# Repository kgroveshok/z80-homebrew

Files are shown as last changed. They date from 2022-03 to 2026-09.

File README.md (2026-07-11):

# z80-homebrew
Z80 Home Brew Micro-computer Project
------------------------------------

Having watched so many retro computing videos on YouTube I thought I would relive some of my youth
by building something simple. I remember the old electronic magazines of the 1980's which 
had plenty of simple programmable computing devices to make at home.  Always wanted one. Now I
will do it - only a few decades behind :-)

6502 vs Z80
-----------

My first home computer was a Vic20. Not long after having that in my grubby mitts I was writing
6502 machine code, hand assembling as we all did back then. Later I moved onto an Amstrad CPC464
and dived into Z80 which I then took to the Amstrad PCW 512.

Looking around at parts I found it hard to locate any good 6502 parts and with the vast
Z80 community and lots of great material to dust off my rusty electronics skills I chose that.

Therefore this project, is Z80 based. Turns out that is a good choice as the arch is very simple
with a load of great chips that tie closely together. Makes for an easier life.

Update: That said, with the PDIP Z80 now out of production so so great... But not completely lost :-)

Design Brief
------------

I thought I would add where I feel the design ideas have come from. First I love the Forth language
therefore as I say above taking the idea of the language driving the OS like in the Jupiter Ace, also
I love that case design, low profile, Sinclair like. Back in the day I had a ZX81 (which I still have)
but I also always wanted a Sharp handheld, saw one at school and thought such a cool thing, hence the 
completely self contained LCD display choice I went with. 

And working in a computer shop around 1987/88 I got to see a lot of different home micros and loved the
design of the Oric and MSX. I think my next 3D case I will print black and do orange/red keys.

Of course with the new 4.5 design I'm adding some features to make things easier such as Wifi. Hopefully
the tape interface will work though I've still got to finish writing the loading decoder. Saving was
working in the prototype.

Current Specification/Feature Set
---------------------------------

* Z80 4/8/10MHz
* 32K ROM
* 32K RAM
* PIO 1: Port A & B - Controlling LCD and keyboard:
   - Mini: 20x4 LCD and 4x4 matrix keypad 
   - Mega: 20x4 or 40x4 LCD and 50 key matrix keyboard
* PIO 2: Port A - Persistent storage via Microchip serial EEPROMs. 
   - Max 320K on board (5 x 64k). Currently set for 32k x 5. 
   - Uses own file system with max file size of 16k 
   - 5 banks of independant storage each with own bank label
* PIO 2: Port B - Exposed 8 bit bus and SPI bus. Used for more storage (512k/1024k), SPI devices or digital I/o
   - SPI0 - RJ45 socket configured for use with SPINet Add-on
   - SPI1 - ESP32 S3 for use as Wifi/extra storage/external comms, etc
* A 595 shift register bus array for any random junk you want to push such as a load of LED's or digital output on device G.
* Auto startup scripts/demos built into ROM and/or created on storage.
* Exposed RC2014 connector
* Built-in address decoder for four devices (2 used above)
* Tape support in progress on Device F.
* On board sound support on device B.
* Feature to load a user dictionary from file storage at boot time
* Highlevel and low level storage words
* Hardware abstraction layers to allow for common entry points and drivers for different keyboards, screens, etc
* Multiple selectable frame buffer support (currently three)
* Built-in Forth OS (inspired by Jupiter Ace). Language defintion and progress etc in FORTH.md
* Built-in full monitor for break points at all key points.
* Using my own very simple malloc/free routinues or can switch to DK88 project version with defines
* 3d printed case designs in 'case' directory.
* To aid in board development and speed up the change and test cycle I've now added support for running on the wonderful Steven Cousin's SC114 board. This is quicker than having to remove the EEPROM (even in a zif socket), burn it and put it back.
* Added CP/M support for even quicker test cyles via RunCPM!

Expansions/Addons
-----------------

* Not something I made, but an Adafruit Boost for on the go computing. Fits the case design on the right hand side. Should document that at some point.
* PicoSPINet - A Pico device which provides 5/6 SPI network ports allowing intercoms between nodes and act as an internet gateway.
   - Provides NTP services
   - Internode communications
   - Internet communications
   - Storage services
   - Powered nodes
   - Emulates the EEPROM used for onboard storage with node specific and common storage banks

   For more details look at the Addons README



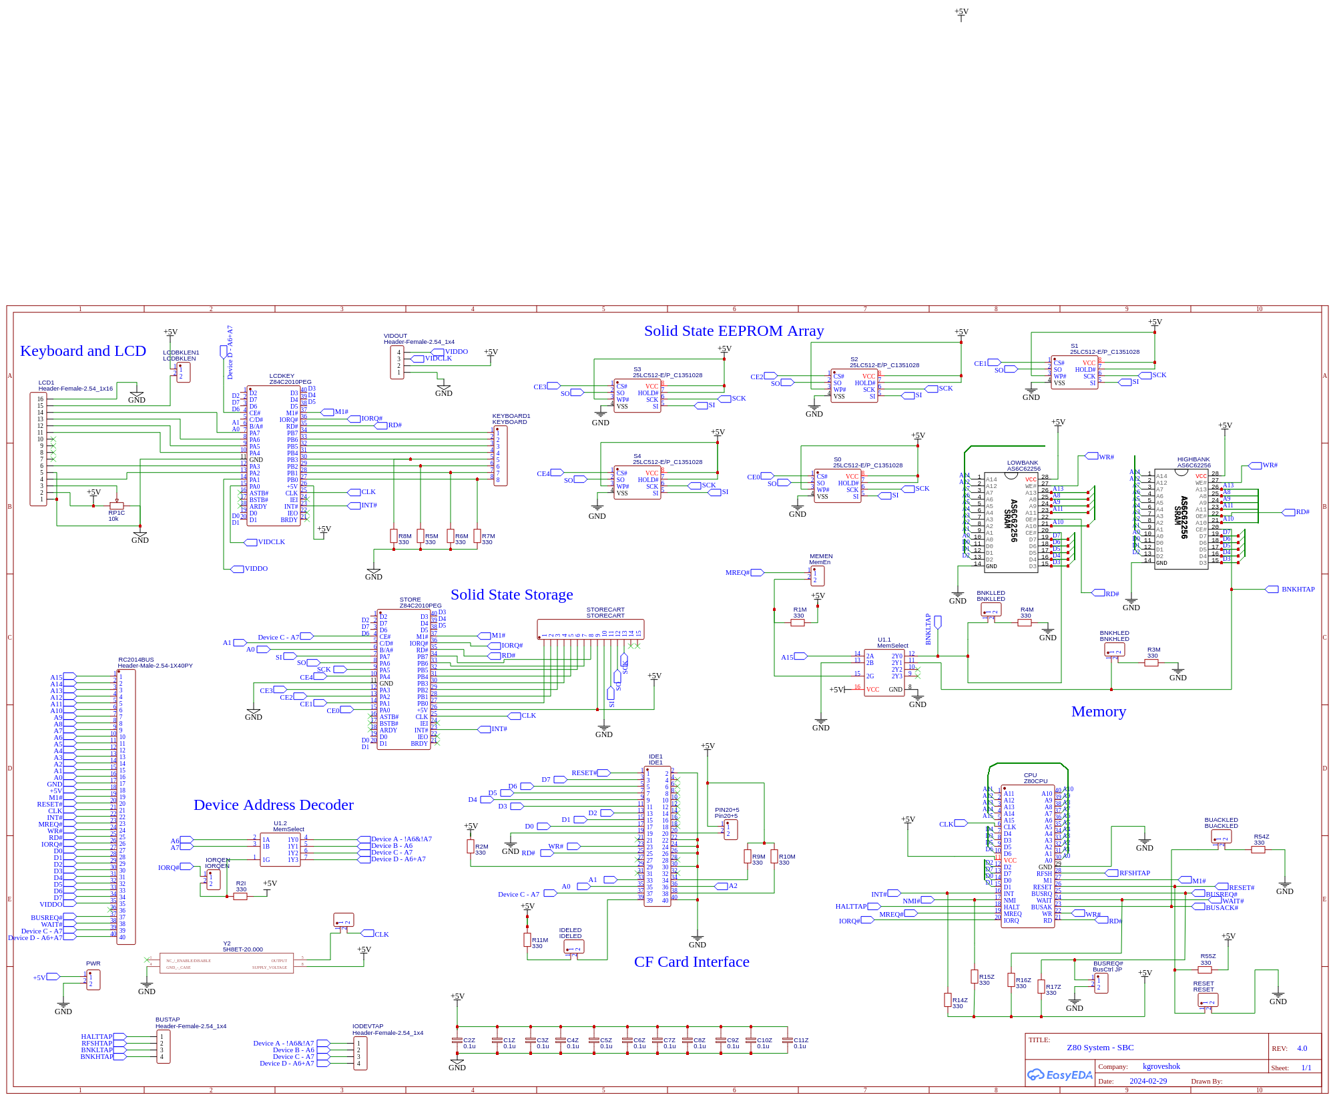
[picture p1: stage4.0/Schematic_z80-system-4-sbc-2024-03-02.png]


* SPISound - Using a shift reg and the classic SN76489 sound chip we have four channel sound via SPI.

   For more details look at the Addons README

Progress
--------

Check the DEV-DIARY.md for progress and what I learnt - spoiler, it is a lot!

Stage 1.x was very very basic using a Microchip PIC to bitbash code into RAM or manually as I didn't have an EEPROM programmer.

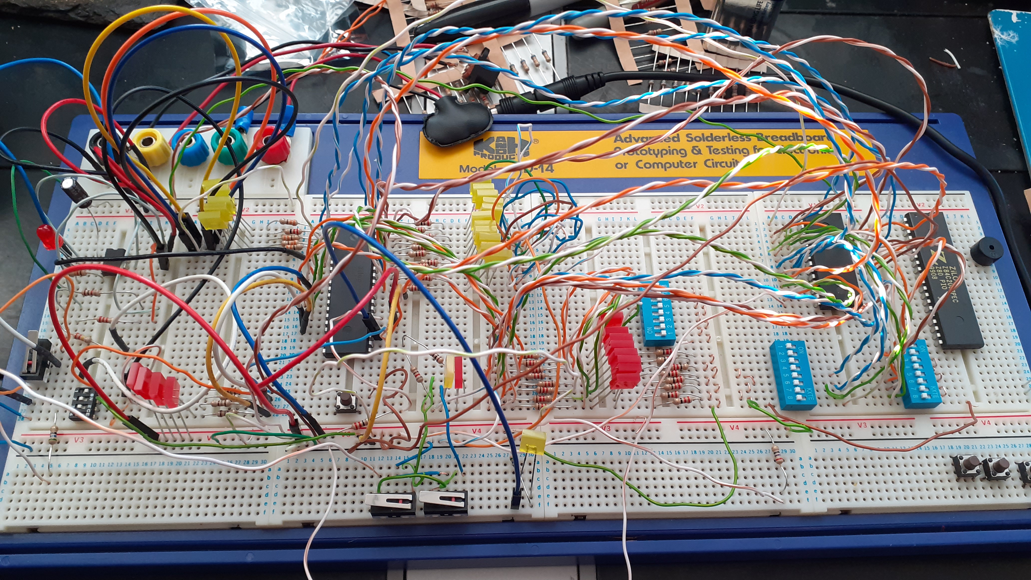
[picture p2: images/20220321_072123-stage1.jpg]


Stage 2.x got us to strip board in varying degrees of success

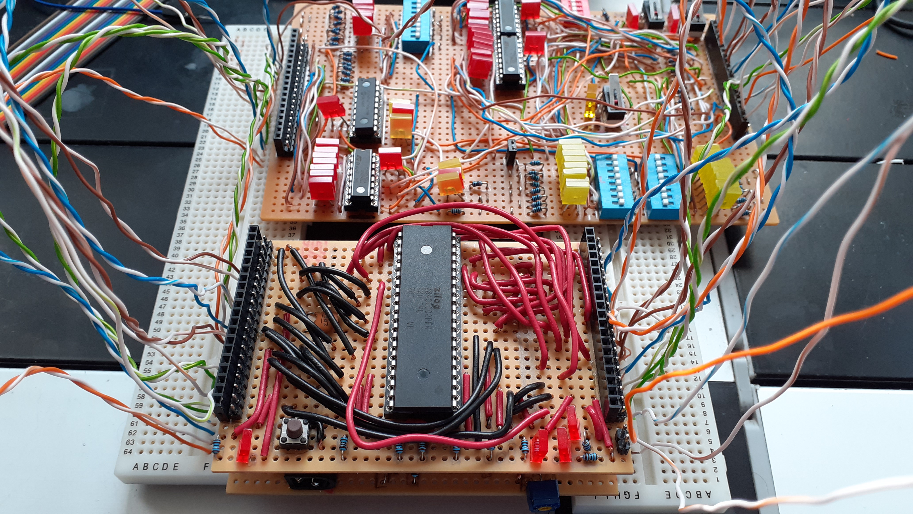
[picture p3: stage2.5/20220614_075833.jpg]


Stage 3.x with a propper PCB things are much more stable (and faster clock freq)...

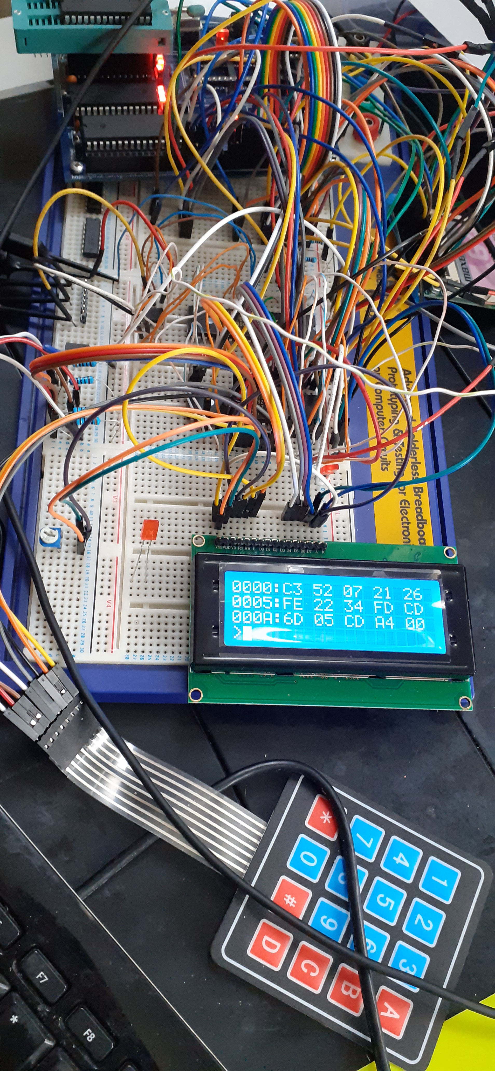
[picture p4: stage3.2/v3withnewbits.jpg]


Stage 4.x a useable machine now with many expandable features.

Current Forth word list in WORD-LIST.md along with how I have put together my version of FORTH in FORTH.md.

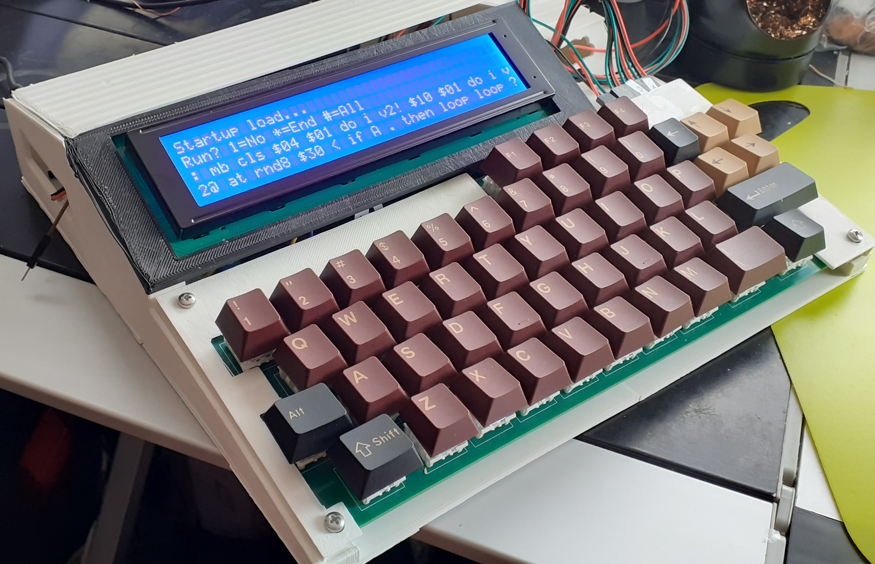
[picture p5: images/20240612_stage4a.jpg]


Stress testing FORTH OS

[https://youtu.be/hWfx7d5nqZw]

Stage 4.5 in June 2026 now has tape, sound, shift reg bus, and an ESP 32 on board!

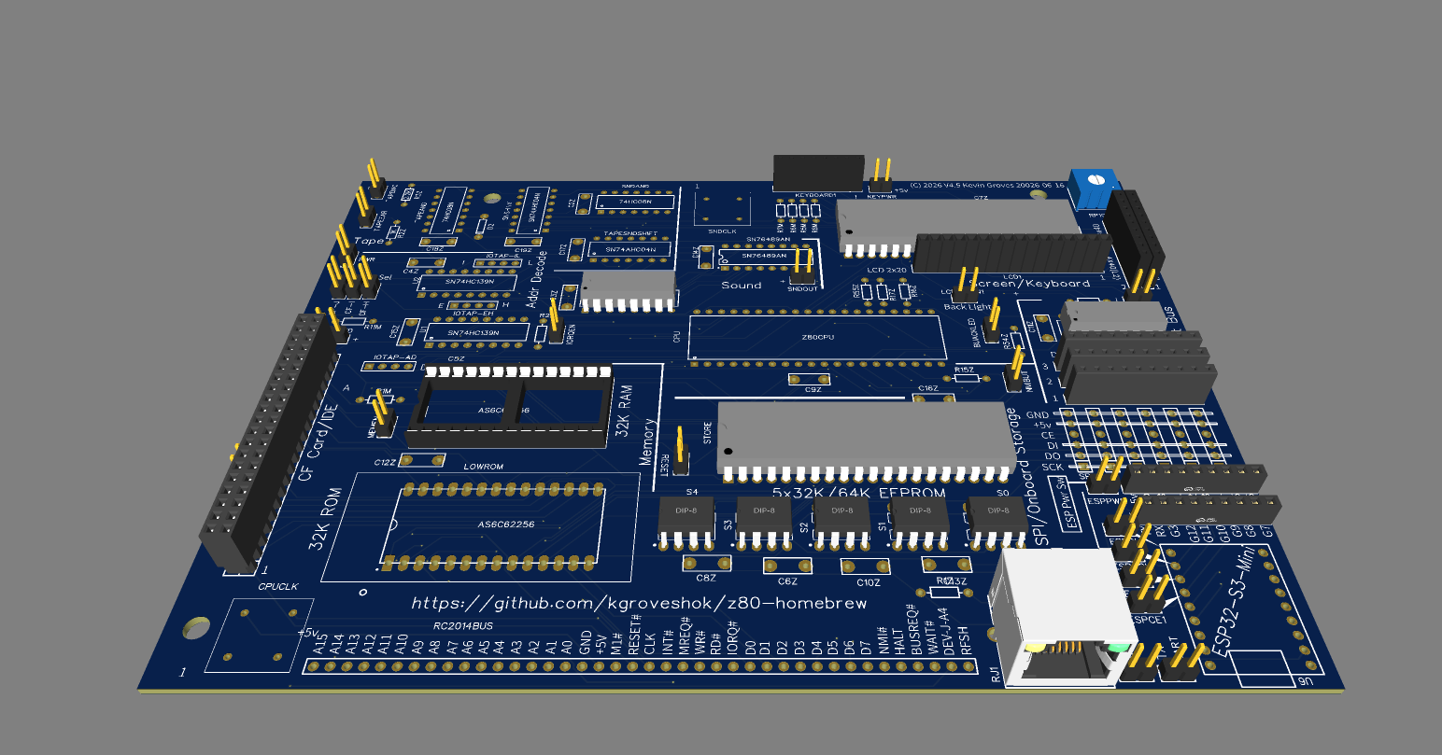
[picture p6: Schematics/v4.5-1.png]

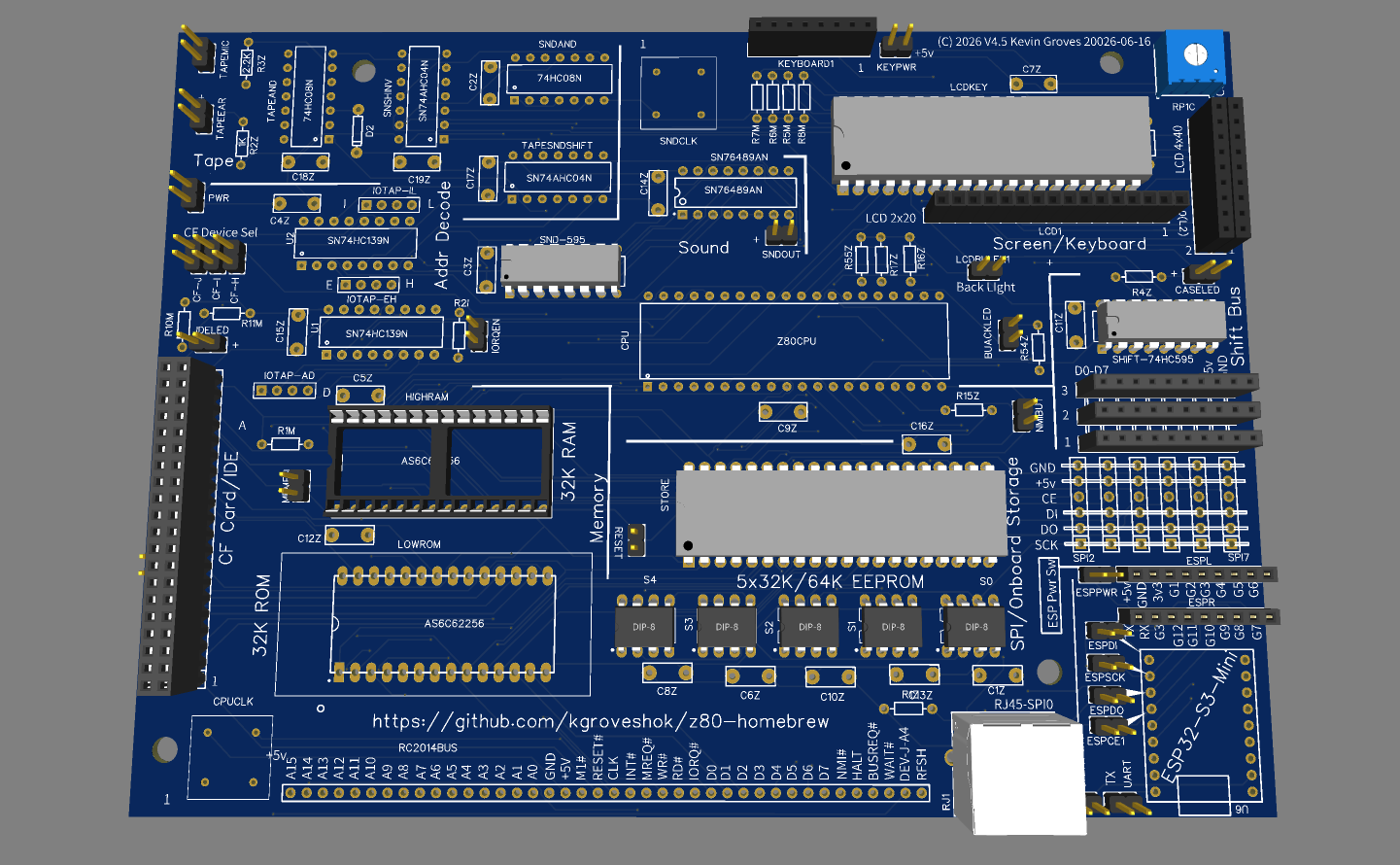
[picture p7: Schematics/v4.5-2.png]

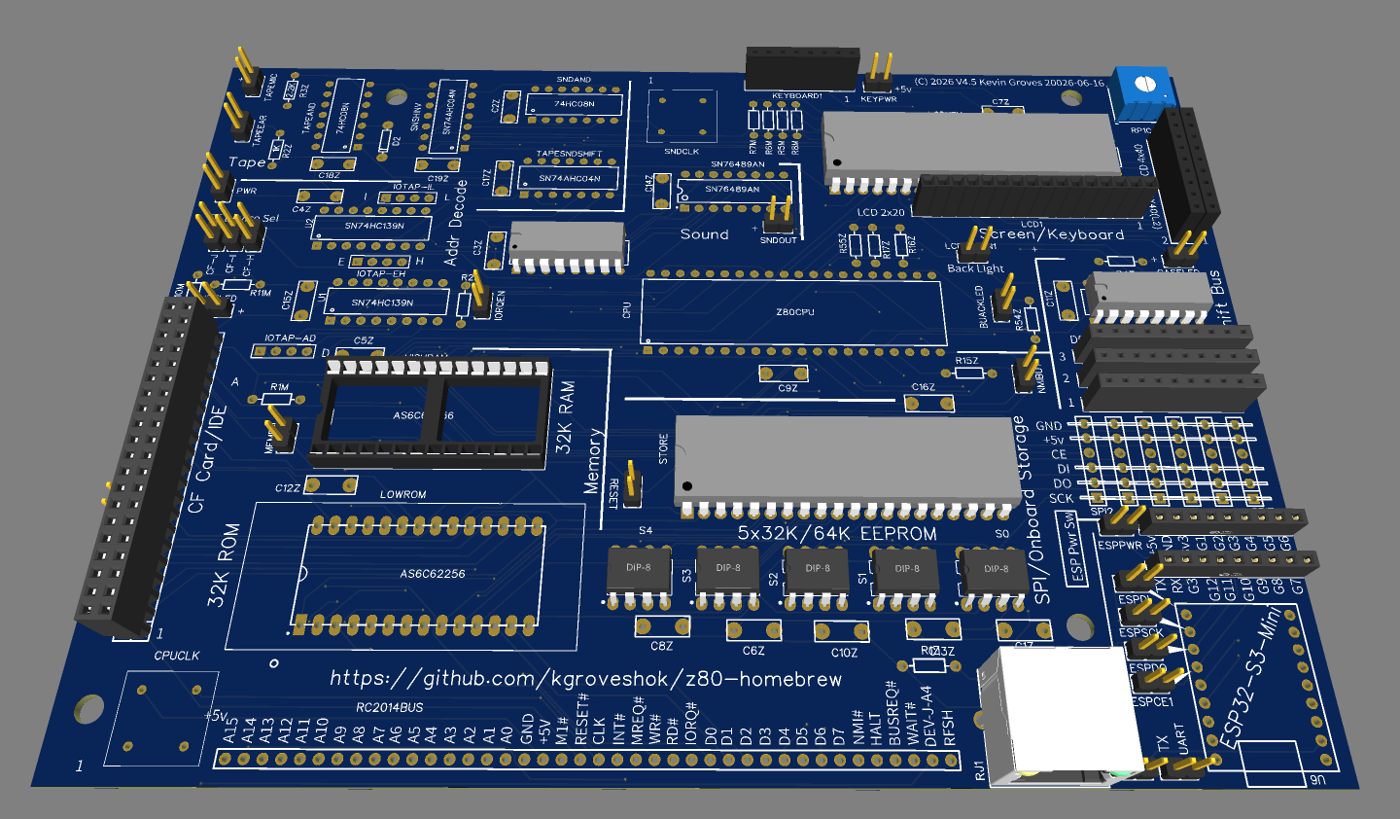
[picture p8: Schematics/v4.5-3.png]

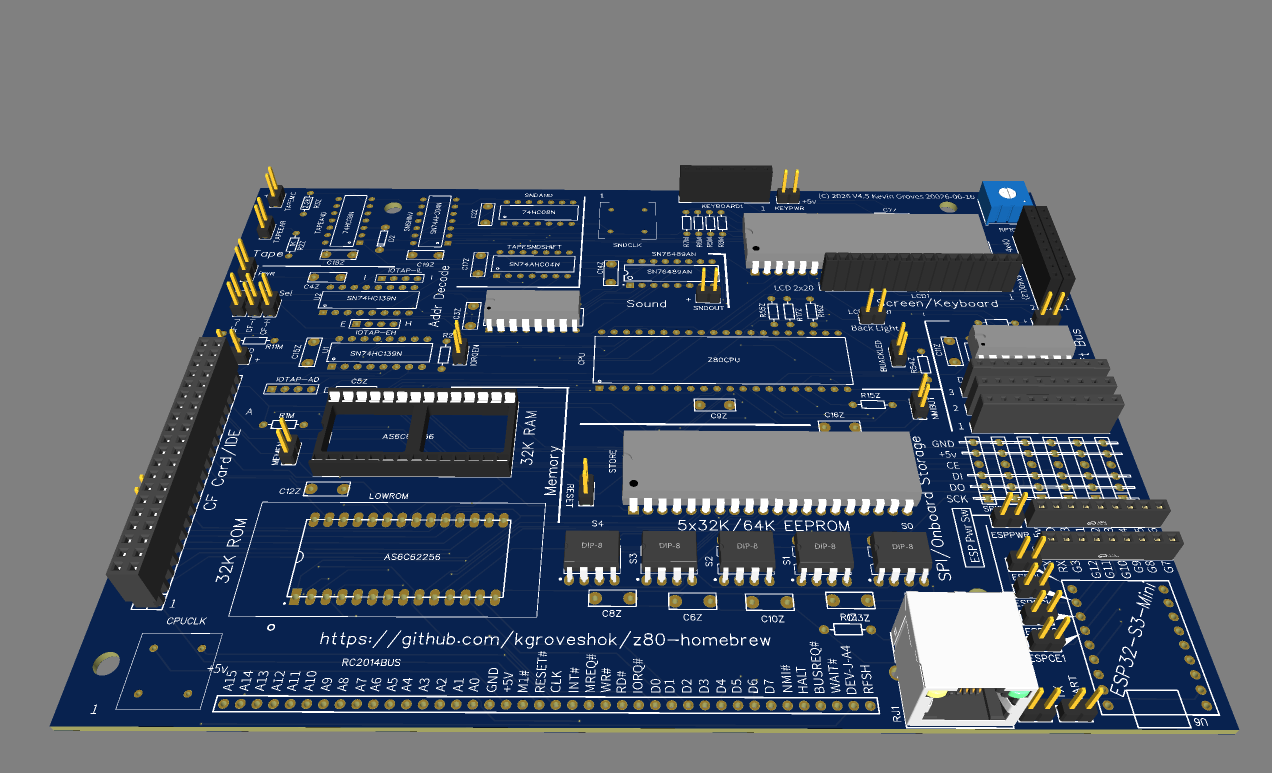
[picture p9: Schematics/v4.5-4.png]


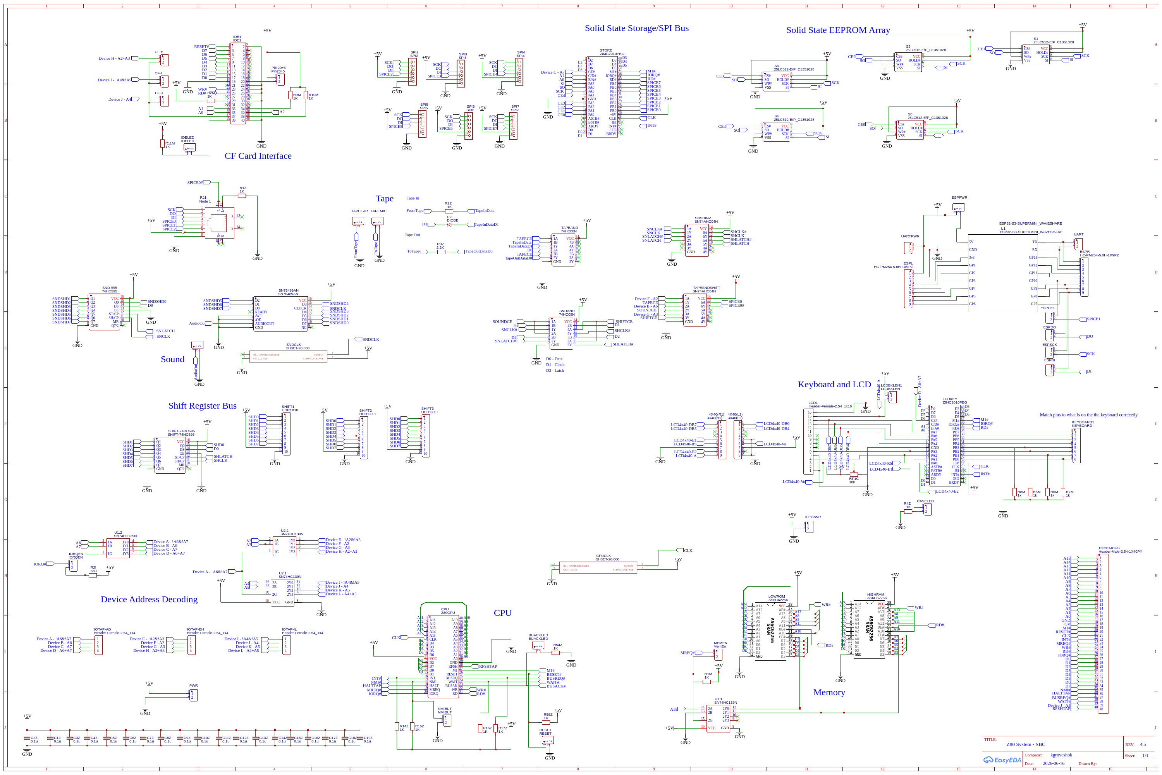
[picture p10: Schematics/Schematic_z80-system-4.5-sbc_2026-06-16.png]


Should fit in the existing case, but will redesign for a sleaker look like this...

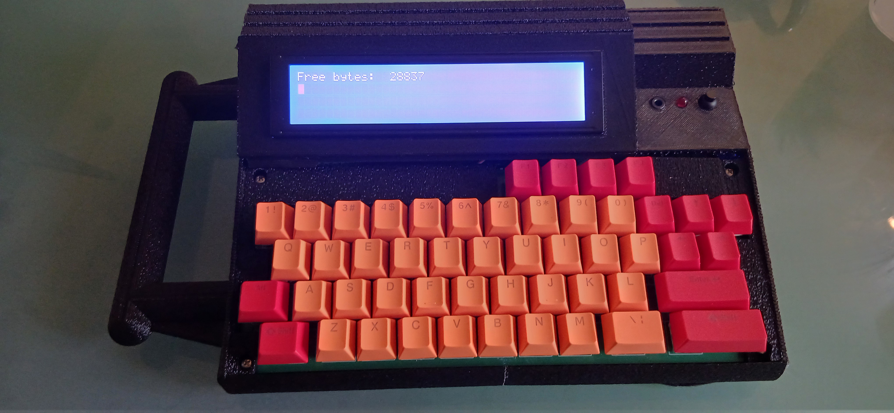
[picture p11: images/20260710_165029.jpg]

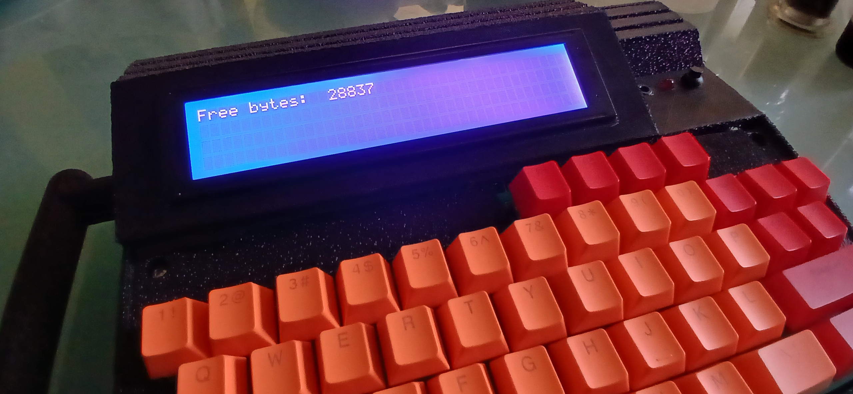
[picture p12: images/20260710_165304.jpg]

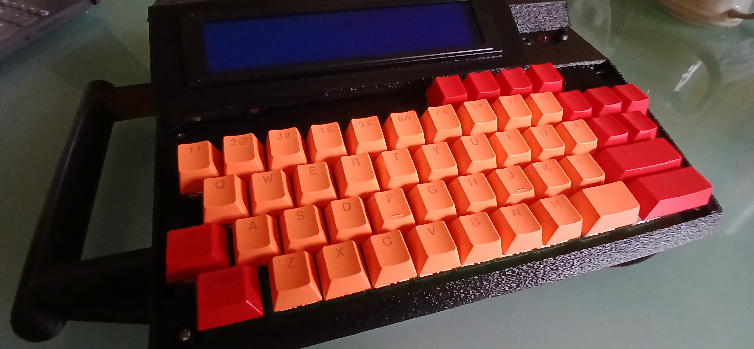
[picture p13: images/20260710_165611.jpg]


I was aiming for an Oric/MSX like colour scheme. Always wanted one of those back in the day.

A simple game of 'Simon Says'
-----------------------------

```
: sgen #1 do #1 #5 rnd dup #48 + i scratch ! .> bl .> loop ;
: isay #1 #0 scratch ! ; 
: nsay #0 scratch dup 1+! @ ;
: tsay #4 pause cls Your-go .- #10 #1 at accept ;
: schk #1 scratch #0 #0 scratch @ substr swap drop compare ;
: bsay "Your best was" #0 scratch @ #1 - num2str info ;
: ssay isay repeat cls nsay sgen tsay schk #1 = until bsay ;
```

[https://www.youtube.com/watch?v=0pCNQlxzYs0]

Parts
-----

At each stage I will document and attach the schematics for mostly for my own reference should things go wrong.

References
----------

I found so much great advice and inspiration around the net here are some of those that made the most
impact (in no particular order):

* [https://maker.pro/pic/projects/z80-computer-project-part-1-the-cpu]
* [https://www.electromaker.io/blog/article/z80-computer-memory]
* [https://www.youtube.com/watch?v=yR566HNj0ao]
* [https://bread80.com/category/couch-to-64k/]
* [https://maggi9295.github.io/projects/z80computer/z80computer.html]
* [http://www.breakintoprogram.co.uk/projects/homebrew-z80/homebrew-z80-computer-part-1]
* [https://incoherency.co.uk/blog/stories/rc2014-frontpanel.html]
* [https://www.instructables.com/An-Easy-to-Build-Real-Homemade-Computer-Z80-MBC2/]
* [https://sites.google.com/view/erics-projects/z-80-projects-page/z-80-pio-ps2-keyboard-interface]
* [http://www.cpuville.com/Projects/Standalone-Z80-computer/Standalone-Z80-home.html]
* [http://www.blunk-electronic.de/train-z/]
* [http://www.friendlywire.com/tutorials/pic-flash/]
* [http://www.waveguide.se/?article=programming-pics-using-the-pickit2-and-pk2cmd]
* [https://microcontrollerslab.com/74hc595-shift-register-interfacing-pic-microcontroller/]
* [https://www.electroschematics.com/multiple-shift-registers-arduino-part-1/]
* [https://z80project.wordpress.com/2015/07/06/z80-8-bit-compact-flash-card-interface-part-1/]
* [https://ciernioo.wordpress.com/2015/02/10/compact-flash-8255-interface-card/]
* [http://www.luke.maurits.id.au/projects/computers/lm512/]
* [https://github.com/monsonite/MINT]
* [https://github.com/antbern/z80-monitor]
* [https://github.com/fiskabollen/z80Monitor]
* [https://github.com/chapmajs/glitchworks_monitor]
* [http://ve7it.cowlug.org/cpm-monitor.html]
* [https://www.instructables.com/Z80-Monitor-Type-Operating-System-and-SBC/]
* [http://www.vaxman.de/projects/tiny_z80/]
* [https://smallcomputercentral.com/]
* [https://rc2014.co.uk/]

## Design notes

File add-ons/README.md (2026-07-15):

Add-ons/Expansion For Mega 
--------------------------

PicoNET - Wifi adaptor and/or networking hub
SPISound - A SPI controled sound card using a SN76389AN chip
ESP32Wifie - For the 4.5 version of the PCB we now have an onboard ESP handling extra storage and external comms

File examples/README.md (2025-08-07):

Examples
--------

There is a backup.txt file here which is a recent dump over PicoSPINet of my current development of words for use with the addons.

Of point is at the bottom with the various UBI... words which is incremental changes I made to dump the user dict over PicoSPINet to my laptop.

Each change I made I appended to a file and made it auto load so I can test it and not have to write it down. Now I have reached the working
version of UBIALL which works to connect to my laptop and dump the source of all current user words. Each word is displayed and then sent:

 ```
 piconet           <- Switches on the SPI device
 "192.168.9.110:8000" soccon       <- Tell PicoSPINet to make a socket connection to my laptop
 uwords ubiall                <- Push al user words to stack and then iterate over the list sending them via the socket connection via SPI
 ```

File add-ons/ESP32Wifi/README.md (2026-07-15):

ESP32Wifi
---------

With the 4.5 board revision I've added an ESP32 Zero device to provide a number of features. It is communicated via the SPI device 1. Device 0 
continues support for SPINet in case that is useful for wired networking once the code base has been resolved.

As this device is a one to one connection for an IP network, that simplifies the range of features it needs to have.

Programming can be one of three options on the ESP.
1. Using C via the main SDK
2. Arduino code
3. ESPForth

I will give ESPForth a go first. A bit of a learning curve but considering the OS is in Forth then why not have all of it in the same
language? We will see. :-) 

As it happens, had issues with ESPForth and the ESP S3 Zero I'm using. Wouldn't conenct to Wifi with: wifi z" <ssid>" z" <pass>" login

Would just hang. The Arduino IDE wifi SDK is working so will be using that instead as the code is easy to port between that and Forth. May revisit as some time.

* TODO Could add mailbox on web server
* TODO Can I get esp to send email
* TODO Set output pin to input to force high imped and to not corrupt the SPI bus once done.
* TODO setup inter-esp comms for a mesh network to share files
* TODO Put a scope on the SPI lines and decode what is going wrong with EEPROM support

SPI Command Protocol
--------------------

The revised protocol functions at two levels. There is a main class of command byte e.g. wifi services, and then a sub command byte which gives the function.

Please look at the esp-spi-op.h file for the function list. Once it has become stable then a more detailed version will be included here.

ESP Command Operators
----------------------

To aid in removing duplicate code I have implemented an "interpreter" that has a number of simple op codes (see esp-z80-op.h) that form simple features common to all commands e.g. get a byte, put a byte, store something, etc

Likewise from above, once the OP code list has become stable then there will be more detail here. But the naming should be fairly easy to understand.

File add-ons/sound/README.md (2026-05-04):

On Board Sound
--------------

The SPI sound add-on is OK. But would be better if on the main board. With tape support in progress there is only one 
device remaining free without any additional address decoding logic.

Will attempt another go at hooking up the sound chip to device B and including on the main board.

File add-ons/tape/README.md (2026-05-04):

Tape Format
-----------

Trying a combination of pulse counts vs pulse lengths.

As this platform is inspired by the Jupiter Ace then would seem natural to use the ZX-81 tape approach, though it is the most 
unreliable one being just an RC circuit rather than making use of something like KCS or other reliable frequency detection
circuits.

It is a very easy circuit to put together but requires a tight firmware loop for decoding. I had hoped to provide a
Forth implentation but due to interp and guard rails in the OS it isn't fast enough. But there is a TAPESET word that
will allow tweaking for the params.

Objective is to have some words that can save random strings (which could be uwords) as well as a whole user 
dicitionary dump to tape.

Prototype
---------

The add-on for the moment will remain as a strip/bread board solution and once reliable enough (within reason) 
I will include on the main board as the board needs reworking from previous changes.

Development/Testing
-------------------

When time allows samples and screen shots of development will be included.

For source see firmware_tape.asm

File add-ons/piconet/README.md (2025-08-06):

PicoSPINet
----------

* PicoSPINet - A Pico device which provides 5/6 SPI network ports allowing intercoms between nodes and act as an internet gateway.
   - Provides NTP services
   - Internode communications
   - Internet communications
   - Storage services
   - Powered nodes
   - Emulates the EEPROM used for onboard storage with node specific and common storage banks

More to come with PCB design etc

Demo of the prototype:

[https://youtu.be/h5VUJ3j9RmY]

Example comms
-------------

* Connecting to a remote server

 On remote machine:    nc -klv 192.168.9.101 8000

 On Mega:

    * Create socket connection

    $22 spio "192.168.9.101:8000" spistrz 

    * Send ASCII char $65

    $20 spio $65 spio

    * Get back a character from the remote machine

    $21 spio $01 pause spii emit

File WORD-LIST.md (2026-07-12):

# Forth Language Reference

Also refer to the auto start list examples as these contain extra words created at runtime as needed
## Constants (i.e. Useful memory addresses that can set or get features)
### SPITIME ( -- u1 )   Pushes address of the SPI pulse counter/delay to stack | DONE
 If using BANK devices then leave as is.
 Only really useful for the CARTDEV where other devices may be far too slow. In particular
 the multiplexing of the PicoSPINet addon which might not be running fast enough for all of the nodes
### VA ( -- u1 )   Pushes address of block of memory used for v1..5 | DONE
### SYMBOL ( u1 -- )  Get the address of a system symbol from a look up table to TOS  | DONE

 The value is the number reference and the final address is pushed to stack
 ```
 dw sym_table
 dw nmi_vector
 dw cli_autodisplay
 dw cli_data_sp
 dw cli_data_stack
 dw cli_loop_sp
 dw cli_loop_stack
 dw cli_var_array
 dw cursor_col
 dw cursor_ptr
 ; 10
 dw cursor_row
 dw debug_mark
 dw display_fb0
 dw display_fb1
 dw display_fb2
 dw display_fb3
 dw display_fb_active
 dw execscratch
 dw f_cursor_ptr
 dw hardware_word
 ;20
 dw input_at_cursor
 dw input_at_pos
 dw input_cur_flash
 dw input_cur_onoff
 dw input_cursor
 dw input_display_size
 dw input_len
 dw input_ptr
 dw input_size
 dw input_start
 ; 30
 dw input_str
 dw input_under_cursor
 dw os_cli_cmd
 dw os_cur_ptr
 dw os_current_i
 dw os_input
 dw os_last_cmd
 dw os_last_new_uword
 dw debug_vector
 dw os_view_hl
 ;40
 dw os_word_scratch
 dw portbctl
 dw portbdata
 dw spi_cartdev
 dw spi_cartdev2
 dw spi_clktime
 dw spi_device
 dw spi_device_id
 dw spi_portbyte
 dw stackstore
 ; 50
 if STORAGE_SE
 dw storage_actl
 dw storage_adata
 else
 dw 0
 dw 0
 endif
 dw storage_append
 if STORAGE_SE
 dw storage_bctl
 else
 dw 0
 endif
 dw store_bank_active
 dw store_filecache
 dw store_longread
 dw store_openaddr
 dw store_openext
 dw store_openmaxext
 ; 60
 dw store_page
 dw store_readbuf
 dw store_readcont
 dw store_readptr
 dw store_tmpext
 dw store_tmpid
 dw store_tmppageid
 dw malloc
 dw free
 dw cin
 ; 70
 dw cin_wait
 dw forth_push_numhl
 dw forth_push_str
 dw parse_vector
 dw tape_port
 ```
## Core Words
### NMICLR ( -- ) Clears the use of the NMI switch | DONE
### NEW ( -- ) Clears all user words and stack | DONE
### HEAP ( -- u1 u2 )   Pushes u1 the current number of bytes in the heap and u2 the remaining bytes - Only present if using my MALLOC | DONE
 u1 - Current number of bytes in the heap
 u2 - Remaining bytes left on the heap
 
 The heap is used for storing user defined words as well as any values pushed to stack.
### DUP ( u -- u u )     Duplicate whatever item is on TOS | DONE
 >[!NOTE]
 > If the duplicated item is a string it is safely duplicated
### ?DUP ( u -- u u )     Duplicate item on TOS if the item is non-zero (Only works for numerics) | DONE
 >[!NOTE]
 > If the duplicated item is a string it is not safely duplicated and remain as pointer to the origin
### DMARK ( s --  )  Set the debug marker id to first three chars of s | DONE
 Most useful for tracing your code for errors as you can set various markers to display when MONITOR is called
### LSHIFT ( w -- w )    16 bit left shift | DONE
### RSHIFT ( w -- w )    16 bit right shift | DONE
### SWAP ( w1 w2 -- w2 w1 )    Swap top two items on TOS | DONE
### : ( -- )         Create new word | DONE
### ; ( -- )     Terminate new word and return exec to previous exec level | DONE
### DROP ( w -- )   drop the TOS item   | DONE
### 2DUP ( w1 w2 -- w1 w2 w1 w2 ) Duplicate the top two items on TOS  (Only works for numerics) | DONE
 >[!NOTE]
 > If the duplicated items are string pointers, string are not safely duplicated and remain as pointers to the origin
### 2DROP ( w w -- )    Double drop | DONE
### PICK ( ux ... u x -- ux ... u n )    Replace x on stack with the item from position x on stack  | DONE
 >[!NOTE]
 > If the chosen item is a string the pointer is pushed to TOS. The string is not safely duplicated.
### 2SWAP ( w1 w2 w3 w4 -- w3 w4 w1 w2 ) Swap top pair of items | DONE
### @ ( w -- ) Push onto TOS byte stored at address   | DONE
### C@  ( w -- ) Push onto TOS byte stored at address   | DONE
### ! ( x w -- ) Store x at address w      | DONE
### C!  ( x w -- ) Store x at address w  | DONE
### CALL ( w -- w  ) machine code call to address w  push the result of hl to stack | DONE
### DEPTH ( -- u ) Push count of stack | DONE
### OVER ( n1 n2 -- n1 n2 n1 )  Copy one below TOS onto TOS | DONE
 >[!NOTE]
 > If the copied item is a string it is properly duplicated allowing for a safe release after use. 
### PAUSEMS ( n -- )  Pause for n millisconds | DONE
### PAUSE ( n -- )  Pause for n seconds | DONE
### ROT ( u1 u2 u3 -- u2 u3 u1 ) Rotate top three items on stack | DONE
### UWORDS (  -- s1 ... sn u )   List user word dict | DONE
 After use the TOS will have a count of the number of user words that have been pushed to stack.
 Following the count are the individual words.

 e.g. UWORDS
 BOX DIRLIST 2
 
 Can be used to save the words to storage via:
 UWORDS $01 DO $01 APPEND LOOP
### BP ( u1 -- ) Enable or disable break point monitoring | DONE
 $00 Will enable the break points within specific code paths
 $01 Will disable break points
 
 By default break points are off. Either the above can be used to enable them
 or if a key is held down during start up the spashscreen will appear to freeze
 and on release of the pressed key the CONFIG menu will be displayed where you
 can disable break points. Exiting will then continue boot process.
### MONITOR ( -- ) Display system breakpoint/monitor | DONE
 At start the current various registers will be displayed with contents.
 Top right corner will show the most recent debug marker seen.
 The bottom of the screen will also show the values of the data stack pointer (DSP)
 and the return stack pointer (RSP).
 Pressing:
 
    1 - Initial screen
 
    2 - Display a data dump of HL
 
    3 - Display a data dump of DE
 
    4 - Display a data dump of BC
 
    5 - Display a data dump of HL
 
    6 - Display a data dump of DSP
 
    7 - Display a data dump of RSP
 
    8 - Display a data dump of what is at DSP
 
    9 - Display a data dump of what is at RSP
 
    0 - Exit monitor and continue running. This will also enable break points
 
    * - Disable break points
 
    # - Enter traditional monitor mode

 Monitor Mode
 ------------
 A prompt of '>' will be shown for various commands:
 
    D xxxx - Display a data dump starting from hex address xxxx
 
    C - Continue display a data dump from the last set address
 
    M xxxx - Set start of memory edit at address xx
 
    U xx - Poke the hex byte xx into the address set by M and increment the address to the next location
 
    G xxxx - Exec code at specific address
 
    Q - Return to previous
### ALLOT ( u -- u ) Allocate u bytes of memory space and push the pointer TOS  | DONE
### MALLOC ( u -- u ) Allocate u bytes of memory space and push the pointer TOS  | DONE
### FREE ( u --  ) Free memory block from malloc given u address  | DONE
### UPTR ( s -- u ) Push the address of the exec code for the quoted used word s  | DONE
### LIST ( uword -- u )    List the code to the word that is quoted (so as not to exec) on TOS | DONE
 The quoted word must be in upper case.
### FORGET ( uword -- )    Forget the uword on TOS | DONE
 Will flag the word's op code to be deleted as well as replace the first char of the word with '_'. Quoted uword name must be in caps.
 
 e.g. "MORE" forget
### NOP (  --  ) Do nothing | DONE
### ( ( -- )  Start of comment | DONE
### ) ( -- )  End of comment |  DONE 
### SCRATCH ( u -- addr ) Pushes address of offset u to stack | DONE
 The scratch area provides 32 word array. Can be used as single byte or as a word by passing the offset on stack. Pushes the resulting address to stack. 
 When used with the direct storage writing/malloc and the !@ or word versions it is possible to construct an expanded and flexible variable system
 
 e.g.    : score $00 scratch ;
 
 $00 score !
 $01 score +!
 
 e.g.   : varword $0a scratch ; 

 $8000 varword !
### +! ( u a -- )  Increment byte at address a by the value u | DONE
### -! ( u a -- )  Decrement byte at address a by the value u | DONE
### +2! ( u a -- )  Increment word at address a by the value u | DONE
### -2! ( u a -- )  Decrement word at address a by the value u | DONE
### 2@ ( a -- u )  Push word at address a onto stack | DONE
### 2! ( u a -- )  Store value u as a word at address a | DONE
### CONFIG ( -- )  Access the system configuration menu. Set boot from file, hardware diags, and more! | DONE
### 1+ ( u -- u )  Increment value on TOS | DONE
### 1- ( u -- u )  Decrement value on TOS | DONE
### 1+! ( addr -- )  Increment byte at address addr | DONE
### 1+2! ( addr -- )  Increment word at address addr | DONE
### 1-! ( addr -- )  Decrement byte at address addr | DONE
### 1-2! ( addr -- )  Decrement word at address addr | DONE
## Device Words
### DEVSAV ( --  )  Saves the current BANK/CARTDEV settings in case you want to switch device suddenly. i.e. use ESP | DONE
### DEVREST ( --  )  Restores the last saved BANK/CARTDEV settings in case you want to switch device suddenly. i.e. use ESP | DONE
### SR ( u p --  )  Send byte u to shift reg on port p | DONE
### LED ( u --  )  Set case LED on or off | DONE
### NB ( u --  )  Sends a note byte to sound card  TODO
### SETTAPE ( port gap samples hpulse lpulse high low -- )   Set parameters for tape support | DONE
 port - Device address port; default is Device A on 00h
 samples - How many sample cycles to count pulses
 gap - Gap period counter; default is 250
 hpulse - Count of pulses for 1; default is 6
 lpulse - Count of pulses for 0; default is 2
 high - High bit period counter; default is 150
 low - Low bit period counter; default is 50
### SAVES ( s1 ... sn c n -- )    Save a count of c strings using file name of n to tape | DONE
### SAVE ( n -- )    Save all uuser words to tape with given name n | TO DO
### LOAD ( n -- )    Load file n from tape and exec | TO DO
### TAPECAL (  -- )    Listen to a tape header and report on bit detection pulses | TO DO
### TAPETEST (  -- )    Record a repeating stripe pattern of 0 and 1 for testing record and playback via TAPECAL | TO DO
### IN ( u1 -- u )    Perform Z80 IN with u1 being the port number. Push result to TOS | DONE
### OUT ( u1 u2 -- ) Perform Z80 OUT to port u2 sending byte u1 | DONE
### SPICEL ( -- ) Set SPI CE low for the currently selected device |  DONE
### SPICEH ( -- ) Set SPI CE high for the currently selected device |  DONE
### SPIO ( u1 -- ) Send byte u1 to SPI  |  DONE
### SPII ( -- u1 ) Get a byte from SPI  | DONE
### BANK? ( -- u ) Reports on the serial EEPROM Bank Device at bank address u1 1-5.  | DONE
 Zero is disabled storage.
### BANK ( u1 -- ) Select Serial EEPROM Bank Device at bank address u1 1-5 (disables CARTDEV).  | DONE
 Set to zero to disable storage.
### CARTDEV ( u1 -- ) Select cart device 1-8 (Disables BANK). | DONE
 Set to zero to disable devices.
## Display Words
### ACTIVE ( -- s ) Push the next char for an activity indicator to TOS | DONE
 To display a pulsing activity indicator in a processing loop do this...
 e.g. $ff $00 do active . ..... Your code ..... loop
### INFO ( u1 u2 -- )  Use the top two strings on stack to fill in an info window over two lines. Causes a wait for key press to continue. | DONE
### AT? ( -- c r )  Push to stack the current position of the next print | TO TEST
### FB ( u -- ) Select frame buffer ID u (1-3)  |  DONE
 Default frame buffer is 1. System uses 0 which can't be selected for system messages etc.
 Selecting the frame buffer wont display unless automatic display is setup (default).
 If automatic display is off then updates will not be shown until DRAW is used.
###  EMIT ( u -- ) Display ascii character  TOS   | DONE
### .- ( u -- ) Display TOS replacing any dashes with spaces. Means you dont need to wrap strings in double quotes!   | DONE
### .> ( u -- ) Display TOS and move the next display point with display  | DONE
### . ( u -- ) Display TOS. Does not move next print position. Use .> if you want that. | DONE
### CLS ( -- ) Clear current frame buffer and set next print position to top left corner  | DONE
### DRAW ( -- ) Draw contents of current frame buffer  | DONE
### DUMP ( x -- ) With address x display dump   | DONE
### CDUMP ( -- ) Continue dump of memory from DUMP | DONE
### AT ( u1 u2 -- ) Set next output via . or emit at row u2 col u1 | DONE
### HOME ( -- ) Reset the current cursor for output to home | DONE
### CR (  -- s ) Push CR/LF pair onto the stack as a string  | DONE
### BL (  -- c ) Push the value of space onto the stack as a string  | DONE
### SPACES ( u -- str ) A string of u spaces is pushed onto the stack | DONE
### SCROLL ( -- ) Scroll up one line - next write will update if required | DONE
### SCROLLD ( -- ) Scroll down one line - next write will update if required | TO DO
### AT@ ( u1 u2 -- n ) Push to stack ASCII value at row u2 col u1 | DONE
### ADSP ( u1 --  ) Enable/Disable Auto screen updates (SLOW). | DONE
 If off, use DRAW to refresh. Default is on. $0003 will enable direct screen writes (TODO) 
### MENU ( u1....ux n -- n ) Create a menu. n is the number of menu items on stack. Push number selection to TOS | DONE
## Program Flow Words
### IF ( w -- f ) If TOS is true exec code following up to THEN  | DONE
 Note: currently not supporting ELSE or nested IF
### THEN ( -- ) Does nothing. It is a marker for the end of an IF block | DONE
### ELSE ( -- ) Not supported - does nothing | TODO
### DO ( u1 u2 -- ) Loop starting at u2 with a limit of u1 | DONE
### LOOP ( -- ) Increment and test loop counter  | DONE
### I ( -- ) Current loop counter | DONE
### -LOOP ( -- ) Decrement and test loop counter  | DONE
### REPEAT ( --  ) Start REPEAT...UNTIL loop  | DONE
### UNTIL ( u -- ) Exit REPEAT...UNTIL loop if TOS is false  | DONE
## Keyboard Words
### MACRO ( s u -- ) Maps a string s against a key code u for use in the editor functions (CLI/EDIT/ACCEPT)  | TODO
### KEY ( -- u ) A non-blocking read of keypress | DONE
 The ASCII key (or key code) is pushed to stack. If no key is currently held down then push a 0
 Can use something like this to process:
 > repeat active . key ?dup if emit then #1 until 
### KEYDB ( -- u ) A non-blocking read of keypress with key release debounce | DONE
 The ASCII key (or key code) is pushed to stack. If no key is currently held down then push a 0
 Can use something like this to process:
 > repeat active . key ?dup if emit then #1 until 
### WAITK ( -- w ) Wait for keypress TOS is key press | DONE
### ACCEPT ( -- w ) Prompt for text input and push pointer to string | DONE
### EDIT ( u -- u ) Takes string on TOS and allows editing of it. Pushes it back once done. | DONE
### DEDIT ( ptr --  ) Takes an address for direct editing in memory. | DONE
## Logic Words
### AND ( u1 u2  -- u3 ) u3 is logical AND of u1 with u2 | DONE
### OR ( u1 u2  -- u3 ) u3 is logical OR of u1 with u2 | DONE
### NOT ( u  -- u ) Inverse true/false on stack | DONE
### COMPARE ( s1 s2  -- f ) Push true if string s1 is the same as s2 | DONE
### 0< ( u -- f ) Push true if u is less than o | CANT DO UNTIL FLOAT
### 0= ( u -- f ) Push true if u equals 0 | DONE
### < ( u1 u2 -- f ) True if u1 is less than u2 | DONE
### > ( u1 u2 -- f ) True if u1 is greater than u2 | DONE
### = ( u1 u2 -- f ) True if u1 equals u2 | DONE
## Maths Words
### + ( u u -- u )    Add two numbers and push result   | INT DONE
### - ( u1 u2 -- u )    Subtract u2 from u1 and push result  | INT DONE
### / ( u1 u2 -- result remainder )     Divide u1 by u2 and push result | INT DONE
### * ( u1 u2 -- u )     Multiply TOS and push result | INT DONE
### MIN (  u1 u2 -- u3 ) Whichever is the smallest value is pushed back onto the stack | DONE
### MAX (  u1 u2 -- u3 )  Whichever is the largest value is pushed back onto the stack | DONE
### RND16 (  -- n ) Generate a random 16bit number and push to stack | DONE
### RND8 (  -- n ) Generate a random 8bit number and push to stack | DONE
### RND ( u1 u2 -- u ) Generate a random number no lower than u1 and no higher than u2 and push to stack | DONE
## Fixed Storage Words
### RENAME ( s id -- ) With the current bank, rename the file id with the new label s  | DONE
 > [!NOTE]
 > Compatible with PicoSPINet 
### RECORD ( u id -- s ) With the current bank, read record number u from file id and push to stack  | DONE
 > [!NOTE]
 > Compatible with PicoSPINet 
### BREAD ( u -- u ) Lowlevel storage word. With the current bank, read a block from page id u (1-512) and push to stack  | DONE
 > [!NOTE]
 > Compatible with PicoSPINet 
### BWRITE ( s u -- ) Lowlevel storage word. With the current bank, write the string s to page id u | DONE
 > [!NOTE]
 > Compatible with PicoSPINet 
### BUPD ( u -- ) Lowlevel storage word. Write the contents of the current file system storage buffer directly to page id u | DONE
 Coupled with the use of the BREAD, BWRITE and STOREPAGE words it is possible to implement a direct
 or completely different file system structure.
 > [!NOTE]
 > Compatible with PicoSPINet 
### GETID ( s -- u ) Get the file ID in the current BANK of the file named s | DONE
 > [!NOTE]
 > Compatible with PicoSPINet 
### DIR ( u -- lab id ... c t ) Using bank number u push directory entries from persistent storage as w with count u  | DONE
 > [!NOTE]
 > Compatible with PicoSPINet 
### SEO ( u1 u2 -- ) Send byte u1 to Serial EEPROM device at address u2 | DONE
### SEI ( u2 -- u1 ) Get a byte from Serial EEPROM device at address u2 | DONE
### FFREE ( -- n )  Gets number of free file blocks on current storage bank | DONE
 > [!NOTE]
 > Compatible with PicoSPINet 
### SIZE ( u -- n )  Gets number of blocks used by file id u and push to stack | DONE
 > [!NOTE]
 > Compatible with PicoSPINet 
### CREATE ( u -- n )  Creates a file with name u on current storage bank and pushes the file id number to TOS | DONE
 e.g. 
 TestProgram CREATE
 Top of stack will then be the file ID which needs to be used in all file handling words
 
 Max file IDs are 255.
 
 > [!NOTE]
 > Compatible with PicoSPINet 
### APPEND ( u n --  )  Appends data u to file id on current storage bank | DONE
 e.g.
 Test CREATE      -> $01
 "A string to add to file" $01 APPEND
 
 The maximum file size currently using 32k serial EEPROMS using 64 byte blocks is 15k.
 > [!NOTE]
 > Compatible with PicoSPINet 
### ERA ( n --  )  Deletes all data for file id n on current storage bank | DONE
 > [!NOTE]
 > Compatible with PicoSPINet 
### OPEN ( n -- n )  Sets file id to point to first data page for subsequent READs. Pushes the max number of blocks for this file | DONE
 e.g.
 $01 OPEN $01 DO $01 READ . LOOP

 Will return with 255 blocks if the file does not exist
 > [!NOTE]
 > Compatible with PicoSPINet 
### READ ( -- n  )  Reads next page of current file id and push to stack | DONE
 e.g.
 $01 OPEN $01 DO READ . LOOP

 As this word only reads one 64 byte block in at a time, if the APPEND word has created extra blocks for the excess, this READ
 word is unaware so the long string needs to be joined if the string is a full. A single block read might be what you want,
 but if not then writing a word to join blocks will be required. The upshot is a full string will be 62 bytes as the first
 two bytes contain the file id and extent.
 
 Note: There is a flag that enables/disables long block reads called 'store_longread' and a poke of a non-zero value will
 enable the code to automatically read futher blocks if full. It is BUGGY so don't use for now.
 > [!NOTE]
 > Compatible with PicoSPINet 
### EOF ( -- u )  Returns EOF logical state of current open file id | DONE
 e.g.
 $01 OPEN REPEAT READ EOF $00 IF LOOP
 > [!NOTE]
 > Compatible with PicoSPINet 
### FORMAT (  --  )  Formats the current bank selected (NO PROMPT!) | DONE
 > [!NOTE]
 > Compatible with PicoSPINet 
### LABEL ( u --  )  Sets the storage bank label to string on top of stack  | DONE
 > [!NOTE]
 > Compatible with PicoSPINet 
### STOREPAGE ( -- addr )  Pushes the address of the file system record buffer to stack for direct access  | DONE
 > [!NOTE]
 > Compatible with PicoSPINet 
### LABELS (  -- b n .... c  )  Pushes each storage bank labels (n) along with id (b) onto the stack giving count (c) of banks  | DONE
 > [!CAUTION]
 > *NOT* Compatible with PicoSPINet 
### FILEID (  -- u1  )  Pushes currently open file ID to stack | DONE
 > [!NOTE]
 > Compatible with PicoSPINet 
### FILEEXT (  -- u1  )  Pushes the currently read file extent of the file to stack | DONE
 > [!NOTE]
 > Compatible with PicoSPINet 
### FILEMAXEXT (  -- u1  )  Pushes the maximum file extent of the currenlty open file to stack | DONE
 > [!NOTE]
 > Compatible with PicoSPINet 
### FILEADDR (  -- u1  )  Pushes the address of the block accessed for the currently open file to stack | DONE
 > [!NOTE]
 > Compatible with PicoSPINet 
### FILEPAGE (  -- u1  )  Pushes the page id block accessed for the currenlty open file to stack | DONE
 > [!NOTE]
 > Compatible with PicoSPINet 
### READCONT (  -- u1  )  Pushes the READ continuation flag to stack | DONE
 If the most recent READ results in a full buffer load then this flag is set and will indicate that
 a further read should, if applicable, be CONCAT to the previous read.
 > [!NOTE]
 > Compatible with PicoSPINet 
## String Words
### CONST ( u -- u ) Change the type of var on TOS to a constant. i.e. if a string it won't be freed on consuption, | TODO
### MOVE ( a1 a2 c -- ) Copy from address a1 to address a2 for the length of c | DONE
### ZMOVE ( a1 a2 -- ) Copy from address a1 to address a2 until a1 hits zero term string | DONE
 Ensure you have enough space!
### TABLE ( s .. sx c -- a) For the number c of strings s on the stack. Generate a look up table array a | DONE
 Takes a list of strings and creates a block of pointers to each string which can then be used
 in any kind of lookup or iteration. 
 Last item in the array will be a zero pointer for ease of iteration
### SPLIT ( s d -- s s...sn c ) Using delimter d, add strings found in s to stack pushing item count c | DONE
### PTR ( -- addr ) Low level push pointer to the value on TOS | DONE
 If a string will give the address of the string without dropping it. Handy for direct string access
 If a number can then use 2@ and 2! for direct value update without using stack words 
### STYPE ( u -- u type ) Push type of value on TOS  | DONE
 's' string or 'i' integer or 'c' const
### UPPER ( s -- s ) Upper case string s  | DONE
### LOWER ( s -- s ) Lower case string s  | DONE
### TCASE ( s -- s ) Title case string s  | DONE
### SUBSTR ( s u1 u2 -- s sb ) Push to TOS chars starting at position u1 and with length u2 from string s  | DONE
### LEFT ( s u -- s sub ) Push to TOS string u long starting from left of s  | DONE
### RIGHT ( s u -- s sub ) Push to TOS string u long starting from right of s  | DONE
### STR2NUM ( s -- n ) Convert a string on TOS to number | DONE
### NUM2STR ( n -- s ) Convert a number on TOS to zero padded string | DONE
### CONCAT ( s1 s2 -- s3 ) A s1 + s2 is pushed onto the stack | DONE
### FIND ( s c -- s u ) Search the string s for the char c and push the position of the first occurance to TOS | DONE
### COUNT (  str -- str u1 ) Push the length of the string str on TOS as u1 | DONE
### ASC ( u -- n ) Get the ASCII value of the first character of the string on TOS | DONE
### CHR ( u -- n ) The ASCII character value of u is turned into a string n on the stack | DONE

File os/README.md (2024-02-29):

z80-Homebrew OS
---------------

Custom extended monitor which is the OS to my retro machine.

I have a particular love for Forth and the Jupiter Ace has been of interest so I want to make a system that 
runs Forth as the OS, allows access to hardware specifics, file system and as the programming language
instead of the retro BASIC that most use.

This code is what you will find here. 

I have duplicated it out of the stage3.2 dir and will leave what is there there and develop further here.

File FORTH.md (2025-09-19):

FORTH OS
--------

I love Forth. Used it off and on over the years as it is the easiet programming language to design.

I now have one in this bit of kit. I was inspired by the Jupiter Ace and with screen limitiations
a version of BASIC would be too tedious and painful to use. Forth is best option. With it tied to
the hardware I've added built-in keywords to take advantage of the hardware.

At the moment it is interpreted but there is the possiblity I can add compiled words as each 
keyword has a byte OP code. 

Variables/Stack
================

The data stack pointer (DSP) supports string and numbers on the same stack for opperations (just note some words don't check and assume a particular type)

* $xxxx  - 16bit Hex int value
* $xx    -  8bit Hex int value 
* "xxx"  - String (250 char max)
* #99999   - A 16bit decimal int  
* %xxxxx  - 16bit binary value (todo)

Note: If text appears to the parser that isnt above or a valid word in any form it will be pushed to the stack with the assumption that it is a string of some sort.

e.g.

a b c d

If they are not 'words' then you will get four strings on the stack. It is a handy means to push a single text word to the stack without having to worry about quoting it. There is a further feature in that if you push a sentence onto the stack and join each word with the '-' (hyphen) it will be pushed as a whole string and can be displayed with the '-' automatically replaced with a space using the .- word:

e.g.

this-is-a-string .-

Displays as:

this is a string

Again removes the need to double quote strings and possibly miss one. Reduces the space too!

There are also a number of variables which hold 16bit values: V0-V3. They are set using ! and pushed to stack with @, e.g. $03 v0! to set, and v0@ will push $03 onto the stack. While not that flexible nor using standard FORTH methods, there is another way to have an any kind of data structure available.

The PTR, MALLOC and SCRATCH words provide a dynamic (MALLOC) or fixed buffer (SCRATCH) areas for whatever data/variable structure you require:

e.g.

Pushes a pointer to the stack for the offset 0 in the scratch area.

: score $00 scratch ;

This allows for things such as setting and then incrementing at "variable":

$00 score !

$01 score +!

This method supports both single byte and word accesses via !/2! etc. There is no checking so ensure no overlap!

e.g.

: timer $01 scratch ;

Don't use:

$01 score 2!

As that would over write 'timer'.

Another variable method is the use of VAR.

e.g.

"a" VAR @

Storage
=======

Various storage words for both high level file access as well as direct block access. 

Through the use of the CONFIG word it is possible to select a file to be executed at boot time and load word definitions into memory.

There are a few low level words if you want to write your own file system handler. See BREAD, BWRITE and BUPD in the word list.

Alternativly using the high level file system words provide a more conveient means to access data and code (using CONFIG to enable auto run of stored code).

Bank 1 would normally default (unless selected a different startup bank). Using "$02 bank" for example will change to the second bank of storage. Initially each bank will need to be initialised with the 'format' word.

A default label will be assigned and it can be changed with the 'label' word: "MyCode" label

Creating a new file:      "myfile" create

The file ID used for all file words later is pushed to stack. It is possible to obtain the ID when needing such a number later by using the GETID word to look up the file name
and return the ID.

Once the file has been created it is possible to add data to it via the 'APPEND' word: "a line to add" $01 append

There is no need to close files as such. There is a word 'record' which provides a random access to the created files. For a sequential read use the 'OPEN' word to set the
file record number to the first one and then each use of the 'READ' word to retrieve and push each record to stack until the 'EOF' word reports as true or using the counter that 'open' reports.

As such, only one open file for reading is possible, but it is possible to APPEND to multiple output files.

Autostart
=========

If a file begins with an asterisk the file will be auto loaded at start up. Use RENAME to switch files on and off.
Or for blanket enable and disable use CONFIG word to toggle in the UI. CONFIG will also provide a means to select which bank of files 
will be used for startup; useful if a particular application exists in one bank and you don't need it to always load.

> [!NOTE]
> Usually files will contain a list of user word definitions, however it is possible to exec words 
> as they are loaded using already loaded words, in this case be aware that if any code on the single line affects BANK selection
> ensure that the origin BANK occurs (use BANK?) before end so that auto loading can continue as this is not done
> automatically between each line load just in case that effect is needed.

Words
=====

User words are executed before system words so in theory you could replace system words with your own...

While still a lot of dev going on see WORD-LIST.md for watch is working and what is left to do. There is also a shell script that lists the words from the source and shows which ones are working and what are left to do.

Demo Code
=========

The board has an auto start-up process that loads extra words. These include some demo programs such as:

* sw - Hello world
* ga - A simple number guessing game
* ssv - A screen saver

Look in the file forth_autostart.asm source file for the definitions.

Restrictions
============

* So far IF THEN is working but can't do nested IFs on same line (sub-words are fine). 
* DO LOOP is working and can do nested loops.
* 16bit integer maths is working. Would like to add floating point...
* Frame buffer display is slowing things down so now have a word to disable refresh on every update but that doesn't help. Needs a rewrite.
* Keyword lookups while running so can be quite slow to run code. A lot of debug code is included as well as memory corruption sanity guards. Will look at speeding things up by switching on/off debug and guard code as well as working on a compile option.

Bugs
====

Oh boy, possibly a heck of a lot of bugs. Little sanity checking so watch out. 

Look at DEV-DIARY.md for current state of the bugs.

There is a built-in reg state display. It is enabled by default and at various break points (see firmware.asm defines) the current reg 
state can be seen with options (via 1-9) dumps of 16bit reg pointers. Use '0' to step to the next point. All breakpoints can be
disabled by using the asterisk and then using '0' to continue. See BP keyword.

Top right of reg state shows labels which can then be looked up in the source code.

Using '#' will launch a full featured monitor. 
   D xxxxx to start a dump from hex address
   C    Continue from last D
   Q  Return to break point

   M xxxx     Start edit address
   U xx        Load byte into address and increment to next

Holding down a key at boot will halt at the end of the splash screen. Releasing the key will display a hardware/system diags screen. Can also get to that point with the use of the CONFIG word.

The firmware.asm file contains many debug switches. If they are all off the resulting binary file is around half the size and runs at a reasonable rate. Will full debug on there isn't much ROM space left and performance does suffer but the level of debug tracking is really useful especially if new words are being developed or a bug is identified in one.

The make.sh will also generate three debug levels of the ROM. Level DL0 is with no debug or system guards in place. Could be a problem if you mess up code but it will run the fastest. DL1 has some debug code in place to help with tracing programs and has stack corruption guards in place. DL2 has the most debug code in place. Will run pretty slow but should be robust if you are testing lowlevel stuff.

Utils
-----

nip ( w1 w2 - w2 )
tuck ( x1 x2 -- x2 x1 x2 )

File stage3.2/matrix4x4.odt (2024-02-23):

1 | 2 | 3 | A
a b c ” | d e f & | g h I $
4 | 5 | 6 | B
j k l , | m n o . | p q r :
7 | 8 | 9 | C
s t u ; | v w x @ | y z ? !
* | 0 | # | D
shift lock ' tab bs | Space < > | Enter ( )

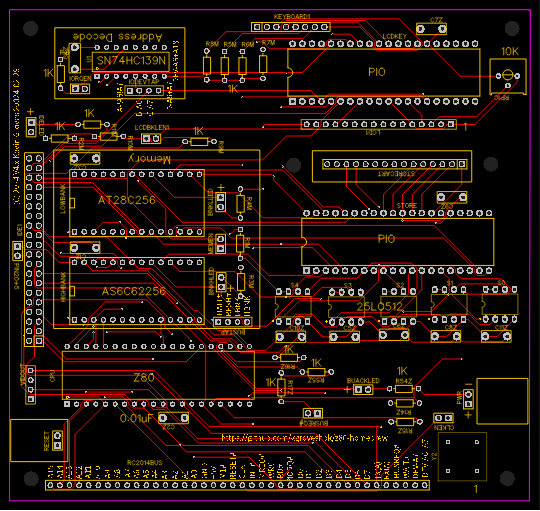
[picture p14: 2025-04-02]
Schematics/PCB_PCB_z80-system-3-sbc_2025-04-02.png

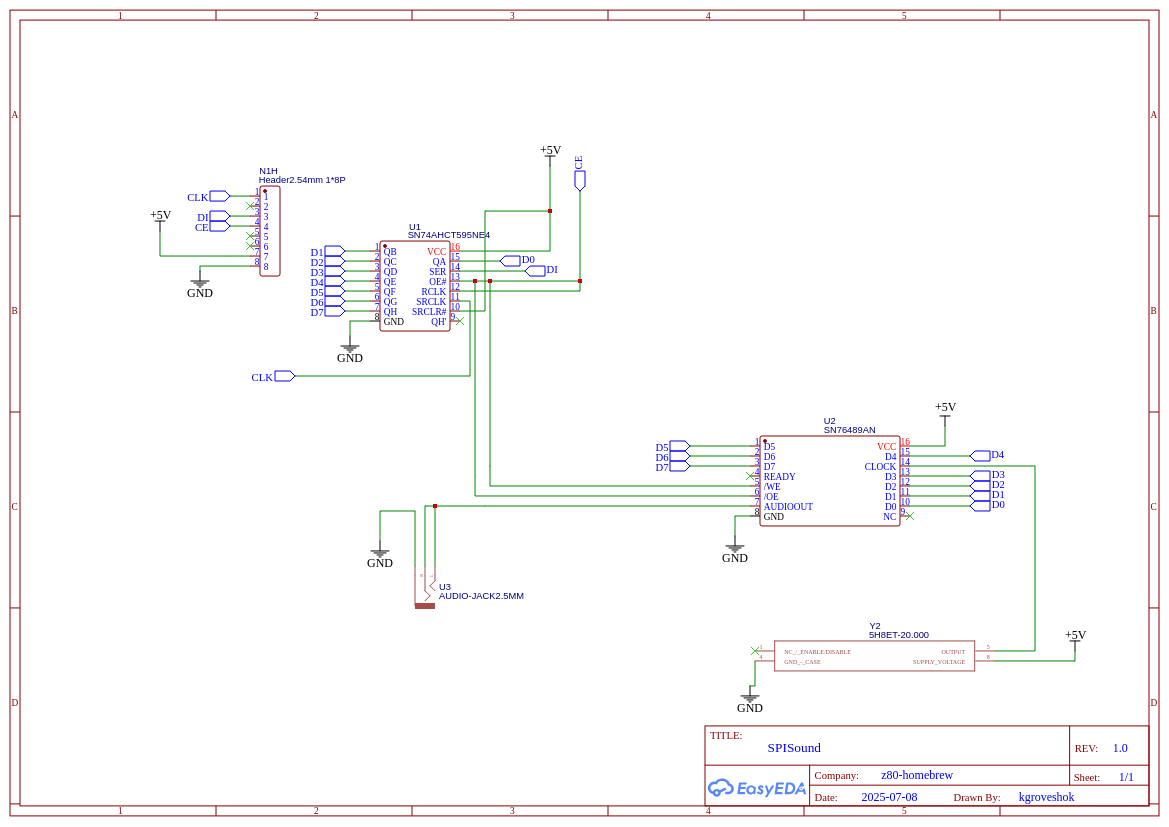
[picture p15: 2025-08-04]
Schematics/Schematic_z80-sound_2025-08-04.png

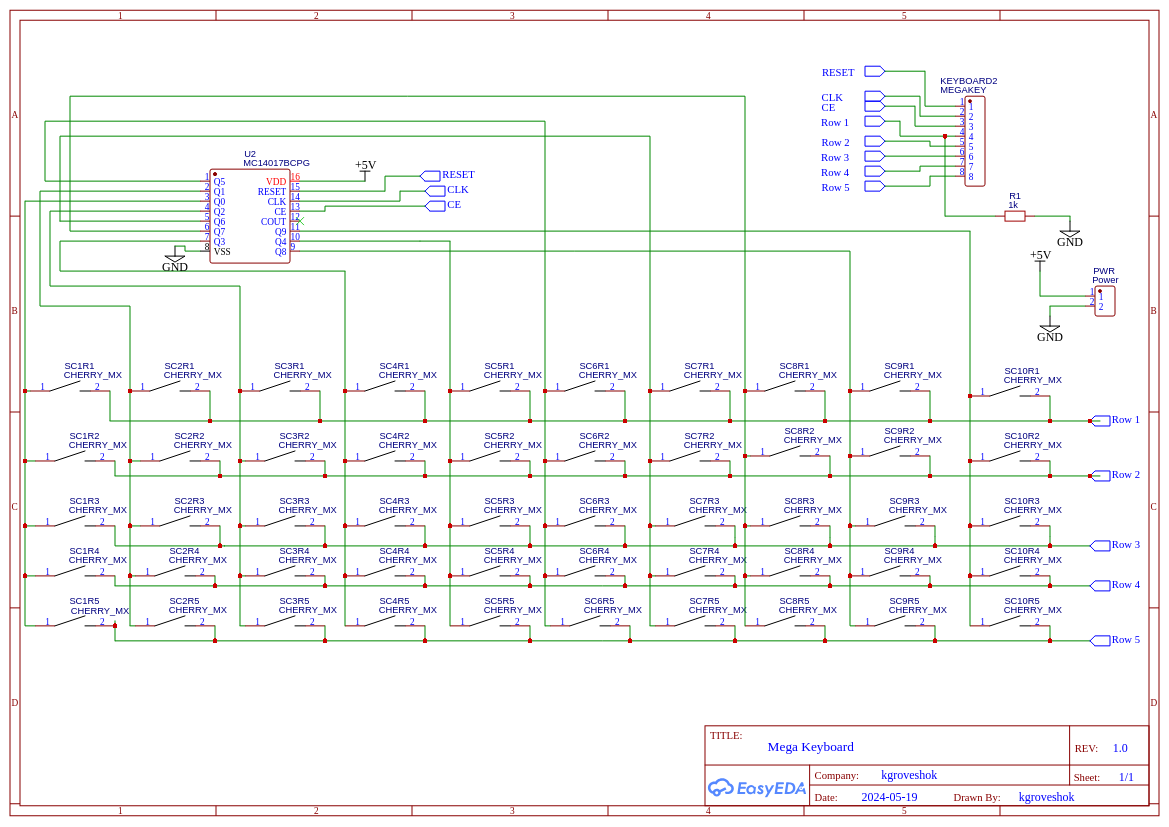
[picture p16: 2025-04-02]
Schematics/Schematic_z80-system-4-maxi keyboard_2025-04-02.png

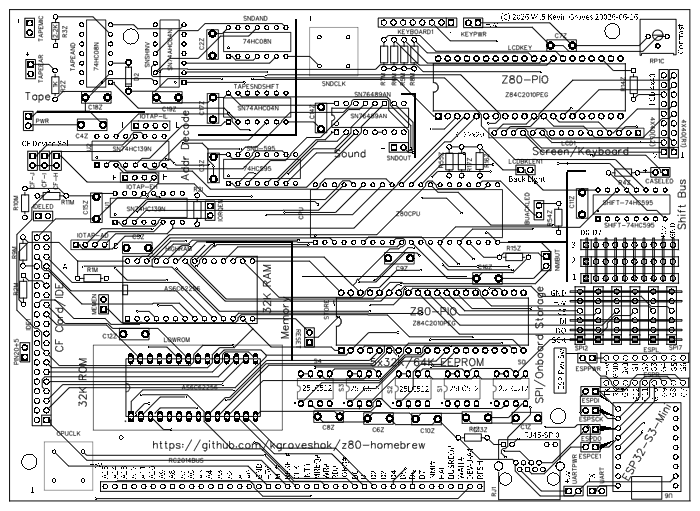
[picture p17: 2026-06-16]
Schematics/PCB_PCB_z80-system-4.5-sbc_2026-06-16.png

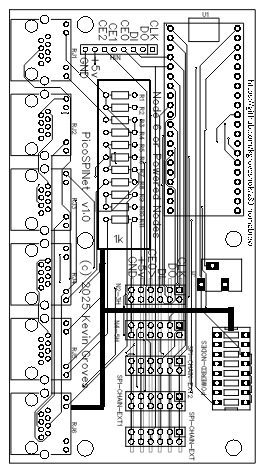
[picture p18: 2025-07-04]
Schematics/PCB_PCB_PicoSPINetv1_2025-07-04.png

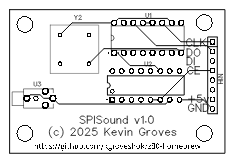
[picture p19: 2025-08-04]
Schematics/PCB_PCB_z80-sound_2025-08-04.png

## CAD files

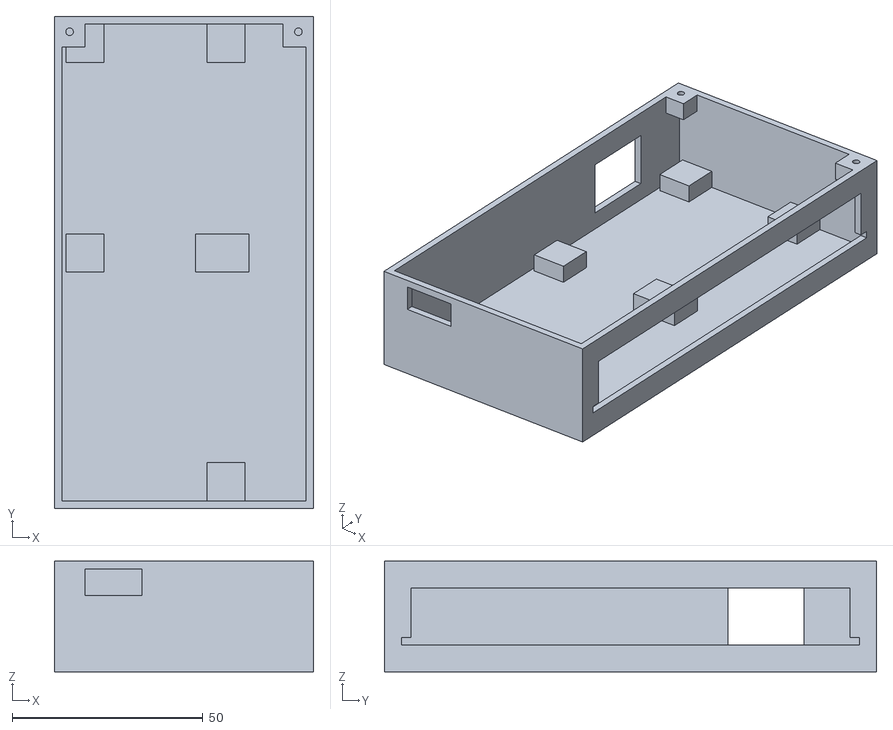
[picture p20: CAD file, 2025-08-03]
add-ons/piconet/box1-Body.stl
68.0 x 129.0 x 29.0

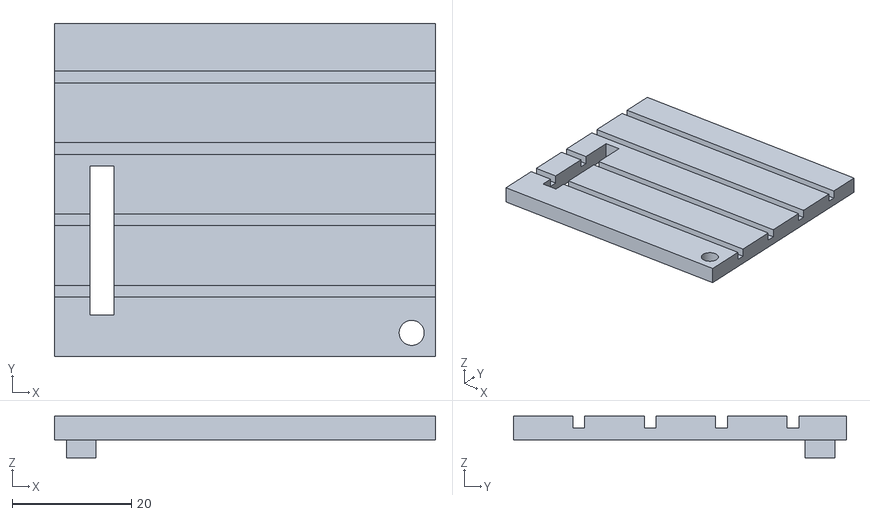
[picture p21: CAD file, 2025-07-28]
add-ons/spisound/boxv1-lid.stl
64.0 x 56.0 x 7.00

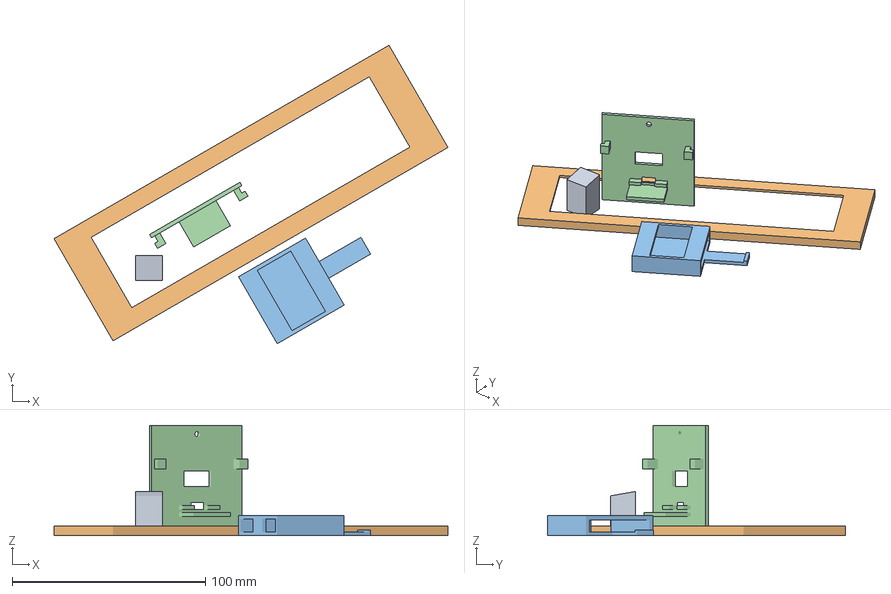
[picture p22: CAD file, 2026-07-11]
case/megav4.5-misc.3mf
203.7 x 154.3 x 57.0 mm
megav4.5-keyboardpillar.stl
megav4.5-lcdbezel.stl
megav4.5-batteryholder.stl
megav4.5-powerpanel.stl

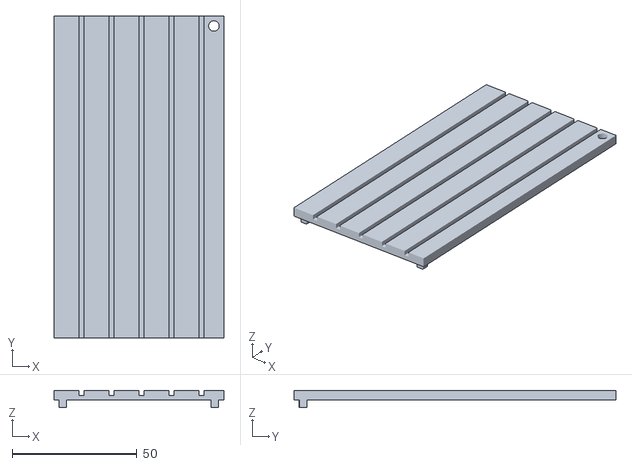
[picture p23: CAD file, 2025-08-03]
add-ons/piconet/box1-Lid.stl
68.0 x 129.0 x 7.00

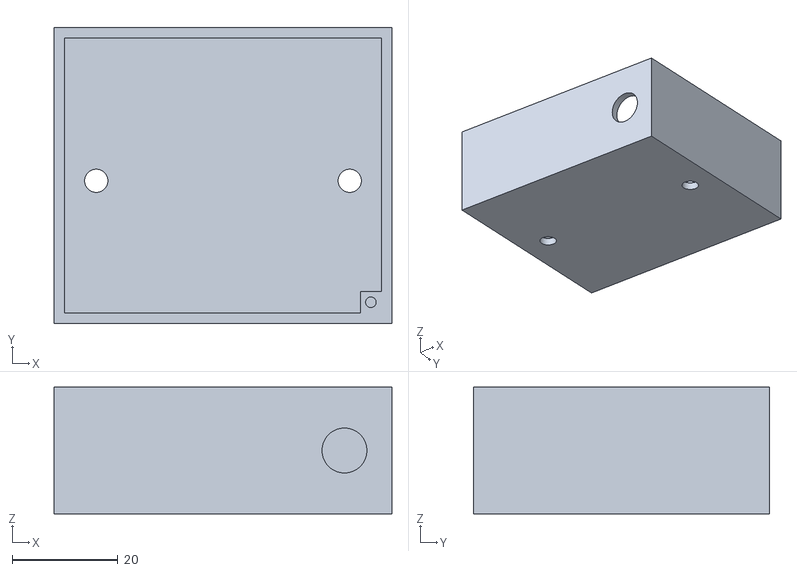
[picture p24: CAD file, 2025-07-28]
add-ons/spisound/boxv1-body.stl
64.0 x 56.0 x 24.0

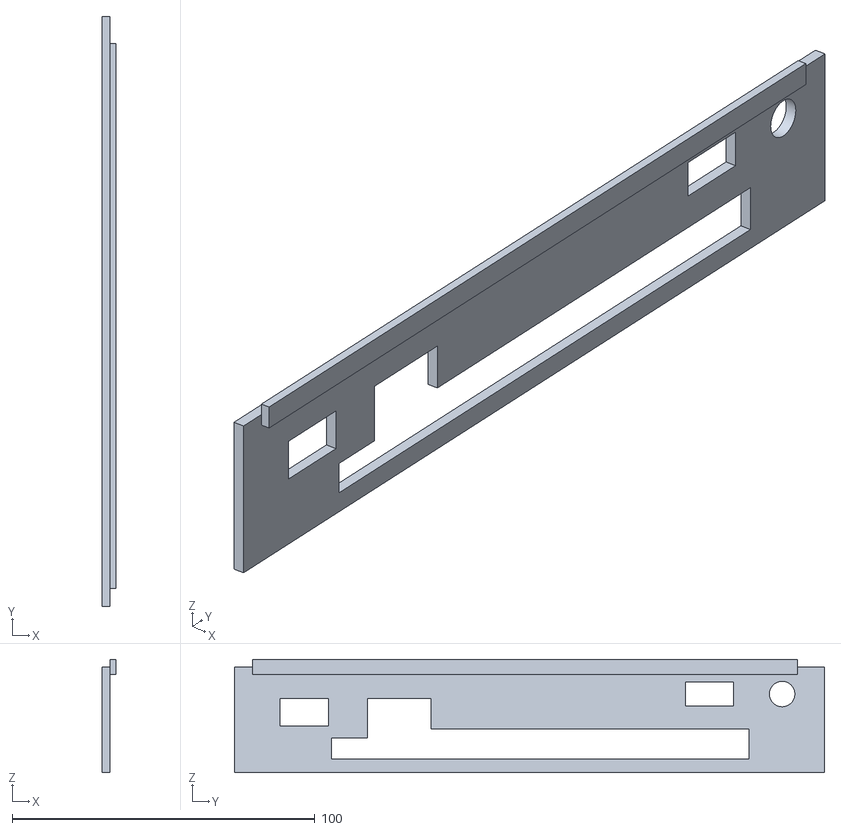
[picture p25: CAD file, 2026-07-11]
case/megav4.5-back-bottom.stl
4.50 x 195.0 x 37.5

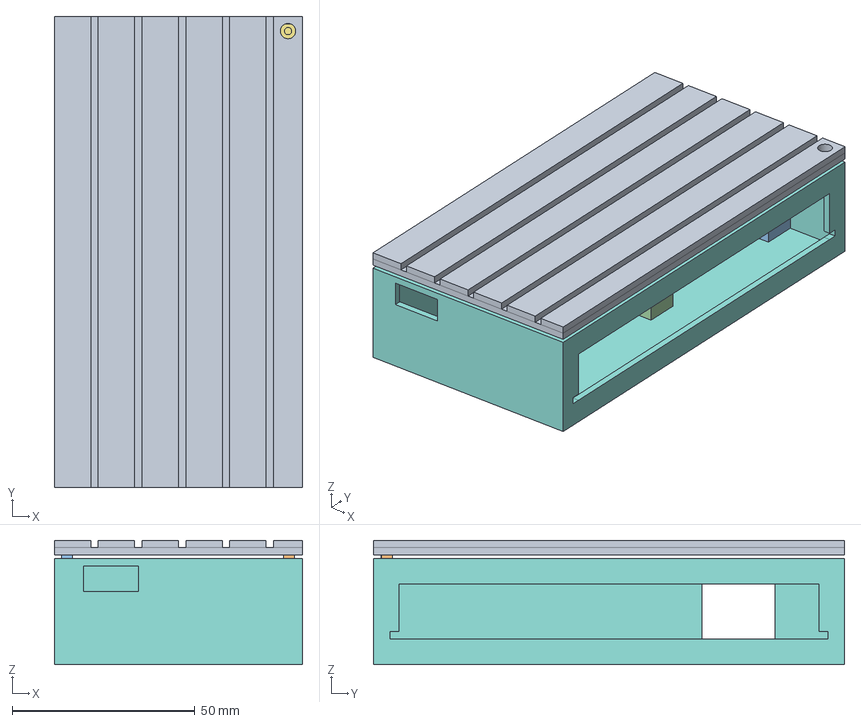
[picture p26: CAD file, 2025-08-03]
add-ons/piconet/box1.FCStd
68.0 x 129.0 x 34.0 mm

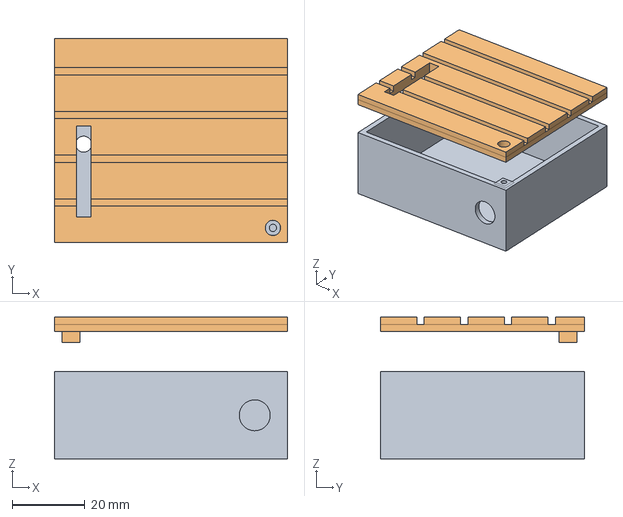
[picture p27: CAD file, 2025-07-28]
add-ons/spisound/boxv1.FCStd
64.0 x 56.0 x 39.0 mm

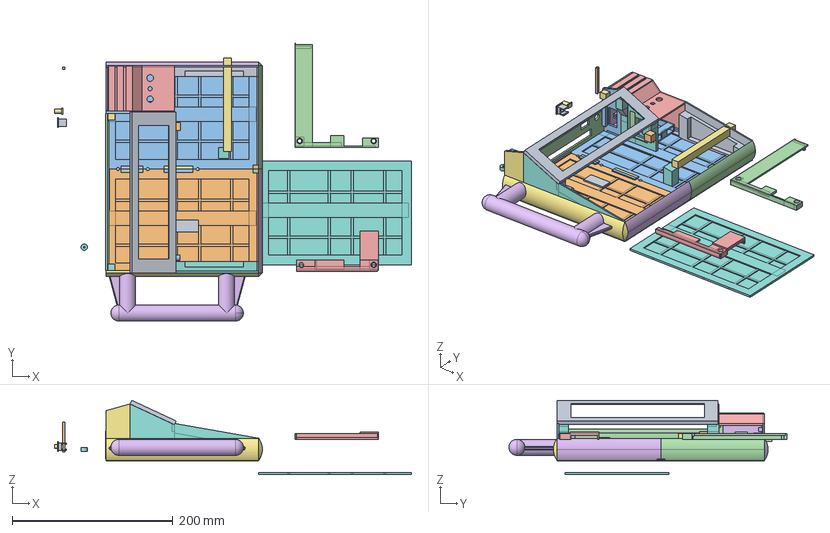
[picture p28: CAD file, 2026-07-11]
case/megav4.5.FCStd
444.0 x 346.0 x 92.5 mm
reset
pwrjack
espuart
espuart002
PCBFoot
RightPillar001
keyboardcentrepillar002
RightExtCartSlotWithHole
WristRest002
PowerBox1
NewBasePanelSection
LinkPlate
BoxPanelSupports
LcdBezel
keyboardcentrepillar001
WristRest1
LeftExtCartSlot
keyboardlcdleftpillar
CarryHandle1
LcdBezel001
LcdBezel002
batteryholder
keyboardcentrepillar003

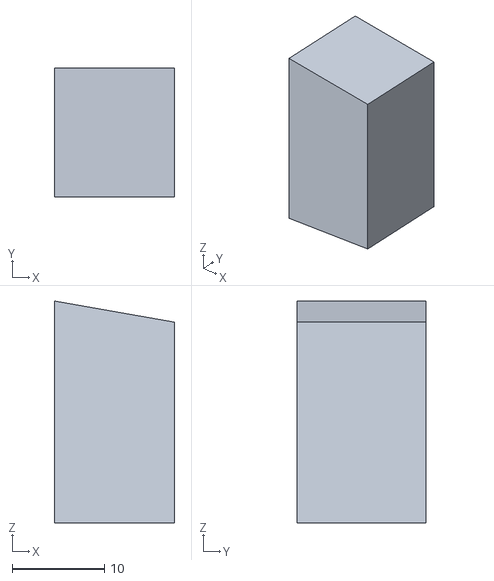
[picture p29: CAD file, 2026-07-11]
case/megav4.5-pillar2.stl
13.0 x 14.0 x 24.0

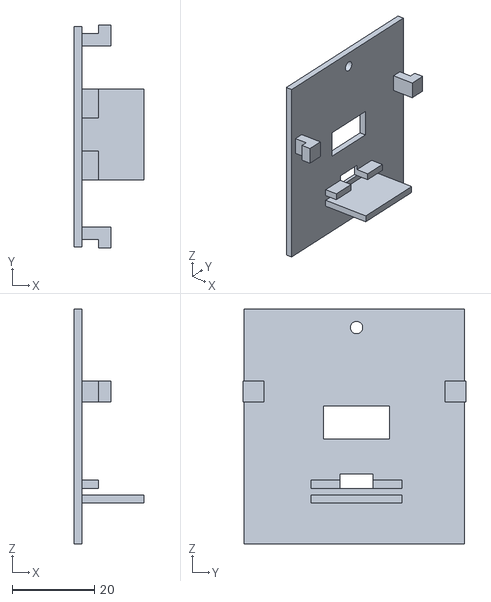
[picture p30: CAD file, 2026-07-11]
case/megav4.5-powerpanelfuzzy.stl
17.0 x 54.0 x 57.0

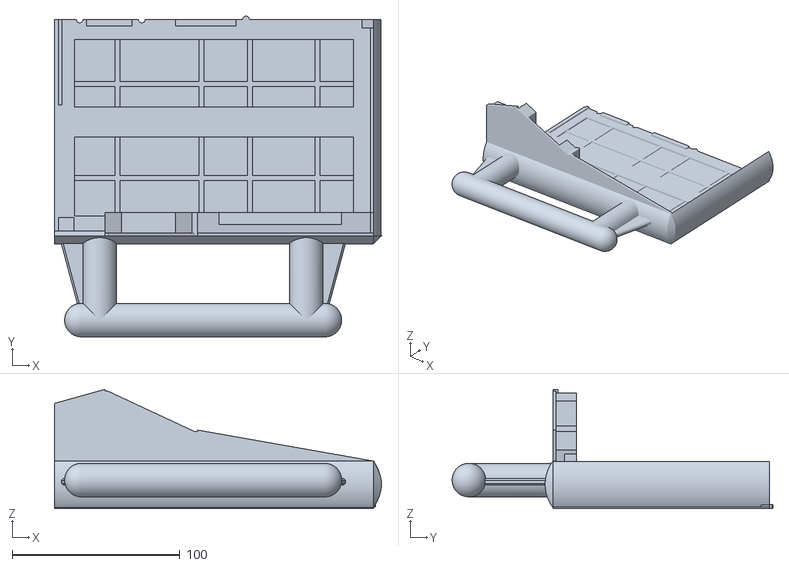
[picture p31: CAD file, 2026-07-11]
case/megav4.5-leftside.stl
194.7 x 191.0 x 71.0

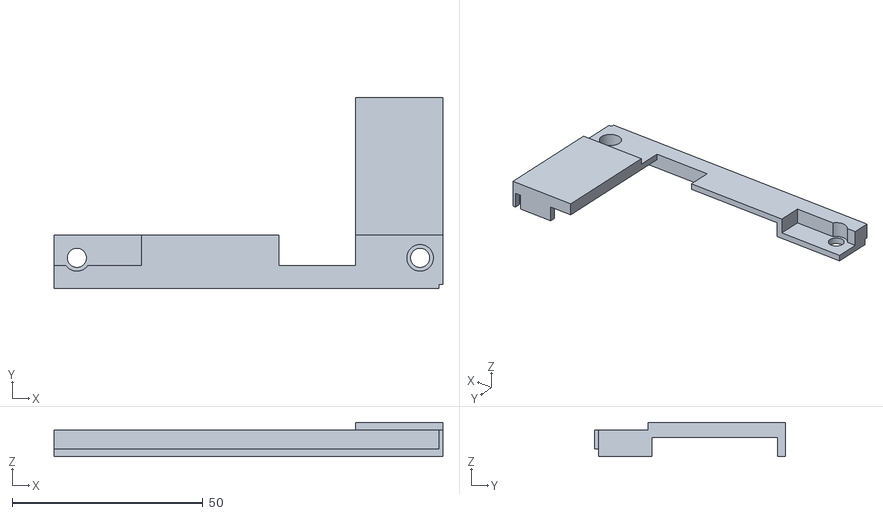
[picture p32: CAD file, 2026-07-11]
case/megav4.5-rightkeyboard.stl
102.0 x 50.0 x 9.00

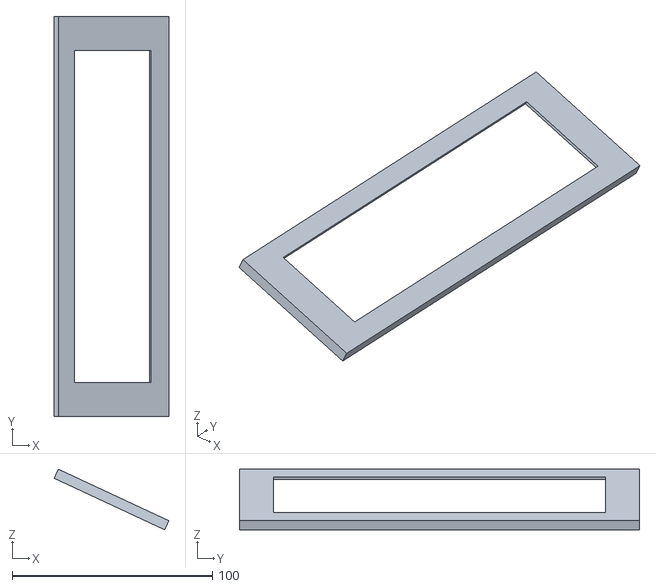
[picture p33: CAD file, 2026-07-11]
case/megav4.5-lcdbezel.stl
57.4 x 200.0 x 30.3

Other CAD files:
case/megav4.5-leftkeyboard.stl
case/megav4.5-pcbfoot.stl
case/megav4.5-lid.stl
case/megav4.5-rightside.stl
add-ons/spisound/boxv1.stl
case/batteryholder-Fusion.stl
case/batteryholder.FCStd
case/case1-Case.step
case/case1-Case.stl
case/case1-CaseBase.stl
case/case1-Cut003.stl
case/case1-Front.stl
case/case1-Fusion004.stl
case/case1-Fusion004solid.stl
case/case1.FCStd
case/case2.FCStd
case/case3-CaseBase-nogrill.stl
case/case3-CaseBase-thin.stl
case/case3-CaseBase.stl
case/case3.FCStd
case/case4-Back.stl
case/case4-CaseBase.stl
case/case4-Front.stl
case/case4-LCDCap.stl
case/case4-Side1.stl
case/case4-keypad.stl
case/case4-resetbutton-case.stl
case/case4-resetbutton.stl
case/case4.FCStd
case/megav1-Back.stl
case/megav1-BoxLid.stl
case/megav1-BoxPanelRight.stl
case/megav1-KeyBoardRiser.stl
case/megav1-KeyboardBezelLeft.stl
case/megav1-KeyboardBezelRight.stl
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

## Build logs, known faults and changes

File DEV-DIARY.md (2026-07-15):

# z80-homebrew
Z80 Home Brew Micro-computer Project - Dev Diary
------------------------------------------------

Todo List/Enhancements:
-----------------------

Bug list:

* TODO BUG Stop menu scrolling past last item - still there after updates
* TODO BUG MENU down arrow not disappearing on last item. OK if not enough to fill.

* TODO BUG ed word has a rogue address pushed to stack when editing a record
* TODO BUG ed word cant cope with lread. Do a check on READCONT and if true add a null to end of edit buffer
* TO TEST need word to report where cursor current at
* TODO BUG read ext concat is the problem
* TODO BUG Cant use special chars in quoted strings??? Why? Emit works for the char code.
* TODO BUG CP/M screen clearing not working well
* TODO BUG CP/M keyboard entry not great

Hardware/PCB Design Enhancements:

* TODO Test shift reg bank
* TODO Test sound card support

* TODO make three way header for esp to either power up and/or supply main board power so can hook up to usb and run from batteries 
* BUG The ROM Ziff socket lever is hitting the CF bottom two pins. Move it back a bit.
* TODO If redoing PCB move the keyboard connectpor to the right side of the board as at the bottom it is long cable
* BUG had to switch DI/DO on the ESP. Check all SI/DI and SO/DO lines are labelled and connected correctly. Ensure MISO and MOSI is the standard
* BUG DI/DO on the array and ESP are not connected to SI/DO on the SPI bus. Solder a quick couple of wires across for now

* TODO Can i add 32k ram bank switch to cover the rom?
* TODO Look at using 64k Serial EEPROMs to double storage. 128k page size so can keep the current page code, just change the PHY... var
* TODO Move Tape support Forth code into firmware
* TODO Code ESP32 device for networking etc

ESP32 via SPI
-------------

* TODO Continue writing remaining ESP functions
* TODO Support EEPROM SPI protocol for onboard storage
* TODO Internet service/socket access to make work. How to interface?
* TODO Internode comms

Langague Enhancements:

* TODO Add MENUS which is like MENU but instead of the item number selected it is a pointer to the menu item text
* TODO Add CHECKBOX which functions like MENU but also takes a block of memory used as a check box value. If the prefilled value is 0 then dont allow toggle.
* TODO Add to MENU word returning not just the number selected but also the string
* TODO MENU to support multicolumn selections if width given?

* TODO Add a BPSET and BPCLR to set a string that is compared to CALLMONITOR in the DMARK macro. 
* TODO A word to send a file to pool
* TODO A word to send pool contents to file

* TODO Need a RROT and LROT bitwise byte rotate like the Z80 RRC and RLC op codes
* TODO Add a version of CALL that takes a block of mem with reg pairs that are loaded before the call and return the values 
* TODO  once fixed words add uword with prefix of star that is searched for by the run command that allows menu generated to start that word
* TODO add new call word ehich takes de and hl parameters off the stack
* TODO  a box word for drawing boxes
* TODO -rot reverse rot   w1 w2 w3 – w3 w1 w2   
* TODO 2nip       w1 w2 w3 w4 – w3 w4
* TODO 2tuck       w1 w2 w3 w4 – w3 w4 w1 w2 w3 w4 
* TODO 2rot       w1 w2 w3 w4 w5 w6 – w3 w4 w5 w6 w1 w2
* TODO LEAVE to exit DO LOOP
* TODO /STRING for string cut (substr???)
* TODO REPLACES/SUBSTITUTE for string replace
* TODO SEARCH is simliar to FIND
* TODO Handle CONST on all DS_TYPE_STR. Can then use "hello" ptr const . to print a pointer as a string which destroying the original
* TODO getid is slow. does it bail on first hit?
* TODO need word to get file id by name
* TODO need word to get file name by id
* TODO need words to report on hardware e.g. screen dims
* TODO Add word to call fill_display with a char. accesss it via the symbol list???
* TODO Word to define lcd user character 0-3. Then word to output via emit etc
* TODO Add FILL word - ( addr n char -- ) fills address for n long with char
* TODO Add ERASE word - ( addr n -- ) fills address for n long with zero  
* TODO Add support for ELSE and ENDIF. IF THEN ELSE ENDIF   or IF THEN ENDIF. Or IF ... ELSE ... THEN
* TODO A word that will allow the loading of a file into memory with strings held in pointer array. Use with TABLE word.
* TODO Include files with duplicate uword detection

Core Firmware Enhancements:

* TODO Make sure to reafirm the CE SPI lines are down on boot before storage access otherwise could be bad
* TODO EEPROM Defrag
* TODO Put format type into one of the header bytes to allow for a new storage format
* TODO Abstract away for the storage format

* TODO Enhance the DUMP word to provide direct memory editing like the tec monitor
* TODO Add stack checks and guardrails to be options on or off via hardware word bits. have a selection of off, low, mid, high levels of checks if possible. Have added bit set in firmware_init but the bit might be over written by other hardware settings

* TODO CONFIG option to redirect key/display to ESP for a larger setup. Add call to esp putc in the dot command and a full frame draw in update display.

* TODO Hardware config byte containing switches. There is a hardware_config and hardware_word symbols. Is it used? It is 10 bytes. Add toggle to CONFIG
* TODO Add display if on bottom row and cr is pressed then auto scroll up - added code to the firmway str-to-display but did not not affect dot commands so need to look at how they are displaying
* TODO Config option to disable breakpoints and garbage collection
* TODO SN sound chip firmware
* TODO Add ? after file name prefix * to prompt for optional load/skip during autoload
* TODO Add garbage colleciton/gaurd checks as a vector that can be enabled and disabled via CONFIG
* TODO  .f word to output formatted. ie x "9999" .f four dec
* TODO .h word to output as hex value
* TODO cr wird does not advance to next row
* TODO more symbols which can be used for calls to interal functions 
* TODO Add signed number type can then finish the <> words
* TODO Add support for 2-3 file handles
* TODO Add support for bank numbers in file names
* TODO Add keyboard macros mapped to key code (mainly for f keys)
* TODO Add key codes to docs
* TODO Add a word that defines the macro record hotkey
* TODO Add auto generation of keyboard mapping codes to docs
* TODO Include BDOS rst #5 support. Get CPM BDOS code and insert it
* TODO A pipedream conversion from Z88 to allow wp and office tools. Would need tape and/or DART working to make it useful
* TODO More optiz perhaps not do the stack checks every time? in forth_kernel, check_stats on first hl push do a count down test  
* TODO storage block reuse working?
* TODO provideca f key hook which can be triggered at any get key
* TODO sort out ntp get 
* TODO add write protect to bank - byte zero? any attempt to write should throw system message
* TODO add more to config menu
* TODO Using the vector hook though means only jumps. Need a wrapper around use to preserve current concontext and then restore it after
* TODO Add user interrupts by putting a hook into the parser or on NEXTW (as if using compiled version)
* TODO Add user 'threads' by putting a hook into the parser or on NEXTW (as if using compiled version)
* TODO Add user watch break points by putting a hook into the parser or on NEXTW (as if using compiled version)
* TODO add more editing features. Like what?
* TODO for op codes compile from dict but at run time look up a calculated table with jumps to the words to save having to scan dict to find op codes
* TODO Add block/id count for auto load to show where it is looking
* TODO Could I use frame buffers for cli line storage which would mean they are available for use by code if needed? Would then free up some memory.
* TODO Add stack and malloc guard vectors plus code to enable and disable then in config and cli
* TODO Add selectable guard around SPIO to prevent accidental corruption of storage banks
* TODO in ls handle empty dir
* TODO Add to start up a list of what storage labels are seen
* TODO SPI Net send internet traffic and push results to message buffer. Does get URL but blows out on memory
* TODO SPI Net get LAN status
* TODO With the float code being so big need to do some opt via http://z80-heaven.wikidot.com/optimization
* TODO delete record
* TODO ui to call config
* TODO change size to fsize?
* TODO ui join files ui
* TODO Add a means to attach some code to a vector hook
* TODO Add hook vectors. Can change  dbug checks to vector with return if disabled to save on push and asterisk checks. Add hook for stack checks to disable. Add hooks for some other points such as before and after words
* TODO Add config feature to select which devices are on specific SPI addresses and have words for easier selection???
* TODO Conslidate all prompts into a single file to allow for removing duplicates and maybe even localisation
* TODO add ram test to the diags
* TODO Alt T is duplicated }. Free to reuse
* TODO Alt H is duplicated |. Free to reuse
* TODO Alt U, O, P, 5, 7, 8, 9, Enter are free
* TODO Create a disk UI in native asm for robustness and speed? Have some config routines for this now. Expand on them
* TODO New value type for signed and unsigned val. Add to maths. added DS_TYPE_SNUM need a word to convert type. SIGN/UNSIGN. Fix up <= and dot.
* TODO Speed up screen updates - instead of writing whole screen detect what has changed? 
* TODO Add no bank chip detection to format
* TODO Add a forth stack content viewer to callmonitor code
* TODO Add the floating point maths code in
* TODO wire up a temp interface to the serial EEPROMS so I can test storage on the SC114 as I have the PIO and digital IO cards installed
* TODO Add a simple assembler feature like BBC Basic

Documentation Changes:

* TODO Draw memory map for ram, rom, devices
* TODO A simple solo card game demo
* TODO A simple character fighting stat game
* TODO Top trump like game
* TODO Mine sweeper
* TODO Mastermind
* TODO Connect 4
* TODO a small tetris or three in a row shape matching 
* TODO Find the pairs
* TODO Note taker with menu list selection
* TODO score trackers
* TODO Moon buggy jumping game
* TODO  film videos of z80 for bespoke website
* TODO Produce BOM for all of the hardware projects to go with documentation
* TODO Do a nice FORTH primer with the hardware. Screen shots and all...
* TODO do random quotes from file as example code
* TODO Add to docs that looking up file name of id is just id BREAD 

Major Firmware change for Forth compliation:

New compiler ideas

Add a uword which can set or unset compile on new uwords

To compile:

build compiled body into spare memory first to get malloc length needed

Parse token.
If found
	Get jump address
	In uword body add the jp instruction and add the address
If not found then store as string
Allow parser to get next token
malloc correct size and crete uword header + copy of compiled block
Set uword as contains compiled code

In LIST if uword contains compiled code return uword in comment as compiled

At runtime parser
Get token pointer
If byte is jp instruction then short circuit the parser search and exec
If not jp then pass to string decoder

Dont need the uword token number as i think a jump to the exec code will then move the pc to the next token via nextw????

* Compiler:
*    For the TOKEN flag on the CWHEAD macro, only allow use of direct code if the flag allows it. This will prevent some tokens from being issued
*      direct such as THEN which is a search of the string. Maybe other tokens will need this.
*    For : def: tokenise string
*               Locate tok and obtain pointer to start of exec code
*                 Save jp code flag
*                 Save pointer
*               If token not found then assume push. Save section. Skip section
*              
*    For runtime:   Parser obtain start of token
*                   If at start of token is jp code flag then assume following word pointer to code
*                      Get pointer
*                      Forward cli pointer to after code pointer
*                      Jump to code pointer
*                   If jp code flag not set then push through raw text parser
*               
* TODO Actually forget using op code, there is already a flag to define if the word exists as binary form on the CHEAD WORD_FLAG_CODE. What is being used for uwords? yes WORD_SYS_UWORD is used for detecting if sysdict or udict. No, that SYS flag is used in op code. WORD_FLAG_CODE isnt coded for a memory space. Only opcode, so back to that idea
* TODO to make compile easier to work with only apply to colon word defs and not immediate 
* TODO a better means of compling is not to use op codes but as in trad forth and create a pointer to the direct code block to exec and by pass the token scanning. Would need a flag before the pointer to indicate that what comes next is a pointer and not something to throw at the parser. This would work for system and uword exec. Dont forget to make sure the next token pointers are kept up to date. Perhaps if the item is known to be a string or number it can short circut the parser. We know the symbols that work for this. 
* TODO Change op code to be flags: a. this word is in binary form and cant list it.... should be able to compile all words as even single char would be quicker with a jump
* TODO Due to bad performance of the parser (???) need to look at compiler... Added some OP code stubs. FORGET and LIST use a scanner. Combine with main parser and have one for keyword and another for byte code
* TODO for the compiler. At runtime Have the parser detect if the first char to scan for has top bit set. if so then the rest of the byte is compiled keyword and use fast lookup instead. Does limit to top 127 keywords
* TODO When compiling a uword. Parse tokens and replace with matched high bit words.
* TODO prefix a uword block with a flag to say if the uword contains compiled tokens (useful for LIST)
* TODO have a CONFIG flag to enable and disable auto compilation of uwords 

* TODO Double check parser. The find next tok call and then there is a comparison word check further down. Doing double the work?
* TODO ld hl,(xxx) is 20 cycles, but push and pop are 11. Change the parser to use a fixed reg pair for important vars provide a macro to save and restore of environment on words. Could add to the single jp (hl) and NEXTW to restore. EXX is 4 cycles

On one forht:
egister BC contains FORTH's internal Program pointer.
Register IX is used as the Return Stack pointer.
Register IY contains the address of FORTH's NEXT code.
Register SP is used as the Data Stack pointer.

Personal Applications
---------------------

* TODO A Full screen note taker which saves to both EEPROM and ESP pool
Enter a line, save in memory, provide scrolling and editing of in memory and then a dump to eeprom and/or pool. Inspired by the application on the Sinclair Z88.

Done Items
----------

15th July 2026
--------------

* DONE ESP Pool access to finish (mostly, enough for backups)
* DONE ESP Setup wifi connection
* DONE Add ESP low power mode with CE wake up

12th July 2026
--------------

* DONE BETWEEN? word to check is tos is between a range. could just use a uword with lt and tg checks : between? ( fr to x -- b ) dup rot < rot rot < = ; 
* DONE between word st en -- x ..... x    generates a list of numbers on stack in range:   : between ( f t -- x .. ) swap do i loop ;

* DONE BUG LED only updates if the screen updates. Issuing a set pos 0 to force LCD write
* DONE BUG If : word is in caps it wont work. This could be connected with caps on LIST which only works if given as lcase.
* DONE Add words that do some of the heavy lifting for SPISound out on the current CARTDEV - e.g. sending the three bytes to the spi for a note, playing a full tune. SN Hardware now in place.
* DONE BUG Need to fix numbers and/or punc in uwords
* DONE BUG Uword can't have a numeric in the word name???? Odd... Nor special char?
* DONE New case design - Have a new one, printed and need to refine for use with PicoNET
* DONE Create new double row header for 4x40 lcd and remap pins. Keep existing single row for other lcd type
* DONE Reroute VIDCLK to E2 on LCD header
* DONE Add power to keyboard edge pins
* DONE Add rj45 socket to pcb with wireout for spi to picospinet node
* DONE Add onboard WiFi via esp32 spi 1. with spi 0 for lan. code 0 can be used to detect if powered on by a switch to save bat. 
* DONE Add nmi button with rst vector to address 0x66 - some code stubs in main.asm. add some words to check and restart nmi flag. Code added but not sure what the problem is. Just expose the pins and come back to it later. Need to adjust vector location as past 0x66
* DONE Add address decoding for the SN sound chip - shift working. Maybe add the wr signal to ce to disable read from shift latch
* DONE Add more address decoding for device a to allow sound and tape plus more. Skip A0/A1 and start from A2
* DONE Cut cf track and wire temp to spare device ce to test
* DONE Move cf card interface to spare device addr
* DONE Change circuit so that the storage cart is actually on port a and provides a full 5 chip pack. Then move sound to port b
* DONE Change the spi cart to a row of spi slots so i can then insert the rtc or sd card on its own
* DONE Include exposure of the shift reg latached data bus to multiple pin headers for other devices/uses.
* DONE Set up led on last vid pin. add to keyboard firmware a check for config bit set to enable disable. See firmware_buzz.asm + lcd 4x40. Coded and working with a test led. Need circuit added to schem. Pin is VIDDO
* DONE Added support for 595 shift reg on any port via SR word
* DONE Add op-amp circuit to SPISound and allow for selection at wire time. Moving SPISound to on board via direct bus use
* DONE Add dart. Not doing. With a CTC will take up too much space. Better use if going to use the ESP.
* DONE Pico to handle display to have two way return of data. Switching to a ESP Mini for extra features
* DONE Take the vid out handshake lines and code up a Pico to handle display. Not done as going to use the ESP
* DONE BUG Future bug? stack imbalance on storage_read. Needs a pop of de if no record found. Have added code watch for further issues

* DONE Make the MENU function look nicer and responsive
* DONE A save and restore word for device/cartdev. If needed could I use symbol reference instead?
* DONE Add scroll down indicator to menu code
* DONE Add words that do some of the heavy lifting for PicoSPINet out on the current CARTDEV e.g. native send and get char. Not doing now I have ESP
* DONE Add word for setting node number to talk to??? Now using ESP
* DONE CART? to get the current cart id. No, added a DEVSAV/DEVREST to save and switch
* DONE CONFIG option to add a program break key. Or perhaps use NMI button? What pointers need to change to signify? Could set a var and then check in parser doing a warm boot. nmi vector to ram which then allows the function to be changed.
* DONE SHow start up bank 
* DONE A Simon says game demo
* DONE Move DMARK to hardware word bit check. Don't need to worry, as it is using a vector now so ret is the fastest it will be
* DONE Add to autostart to conditionally load if hardware switches are set. Need hardware config switches and then a char following the * to select. Perhaps the cartdev number? In config select device maps to hardware. Now have asterisk prefix for optional auto start in a bank.

* DONE  save file from socket. esp now
* DONE  copy file to isocket backup. esp now

29th Apr 2026
-------------

* DONE Need a word NEW to clear all uwords which can be used before LOAD

21st Apr 2026
-------------

* DONE Fixed UPTR word so it can be used by CALL to exec uwords
* DONE Added to utils R uword for repeated string ( str ct --- str )
* DONE Added to utils EXEC uword to exec uwords dynamically
* DONE Added to utils SCANWORD uword to show key press codes which helps in working out F keys for example
* DONE Added bitwise AND and OR to logic words

1st Apr 2026
------------

* DONE Moved a number of frequent calls to RST instead (saved 1.5k off the bin size of DL2)
* DONE Reduced the size of the DMARK strings. Saved 5.5k off the bin size!

3rd Sep 2025
------------

* DONE KEY word waits for key release. To make it compatible use a non debounce version and add a KEYDB which does key bounce checks
* DONE Looking at the parser there are a few opts I could make, such as the constant saving of pointers. Why?
* DONE  a split word could be useful that pushes each bit to stack
* DONE Add .R to right align a number. Need to fix NUM2STR to get it to work. NUM2STR zero pads string by default
* DONE Fix NUM2STR. 
* DONE Fixed generate Hello World file
* DONE Fix 2SWAP for type flag
* DONE Fix 2SWAP
* DONE LSHIFT and RSHIFT for bit shifting
* DONE PICK word to pick a value at a given value on stack and move to TOS. Some code in place. Needs fixing as not quite right
* DONE Fix IS 
* DONE IS string compare should be renamed to COMPARE
* DONE Added DMARK for user code tracing useful for DL0 rom
* DONE Fix LEFT
* DONE Fix RIGHT
* DONE UPTR word to get a user word code ptr
* DONE generate word list md for the NOTE keywords is adding double spacing and breaking it. 
* DONE New Uptr word to point to start of exec code of uword. Handy for writing forth hook code. Locate the c3 byte as it does work with a call..
* DONE Added parse_vector to NEXTW 
* DONE tidy up config menu - hellow world not working plus diags etc
* DONE MOVE,CMOVE words  ( a1 a2 c --- ) from a1 to a2 for length c
* DONE TABLE word like MENU that will take a bunch of string on the stack, allocate the memory for all of them creating a table of pointers to each string and returns a pointer to that pointer table
* DONE CONST word. How to have a string a constant so that printing it does not free it?   What about a CONST word that changes the string type to not being freed?
* DONE Opt: ld (hl),a to ld (hl),<lit>
* DONE Opt: ld a,0 to xor a (watch in case of flag change)
* DONE Opt: cp 0 to or a
* DONE UPTR word. add uuword dmark as an extra set when a uword is looked up to exec. Added to firmware. need display on break point screen and where to intercept in parser
* DONE Make use of STORE_0_BANKRUN var and allow selection of which bank to auto run from at startup. Already being set. Setup CONFIG to set it
* DONE BANK? to get the current bank id
* DONE add a ztype which prints chars until zero term. added to bank 2. Added to utils.
* DONE NIP w1 w2 - w2 - : nip swap drop ;  added to utils

31st August 2025
----------------

* DONE Add a shift reg to the sound card pcb so i can have gpio output on spi
* DONE Added TUCK to Utils file

9th August 2025
---------------

* DONE So many bugs in editor below perhaps a rewrite now things have moved along?
* DONE fix editor bugs
* DONE typing a long few lines and then back space, then insert ends up creating spurious characters - added clear of edit buffer???
* DONE Editor issue insert mid string causes loss of zero term giving random data
* DONE Backspace mid string does not clean up shifted text
* DONE Jump to end of line does not work should set to the number in last debug display
* DONE If cursor at end of line, when go back it leaves custor displayed
* DONE Fix prev line recall and insertion. Corruption appears on the end of line - added clear of edit buffer
* DONE move games and major blocks to new files instead of demo
* DONE remove rubbish game code from file creation
* DONE For now prefix dec with # to push
* DONE Add command to select between common or node PicoSPINet storage banks. Use user words as specific to hook up
* DONE Add command to select different banks of common or node PicoSPINet storage banks. Use user words as specific to hook up
* DONE Warm reboot after stack underflow loads uwords on autostart again. Need to skip. Not doing it now.... Does sometimes... possibly is bank selection is active???
* DONE BUG Add reselection of BANK during auto load. No, it is noted in docs and could be a feature.
* DONE TODO Handle socket level iputchr
* DONE TODO Handle socket level igetchr
* DONE uword not exact match pulls wrong code. Maybe resolved now if connected with LIST
* DONE Saved setting to enable/disable auto start
* DONE Saved setting to select words to auto load from storage. Now using file name
* DONE Fix KEY. KEY word is ok. if no press then zero otherwise ascii 
* DONE look at hooking up a RTC on SPI. Most are i2c. Use PicoNet instead
* DONE provide various debug level versions of the binary. One with no debug, one with most debug and a key debug only
* DONE include what the ROM assemble options/targets are in the file on splash screen to easily id what the machine has in it
* DONE Lower case word defintion for LIST output
* DONE when underflow instead of going to > got to monitor first as that will help with using word mark clues
* DONE  try not debug firmware to see if that speeds up system. It does.
* DONE Fixed SWAP for type flag
* DONE Fix ROT for type flag
* DONE have added hltostack1-4 and reverse
* DONE Need som FORTH_DSP macros to provide pointer offsets to top n stack items
* DONE How to swap string items as calls tO FORTH_DSP_POP will destroy memory allocs? Just move bytes?
* DONE BUG function to store three copies of three bytes used to move stack around for swap, over, rot etc and cope with type flag. Look for "TODO Use os stack swap memory"
* DONE BUG swap of string and number leaves string ptr being left as number. Not swapping var type? Should swap three bytes not two
* DONE Fixed OVER
* DONE If DUP string then may new malloc copy as any use will do a double free which is bad. Already set to detect type
* DONE BUG Does OVER work with a string and a value on stack? I know swap does not so not expecting this to work. Yes copies as a pointer. Need to shift three bytes. Write a bit of code to store three bytes for stack movements.
* DONE backup and restore of banks to network. ubiall word

7th August 2025
---------------
* DONE BUG UWORDS pushes the correct count of words, but only goes so far and stops pushing. problem with the demo code uwrods. renamed file so it didnt load and uwords now correct. might be one of the words being a problem with the mb code lists: vsp vsw mb and stops after mbcms. It was the strcmp function.
* DONE Tidy some docs
* DONE Recal stack size to actual stack item storage size

6th August 2025
---------------

* DONE Add 1-! to dec one to the byte at address tos value
* DONE Add 1-2! to dec one to the word at address tos value
* DONE Add push and pop of hl before start of FORTH_DSP_POP to save on repeated use
* DONE picospinet fix up the send byte to socket 
* DONE picospinet fix up the receive byte from socket - append to node buffer - socket based on node id

5th August 2025
---------------

* DONE Add 1+ to add one to the tos value
* DONE Add 1- to sub one from the tos value
* DONE Add 1+! to add one to the byte at address tos value
* DONE Add 1+2! to add one to the word at address tos value
* DONE show bytes free in dec
* DONE show bytes free after auto load has happened
* DONE BUG bytes free wrong (inverted). Using the correct pointers?

31st July 2025
--------------

* DONE Debug not right since switching to vector ditching too early. Rogue pop af at start of function

30th July 2025
--------------

* DONE Tidy auto run loading screen
* DONE Add ACTTVE word which returns the next in a cycle of progress
* DONE Make monitor do a call warm boot. Does it already do this during stack crash or a different case? No add it.
* DONE Monitor to have G command
* DONE Monitor to have warm boot jump option
* DONE Save auto run flags to block 0 on bank 1 and not on currently selected device. Need a function to load from block 0 into hardware_config and then repoint all menu options to load and save them.
* DONE Add a flag to block 0 to decide if the auto startup prompt is given and/or run
* DONE config var to auto run everything?
* DONE Add LREAD support to the autostart exec
* DONE NMI vector and switch - default to running monitor - add switch to +5v on r15z pin closest to clock
* DONE Add to symbol some key vectors for commands eg. MALLOC, PUTCH, GETCH, Symbol table. 

29th July 2025
--------------

* DONE RENAME word to allow for the new auto start method
* DONE Change auto from file to run all files with asterisk in first chat of name
* DONE BUG now forced to resolve the lread feature when loading from file

28th July 2025
--------------

* DONE SPISound now built and working as a temp board. Still need to do PCB 
* DONE Not doing. Change NOTE to PLAY and use a stream of items on stack
* DONE Via SPI with the second PIO port hook up and debug the sound card
* DONE Create A SYMBOL word which is a look up to the address of a system symbol table more efficent than adding more words
* DONE Fixed SPACES
* DONE bl word causing reboot only on z80, not doing it in cpm. Maybe due to write to ROM on z80.
* DONE FILEADDR already does this. Add word to report the physical address of the currently loaded record
* DONE Added a direct memory edit DEDIT word
* DONE file editor

7th July 2025
-------------

* DONE Added emulation of EEPROM storage to PicoSPINet. A single common bank testing with

3rd July 2025
-------------
* DONE Fixed -> adding extra spaces. Push/pop of wrong reg pair

29th June 2025
--------------

* DONE Added VAR word to handle 26 letter var array
* DONE Added SPITIME const to provide a better way to handle SPI timing changes
* DONE Add word for setting spi_time

18th June 2025
--------------

* DONE PicoNet - Basic multiplexing of SPI nodes with echo back interface working
* DONE fix listen command to clock a char out from buffer. 
* DONE Once clock out char is working then can do the rest of the commands

* DONE SPI Net NTP time support. Sets NTP time. Need to get it back
* DONE SPI Net get waiting messages for node from server. Seem to have a clock out issue. SPII always gives zero. Need to use scope.

24rd April 2025
---------------

* DONE new multiplex code for SPI Net gateway can now multiplex in a command and params for the put char to buffer. 

2nd April 2025
--------------

Just been building a second machine to provide a way to test the Pico networking and found I hadn't documented the hook up of the LCD and keyboard properly. So here it is:

# cld1 follows 20x2 lcd pin out
# 40x4 lcd pin to lcd connector
#
# lcd1 header
# 1 gnd
# 2 +5v vcc
# 3 vo
# 4 rs
# 5 r/w
# 6 e
# 7 nc
# 8 nc
# 9 nc
# 10 nc
# 11 d4   pa4
# 12 d5   pa 5
# 13 d6   pa 6
# 14 d7   pa 7
# 15 back light   need link to +5v
# 16 gnd

# where does e2 connect?

# lcd 40x4 con
# 
# 1 db7
# 2 db6
# 3 db5
# 4 db4
# 5 db 3
# 6 db2
# 7 dv1
# 8 db0
# 9 e1
# 10 rw
# 11 rs
# 12 vo
# 13 vss
# 14 vdd
# 15 e2
# 16 nc/vee
# 17 a
# 18 k

Keyboard PCB hook up is reversed!

Main PCB:     4 3 2 1
Key PCB:  + - 1 2 3 4

40x4 LCD hook up

Looking to rear of LCD socket pins labelled to main board connector

  +--+--+  
 2 |13|14|  1
 4 |11|12|  3
 6 |  |  |  5
 8 |  |  |  7
10 | 5| 6|  9
12 | 3| 4| 11
14 | 2| 1| 13
16 |  | x| 15
18 |16|15| 17
   +--+--+

x - VIDCLK pin on VIDOUT connector:

    ^ to back of board
    GND
    +5
    VIDCLK
    VOUT

21st Mar 2025
------------

* DONE CART not setting correct CE lines as shown by tests with picospinet.py. Helps if you use the correct word CARTDEV not CART
* DONE BUG Init of SPI is leaving both bank 1 and cart 1 CE active. Need to do $01 BANK first to set flags correctly. Fix to disable cart 1 CE at init. Yes, in storage_init there was a set 0 on CE which should be high not low
* DONE When switching between BANK and CARTDEV change the spi_clktime between 0 for BANK and default to $0a for CARTDEV
* DONE Hook up Pico and get it talking over SPI to enable networking. If using SPI + CE then can have Pico being hub for a few z80 machines to network together. CE is working now but clock isnt handshaking correctly. Each SPIO seems to send a single bit... Now have some basic SPI node activity working.
* DONE SPI Net Wifi config via Z80
* DONE SPI Net sending messages to nodes and server to batch delivery

23rd Feb 2025
-------------

* DONE Crash on READ past EOF
* DONE Add some constants such as current file open id and file ext that can be used for better data manipluation
* DONE As READ is now only loading one block in at a time, will need to look at the auto code load and have that concat long lines together. Added LREAD to autostart.
* DONE added access to the current block READ so can use with BUPD

9th Feb 2025
------------

* DONE BUG If a non-existing file extent/id is given as param to ERA, APPEND etc then the storage appears to be reformatted!
* DONE BUG If an unknown uword is given for LIST then the system reboots
* DONE add info page word. INFO word.
* DONE ERA is causing a reformat even for valid id. Now fine
* DONE Add high level RECORD word that allows loading of a specific file extent from storage
* DONE Added GETID to get the file id by name
* DONE reduce some of the stack sizes, loops and ret might be a bit too big. Then extend the main data stack
* DONE fix saving more than a single block of file storage. Means to concate multiple blocks? Append is creating more blocks. But is it writing correctly? READ is picking up extra blocks but second block is corrupted. Is READ or APPEND broken? APPEND might be OK. So check READ. It is READ that is broken. Have decided to leave READ as by block, with user deciding if it is worth CONCAT records together.

5th Feb 2025
------------

* DONE Added a low level menu function and moved diags around so that it will be possible to configure settings via storage
* DONE Rework diag menu to be config which loads persissent settings from block 0
* DONE Alternative to EXEC/STKEXEC is a word that presents a menu of uwords to save or load on storage. CONFIG is the word
* DONE Need that MENU word done then! Low level word done, add to user words using scratch buffer to setup ptrs to strings. max 127 menu items
* DONE FIle system words not working. FORMAT, BREAD, BUPD work. But not CREATE, DIR and LABEL. Then check APPEND manually Why? CREATE, APPEND and READ are OK. LABEL is OK. DIR is not working. A push to string to stack fault
* DONE overlap os_new_malloc=os_input
* DONE f_cursor_ptr=store_tmpext
* DONE spi_device_id=store_tmpid
* DONE spi_device=store_tmp3
* DONE spi_cartdev2=store_tmp2
* DONE store_tmp1=store_tmppageid
* DONE store_filecache=store_page
* DONE It appears the config dir scan is corrupting the spi_device byte and poking f5 into it every time. Corruption where? Not normal DIR. Must be in the config code. store_tempid=spi_device_id, store_tmpext=f_cursor_ptr and store_tmp3=spi_device, store_tmp1=storetmppageid. got location overlaps. double check all of the symbols as a few more overlaps.
* DONE Saved setting to enable/disable auto load of words from block 0 as part of auto start
* DONE Add a flag to block 0 to include the bank id to exec at startup
* DONE Add a flag to block 0 to include the file id to exec at startup
* DONE Add auto run of selected file. Prompt and running load but crashes on 'ret'. Even if moved before main autoload still crashes. Got it. storage_read fail has something on stack
* DONE EXEC and STKEXEC not evaluating???? is COLN def non re-entrant? does it care about existing setups? EXEC is OK but STKEXEC not working?  Stack appears messed up. Where is it going wrong?
* DONE Can't use EXEC in code so need another way to trigger stack eval. Make EXEC to take a count of strings?

3rd Feb 2025
------------
* DONE SWAP was flagged as done but it wasnt
* DONE Add a print using ptr on stack: TYPE ( addr c - ). Replaced with a uword in auto start.
* DONE Add better handling of empty stack. Stop execution and return to prompt? Yes jump to cli and not warmstart
* DONE Clear stack word? Make a uword for it if needed??
* DONE Add ALLOT to be same as malloc
* DONE Go through all word code and set key debug spots 
* DONE FORGET might be broken
* DONE WAITK on cpm fails 
* DONE KEY on cpm waits for key press - KEY change below??
* DONE fix loading more than a single block of file storage via BREAD
* DONE BUG Any push following the use of BREAD results in a malloc error... Retest. Or this could mean string longer >64bytes to go to multiple blocks
* DONE Rework the storage system file structure and functions. Remove some of the defunct words.
* DONE have a word to set break point at a DMARKer. Not doing
* DONE KEY was waiting on hardware but changed from cin_wait to cin
* DONE back slash not working on hardware. Alt space. Escaped backslash was there but switched it for dec 92. Apparently 92 is a Yen on the LCD so not possible

31st Jan 2025
-------------

* DONE Test CALL
* DONE Relook at variable use. Setup a VARIABLE word which puts the address on the stack and allows the ! and @ words to access them. Now with SCRATCH to emulate via uwords
* DONE my malloc is failing on free. Not doing as the other malloc is fine.
* DONE Rewrite push code to see if that removes the crashing issue
* DONE Added stack checkpoint macros
* DONE EXEC causes crash. Narrowing down crash point. RSP issue. OK might be a recursive issue.

27th Jan 2025
-------------

* DONE Up arrow to recall last command not working
* DONE FORMAT word
* DONE CREATE word
* DONE LABEL word
* DONE APPEND word
* DONE OPEN word
* DONE READ word any further push of a string (numbers are fine) to stack causes a crash after first use. Appears to be the malloc failing. Using my malloc it works.
* DONE EOF word
* DONE ERA word
* DONE FFREE word
* DONE SIZE word
* DONE Enforce malloc free
* DONE Add direct storage words (BREAD/BWRITE) so I can use soft coded file system ie screen like storage without using the possble flakey file system.
* DONE Added push and pop hl into FORTH_DSP_POP so can remove those from all calls. Will save a few bytes
* DONE Do I have a +! which is increment a memory location by prev item on stack? Handy for the new variable use. Added along with -! for decrement

26th Jan 2025
-------------

* Added NOT word
* Fixed SCROLL display corruption
* Added user word LIST to demo scroll
* Adding vert scroller demo game

24th Jan 2025
-------------

* Start a bit on the sound work
* Work on a small new game 

15th Jan 2025
-------------

* DONE fixed a minor storage error
* DONE create stub of forthcompile in the parser file 

13th Jan 2025
-------------

DONE Add CP/M support to speed up dev even more as could see if RunCPM works so wont actually need any hardware!

12th Jan 2025
-------------

DONE Fix COPY. Now using DUP with type check

10th Jan 2025
-------------

DONE Fix UPPER
DONE Fix LOWER
DONE Fix TCASE
DONE Fix CONCAT
DONE Fix FIND
DONE Remove the need for WORDS as only UWORDS is really useful
DONE Fix scroll words
DONE NOT DOING. CLI input on SC114 is running high refresh. Not using key wait? Because on hardware it handles cursor flash

6th Jan 2025
------------

On SC114 things are much more stable than the original hardware. I've not soldered the power caps. Could that be the reason? Or 
perhaps some bad joints?

Anyway finish off the remaining words and bugs seeing the SC114 platform is faster to turn around an image load rather
than having to program an EEPROM. Of course can test hardware parts like storage. At the moment... 

DONE Add keyboard macro defs on function keys - need them as tokens in the dictionary for easy recall - add as user defs?
DONE  cleanup/free not being done. Is that a problem? Use DSPPOPFREE. Seems to be OK in some situations but with SW it crashes straight away that is using my malloc. Switched back to DK88 and free is working so use this one for now and note bug.
DONE ???? TODO The word THEN appears to be having issues and is being pushed to stack GA is failing too. Suddenly working. Maybe a mem glitch
DONE write a simple screen saver demo to test for runtime crashes
DONE ?DUP word to duplicate if the TOS value is non-zero

1st Jan 2025
------------

DONE change data stack. Each push will be three bytes. First byte is type. If num then num in next two byts, if string then pointer. That will save on mallocs. Other data types will make use of the pointer
DONE Switched back to my malloc for now
MAYBE TODO New malloc that only ever adds to memory with a simple forward pointer
DONE. Fault in STR2NUM word. BUG 'ga' word has an issue with detecting the random number. Is it the logic checks?
DONE At boot detect if key is held for debug, add another key for hardware diags like checking keyboard etc
DONE Add a dot comment to forward the next print position use .>   
DONE have a flag to enable forward cursor from each . or .-
DONE word which allows edit of item on tos - word added but does not copy from stack
DONE words for GPIO access. Stubs created
DONE Sort out the EXEC word so that I can create a simple save and load of UWORDS

PART DONE break out parser so it can be used by LIST, FORGET, WORDS, UWORDS and SAVE 
ACTIVE Do I want to do tokenisation of the keywords next to see if that speeds things up???

31st Dec 2024
-------------

* Now fully working on the SC114. 
* Have removed initial level of malloc calls. 
* Switched to the original malloc function which should be a lot better than mine as it has garbage collection.
* Tested run with and without debug code and 'SW' runs 0.4s faster without debug code included.

27th Dec 2024
-------------

Reviewing code. Objectives for this round of dev is to:
1. Make sure existing code runs on the SC114 so I can easily test
2. Remove mallocs which is slowing the code down
3. Run a tokenisation of the keywords to single bytes which will also vastly speed up the runtime

27th Nov 
--------

Still have memory issues and certainly performance issues I think due to the extensive memcpy and tokenisation of keywords.

Have added support to target the code base for the wonderful SC114 Steven Cousins Z80 computer so I can turn around development cycle.

The next step is to use v5 parser to be closer to how a proper FORTH system should function. For example I don't need to copy and tokenise the words as the space separator for a start will be a delimiter. That will reduce the number of mallocs.

Will go from there.

11th June
---------

Prototype case for Mega now done. Need to fine tune some issues and work out how to make it interlock and not rely on so much glue.

Then back to the OS. In particular loading and saving of uwords and the parser break out. 


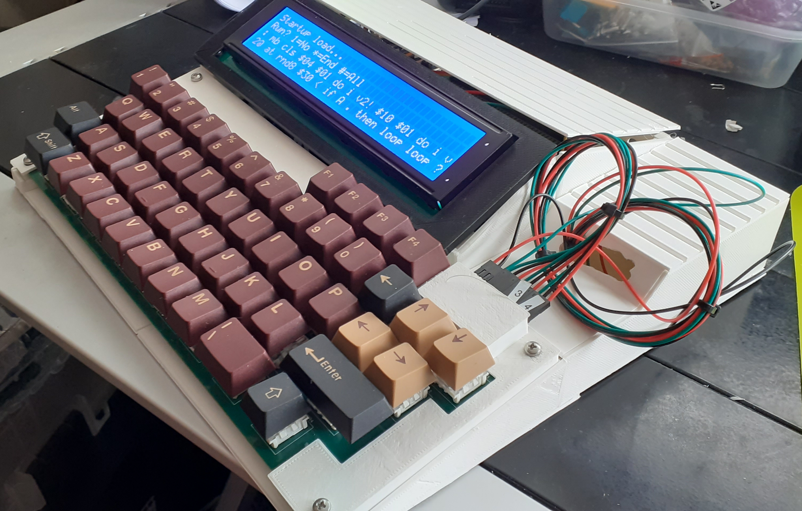
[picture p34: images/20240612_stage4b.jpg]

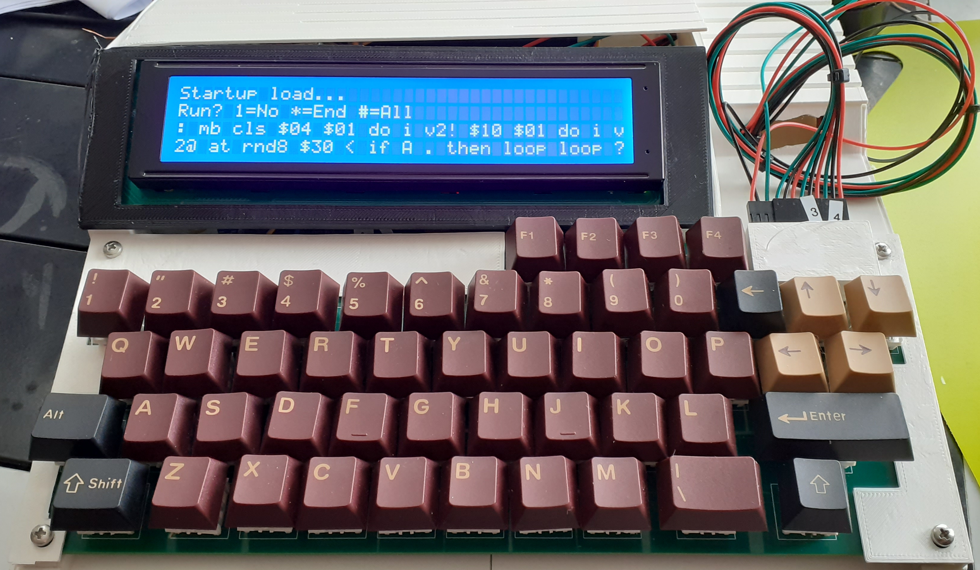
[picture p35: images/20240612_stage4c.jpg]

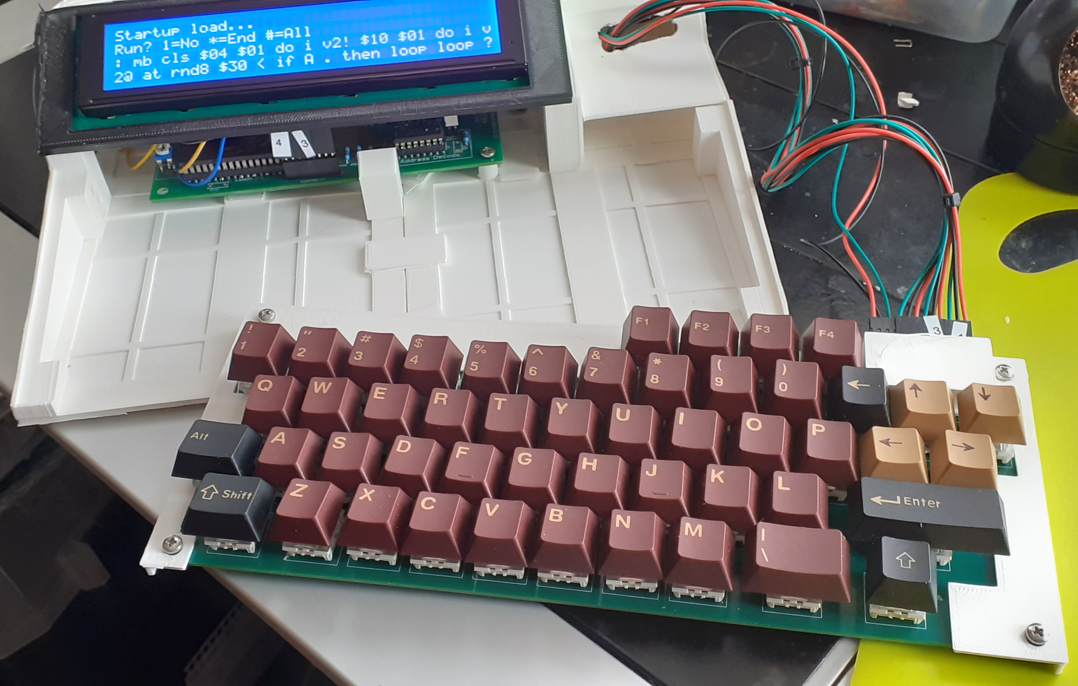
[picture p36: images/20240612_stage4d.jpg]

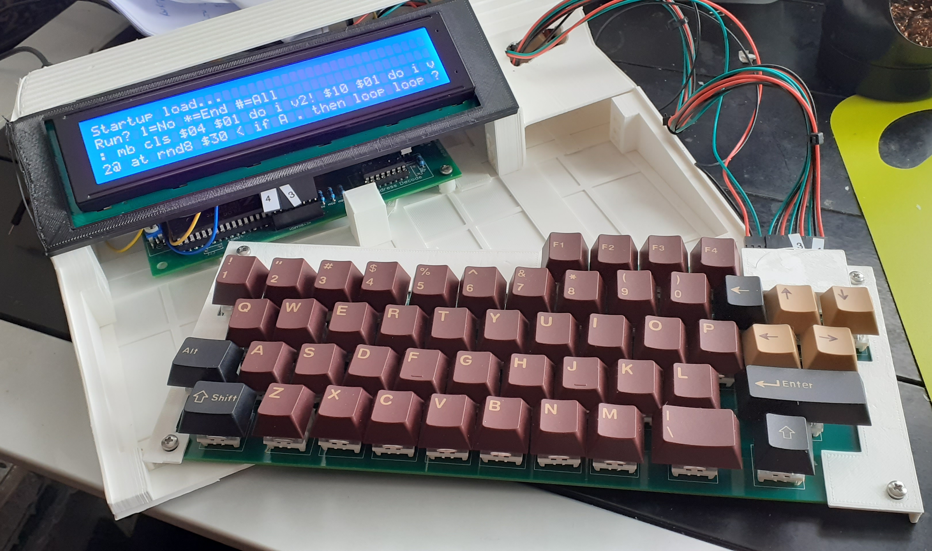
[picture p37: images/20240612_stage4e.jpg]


2nd June
--------

DONE Waiting for delivery of keyboard PCBs.
DONE 4x40 char LCD partly working as a drop in but requires an extra E signal for the second half of the display. Finish coding changes.
DONE Fix READ functions
DONE disable breakpoints on start up unless a key is held down

25th May
--------

Got more of the file control words in place. Up cursor should do last line recall

DONE last line recall messing screen layout
DONE need to add extra bank selection support
DONE Design new keyboard layout PCB now I have key caps etc

17th May 2024
-------------

Can format, create and get a directory on the SPI storage.
Have added some more looping words and using loop stack so DO loops can access the stack

DONE fix a spurious return stack issue on REPEAT...UNTIL
DONE add two char detection for hex numbers
DONE do the append and read spi functions
DONE BUT STILL NEEDS MORE WORK sort out the input box to not do direct screen writes as well as provide better editing
DONE add cursor key support on the keyboard

DONE May have issue with append. If prev file is deleted first zero will be before header rec. Need a new file system. CP/M?

12 May 2024
-----------

Now have keyboard working. Need to tidy up wiring and possibly move it to strip board for some stability. The keyboard
cable needs looking at as currenly a load of link wires masking taped together. 

Next to look at SPI storage...

Stage 4.1
----------

New full sized keyboard to work on:



9th May
-------

Reached v1.0 of the firmware. Now have working (a few odd bugs still) Forth system. Limited features as half of the advanced words have
yet to be finished, but enough works for simple logic, looping, 16bit int maths and user word creation - See word list.

With a minimal working OS next is to return to hardware and create a larger keyboard for easier typing and get the SPI or CF persistent
storage working.

Added a rough build of a case (many slight faults) and FreeCad, STLs and gcode can be found in the case subdirectory. Enhancements as they come.








May 2024
--------

Now have uword creation however the decision to have a PC stored for each exec line so i can handle loops is 
proving to be a problem as the exec of the uword is needing it and it isnt setup right.
I think I need to do another version of the parser and remove this. keep things a bit simple after looking
at other versions of the forth parser. If I use a single pc then see if i can do a compile version and handle
the loops and jumps better.

I have also fixed the version of the assembler for macro support by upgrading. That will help a lot

New approach will be as follows:

1.0 On entry to a word, tos will hold value or ptr (still be macros to maniuplate the tos ) to make things quick
2.0 exec will function differently:
2.1     Op code will flag if the data following is code or jump table to primitives
2.2     Extra op codes to add to deal with very low level things in particular branch and loops  
2.3     Compile to op codes to speed up process (how to deal with saves??? Perhaps dont compile?)
2.4     Keep a running loop/branch word to allow for quick branch/loop jumps
2.5     Single central PC covering all malloc 
3.0 Parser remains much the same. Break each word to a zero term string.
4.0 Data and return stacks remain the same.

Stage 4.0 (DONE)
-----------------

Code a basic core part of an OS which uses the screen, keyboard and storage. A super monitor program. From there could then add
Forth which could provide the drivers for add on hardware.

If the OS has a 'boot' buffer say in the first 'block' of the storage that could bring up the rest of the hardware etc.
Would make adding more hardware easy rather than coding in asm.

Redesigned PCB with LCD, keyboard and storage onboard, add edge connectors etc and produce a 3d printed case.

Good to go then.





...

Working the OS see language defintion etc in FORTH.md

New board now soldered and powered up. Need to debug OS/Language...

...

April 2024

Keyboard layout:

    1       2       3       A
    abc"    def&    ghi$    

    4       5       6       B
    jkl,    mno.    pqr:

    7       8       9      C
    stu;    vwx@    yz?!

    *       0       #      D
    shift   space   Enter
    ' =   < >     + - /
     bs   

Unit testing/debugging

Version 3 of the parser now tokenises the string
TODO need to save the current pointer of next word in the malloc area
TODO dont parse an empty input string
TODO trim space from end of parse string
TODO add the breakpoint to words
TODO pop rsp at end of exec
TODO for string, skip the copy of the double quotes
TODO add data stack underflow guards
TODO change default push type as float as that has no prefix
TODO add a type id word for TOS
TODO add monitor word for full memory and reg dump
TODO add round div word
TODO add .$ to print number as hex word format and not numeric
TODO add case change words
TODO add type conversion words
TODO add a start up feature to bulk run one set of words after another. can use for testing and then use it for auto start up of some builtins + storage boot lists

TODO add dialog word
TODO add menu word
TODO add other UI type words that could be useful
TODO add a means to add binary based words and/or an assemlber

TODO uwords are not exec. need to add the pc ptr for the exec to the start of the exec body area. update preample to reload the pc

Stage 3.2 (DONE)
----------------

Firmware and utility functions: Keyboard, Screen and Storage

Need a video memory area for reading and writing video updates to save on having to keep reading and writing the screen. Or do I? I have a spare line on port A
I could use for read enable of the LCD??? Would that require some strange control stuff? Otherwise easier to use a screen frame buffer to write out.

Also need screen functions for:

* TODO Scroll up and down
* TODO Scroll left and right
* Clear screen
* Position cursor
* Write string
* Read char at pos (using frame buffer so direct memory access)
* Draw cursor
* TODO Can I use control chars to set attributes such as inverse? Might need double byte buffer or certain bits to generate from frame bufffer
* Multiple framebuffers for window layers and function to switch active frame buffer

Keyboard functions:

* Scan keyboard in raw
* Key scan to char conversion
* Abstract away the keyboard configuration to enable different keyboard layouts (e.g. mobile phone style vs full ascii keyboard)
* Key debounce
* Repeat key timer (No repeat)
* Control key functions
* Prompt box with keyboard state indicators

    1       2       3       A
    abc     def     ghi     bs
    ![]     “-      £+	

    4       5       6       B
    jkl	    mno     pqr     break
    $=\     %{}     @#^	

    7       8       9      C
    stu     vwx     yz	
     &:;    *,/     ().?	

    *       0       #      D
    symbol  space   shift  enter

... 

Wired up CF card using schemtics from the wonderful work my Steven Cousins, however card timeouts. Not sure if card, electrical or software releated. Will bake that circuit to the new
PCB anyway and hope for the best

What I have got working at least in prototype using a Pico is SPI read and write to a Microchip Serial EEPROM. If I use the smaller 64k versions I can keep the code simple enough
to provide 320Kb onboard storage and 512Kb cartridge on the PIO port B interface. That works for me and is easier to scale up to using the larger chips just by changing the code
to clock out the additional address data.

Also I have a SPI interface I can use for other stuff too. Could use for a larger screen perhaps? That is possible I suppose. Nice.
If I use say page 0 of the storage array for BIOS data I could have bit switches to enable and disable hardware such as which keyboard to use and if using different
display features etc.

Will now port the Pico python code over to Z80 asm and make sure the SPI is working with some test commands on the CLI. If that works then can update the schemetics and 
fabricate a new PCB for version 4. 

Serial EEPROM code is partly working writing now on the Z80. Dropping some bytes so may be a timing issue. Can work on that.

Still intermittently dropping writes, pretty certain it isn't anything serious. The fact it is
writing proves the handshake is fine. Added read code and that does read the bytes back correctly as
to what is on there. Happy with that.

All that is left to do before committing a new version 4 PCB is go over loose ends such as the
keyboard failing to multi-key press and some odd bits left in my todo list. Will update drawings when off to fab.

And here we are before final bits...

Video

Copied off the firmware code to a new dir for further development of the final OS...

Stage 3.1 (DONE)
----------------

Feb 2024

LCD and keyboard matrix...

Taking the design from the wonderful Stephen Cousins website here I was able to hack
his code about to fit my assembler and some of my support code to produce a result. That validates the code and new PIO circuit and gives me something
to adjust for my own needs that I know works. LCD now working. Keyboard next.

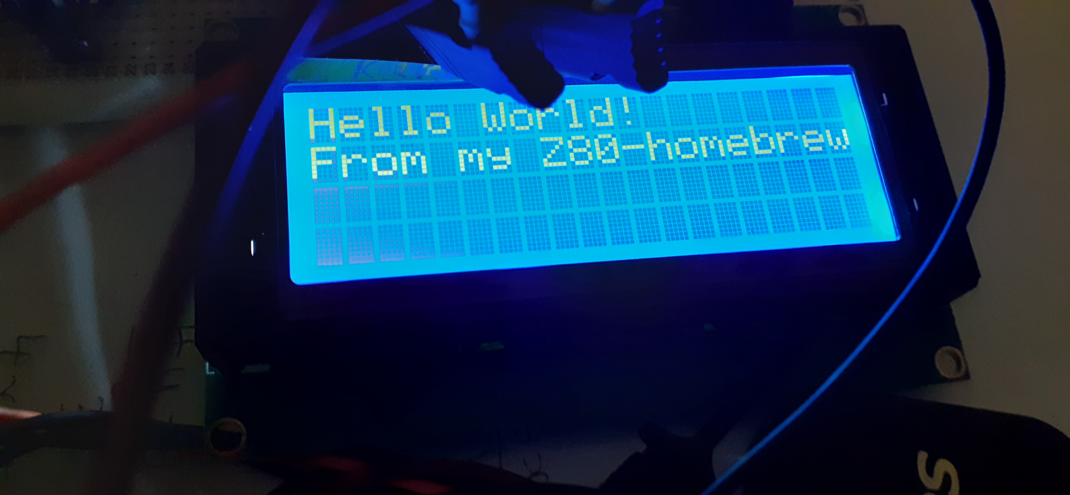
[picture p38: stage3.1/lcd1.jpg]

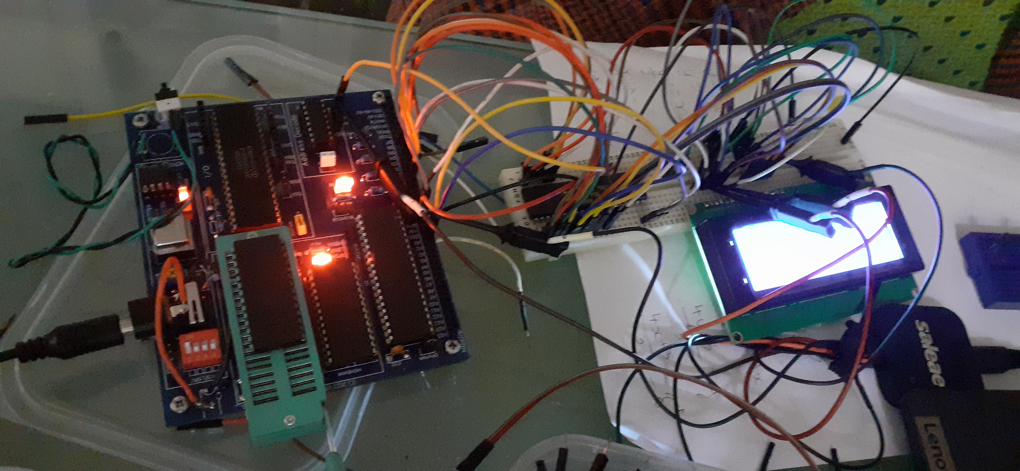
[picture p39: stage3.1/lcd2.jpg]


Basic keyboard via port B mapping of the two nibbles on the port to a 4 x 4 matrix keyboard is working. Have a slight problem with column axis if more than
one button is pressed at once which is odd as the rows are individually emergised. Might be a short or a coding issue. Had to tie the columns to a resistor 
to ground to prevent floating phantom inputs. (Diagram to follow)

At least single key presses work and should be enough to get a basic keyboard working although cumbersome to use. 

Next will be to focus on a set of firmware with utility functinos to support keyboard and screen. After that can then look at external storage.

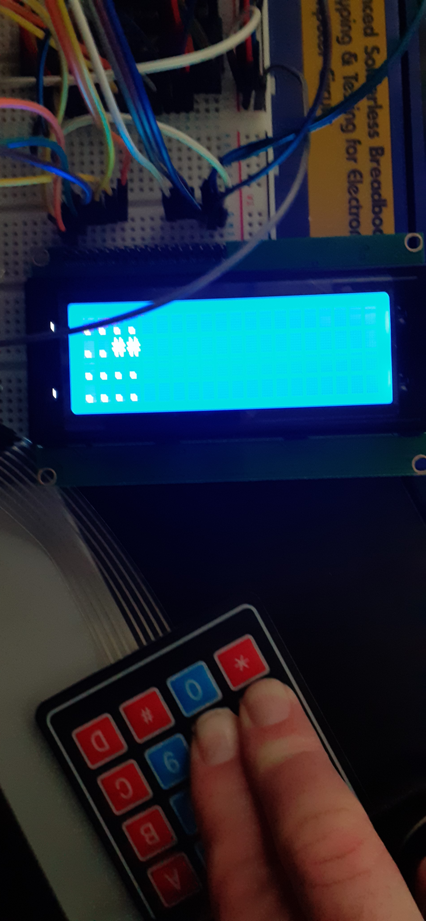
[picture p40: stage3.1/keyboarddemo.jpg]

Video

Stage 3.0 (DONE)
----------------

Jan 2024

Been many months since I last looked at this mainly because of issues with bit bashing the RAM, and I have since located an EEPROM device. July 2023 I created the circuit and PCB in the stage3.0 dir and Jan 2024 got around to testing it (28/Jan/2024).

After discovering a few soldering issues I'm not up to the point of the Mega being able to test the CPU stepping through and using simulated RAM/ROM as well as checking that the address decocoder can select the various devices and memory banks:

	Device A - out (001h), a
	Device B SIO - out (040h), a
	Device C - out (080h), a
	Device D - out (0C0h), a

Next step is to attach RAM, ROM, and SIO and write some code to control the SIO with real clock speeds (will need to attach the scope to monitor 

...

Found PulseView and https://github.com/dotcypress/ula via the Rasp Pico can give me 16bit bus. Also has op code decoding of the data bus which is handy. Though had to compile from code due to a bug in USB devices that surfaces after 5.11 kernel. Odd but it eventually worked and saved me upgrading my four probe Saleae to 16, or getting more than one as I could just throw another Pico at it and get them to trigger from the same pin.

Did show that while RD and M1 and some address pins are broadcasting data, nothing is appearing on the data bus. 

Checked solder of pins on the ROM. Happy that the signals are leaving the CPU as they appear on the bus connector. Do they reach the ROM? Yes all pins between sockets and the bus I'm tapping into reach

Check continutity of address and data pins between Z80 and ROM socket. Yes, ditto.

But.... Caps appear to not supply power which is odd considering they are the same as the CPU. Bypassing them and I now see signals on the data bus. How odd.

While I work out why the caps are a problem I now need to make sure the CPU is actually executing the ROM correctly...

...

Don't think I can trust the scope reading the data bus. So I wrote a bit of code that reads and writes to the high memory bank and with lots of NOP and a slow clock it is possible to watch it run and flash the high bank LED during those operations. To make sure it is not random code then added a count down loop followed by a HALT. The code on multiple runs functions the same way each time. I would count that as a success and proves the CPU is running code realisbly.

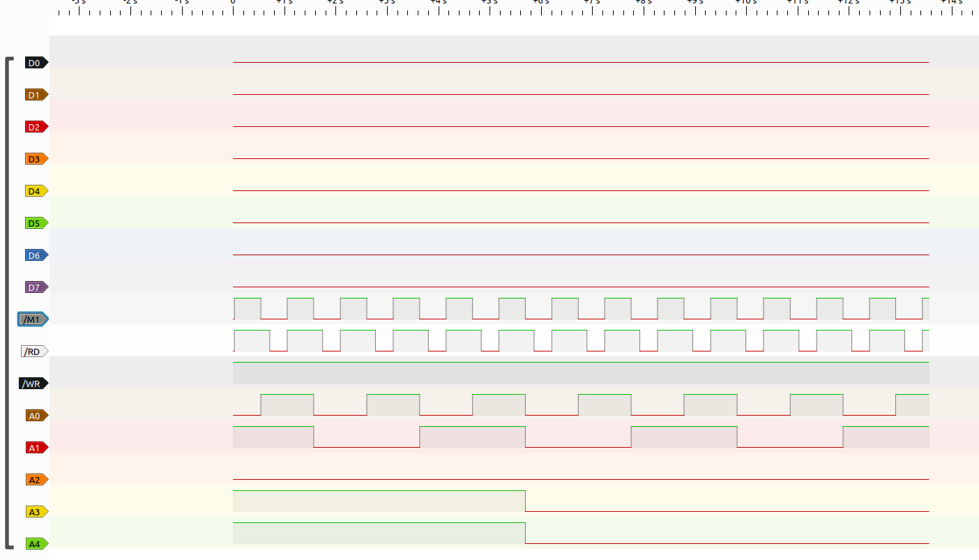
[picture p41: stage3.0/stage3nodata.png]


And here is the code  running 

We have a functioning CPU, ROM and RAM.

That I think then marks the end of testing the PCB functions other than getting the SIO working, which I know at this CPU clock cycle of approx 14HZ won't be fast enough for serial comms to work. 

I will instead look at adding an LCD screen to get some kind of proof more extensive code works, then maybe add a keyboard matix for scanning. Then go from there.

Let's draw a line under this stage of proof.

Happy now!

#2023-07-11# 

Been a while since I've touched this. Had to tear most of it apart to try and remember what is broken. Turns out clock and CPU board are possibly OK.
Memory board may have some address line dry joints. Have been looking at using real RAM but with lack of an EEPROM programmer for ROM I've looked
around for Ardiuno Mega programmers. Mixed results for some reason. Intermittent data loss or error writing and reading. Then I've had a try with
battery backed RAM to help and that seems to hold charge OK. 

Found another Z80 simple system using the SIO so had a look along with a Mega simulated RAM/ROM, hacked that about a bit to do extra stuff and happy
that what I'm doing is viable. Though Mega clock speed is well below the min clock speed for the SIO testing to remote terminal so need to get
the RAM loaded with a monitor code that may or may not work and try it at full speed. 

Lacking so many bits for this....

Stage 2.5 (DONE)
----------------

Well that week was painful. Have to say easyEDA is not ideal for doing strip board layouts, lack of 
random wire routing prevented all the traces being laid. So in the diagrams any feint blue lines
and red ones are wires that need to be routed over the board surface. Horizontal blue lines are stripboard
tracks. Also some passives (resistors and caps), all LEDs and three diodes take up a lot of room and in 
this easyEDA don't allow for adjusting the leg positions which really helps with stripboard
so some of them on the board layout are 'floating' with I hope some clue about where the should go
if you adjust the legs. The white blocks are track cuts. All looking from front side of the board.

I would say that the board layout gives approx position for the bits and some of the key connections.
This should be enough to help wire it up. 

The multilayer idea has been scalled back a bit to keep part costs down as board and more so the
header strips are a little expensive for some reason:

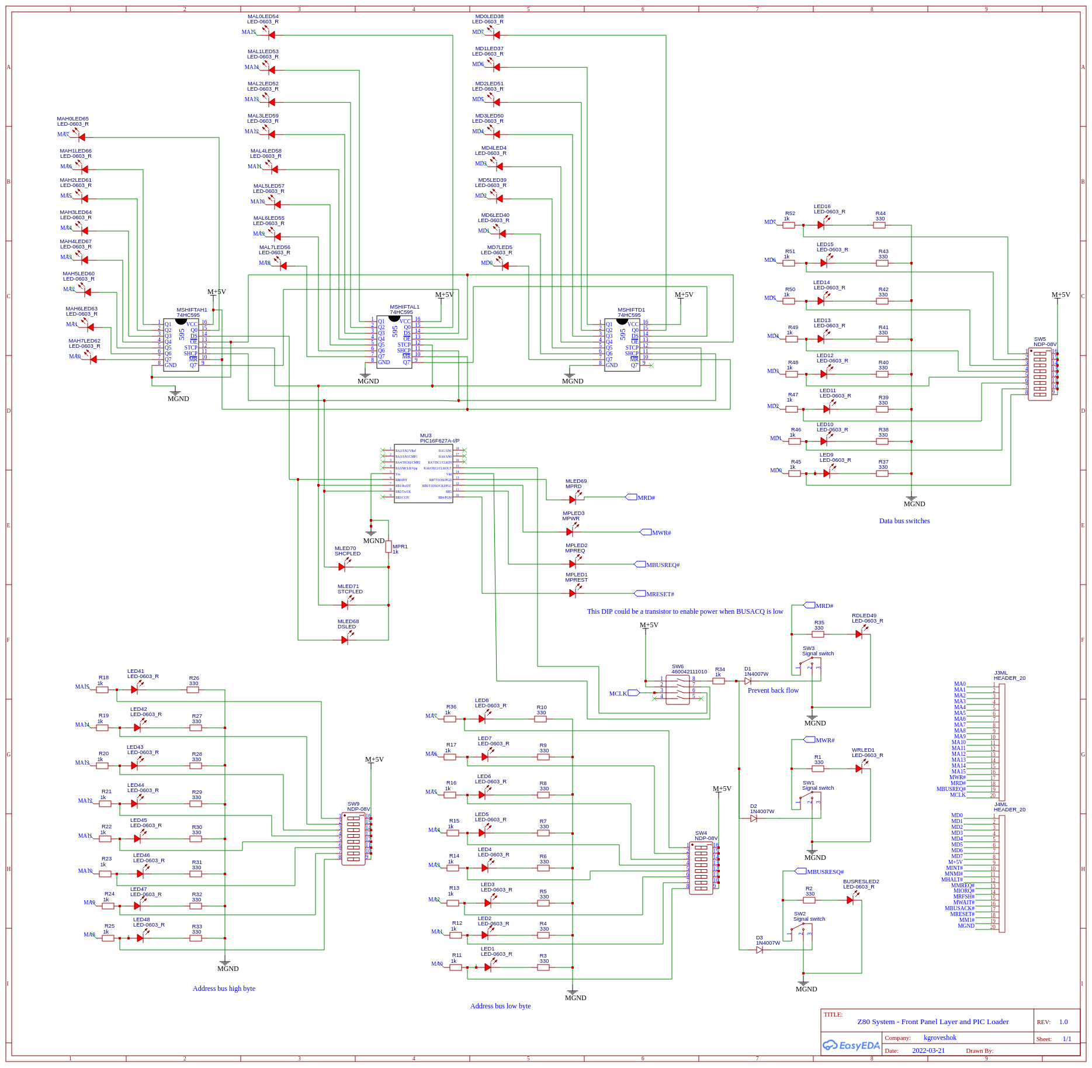
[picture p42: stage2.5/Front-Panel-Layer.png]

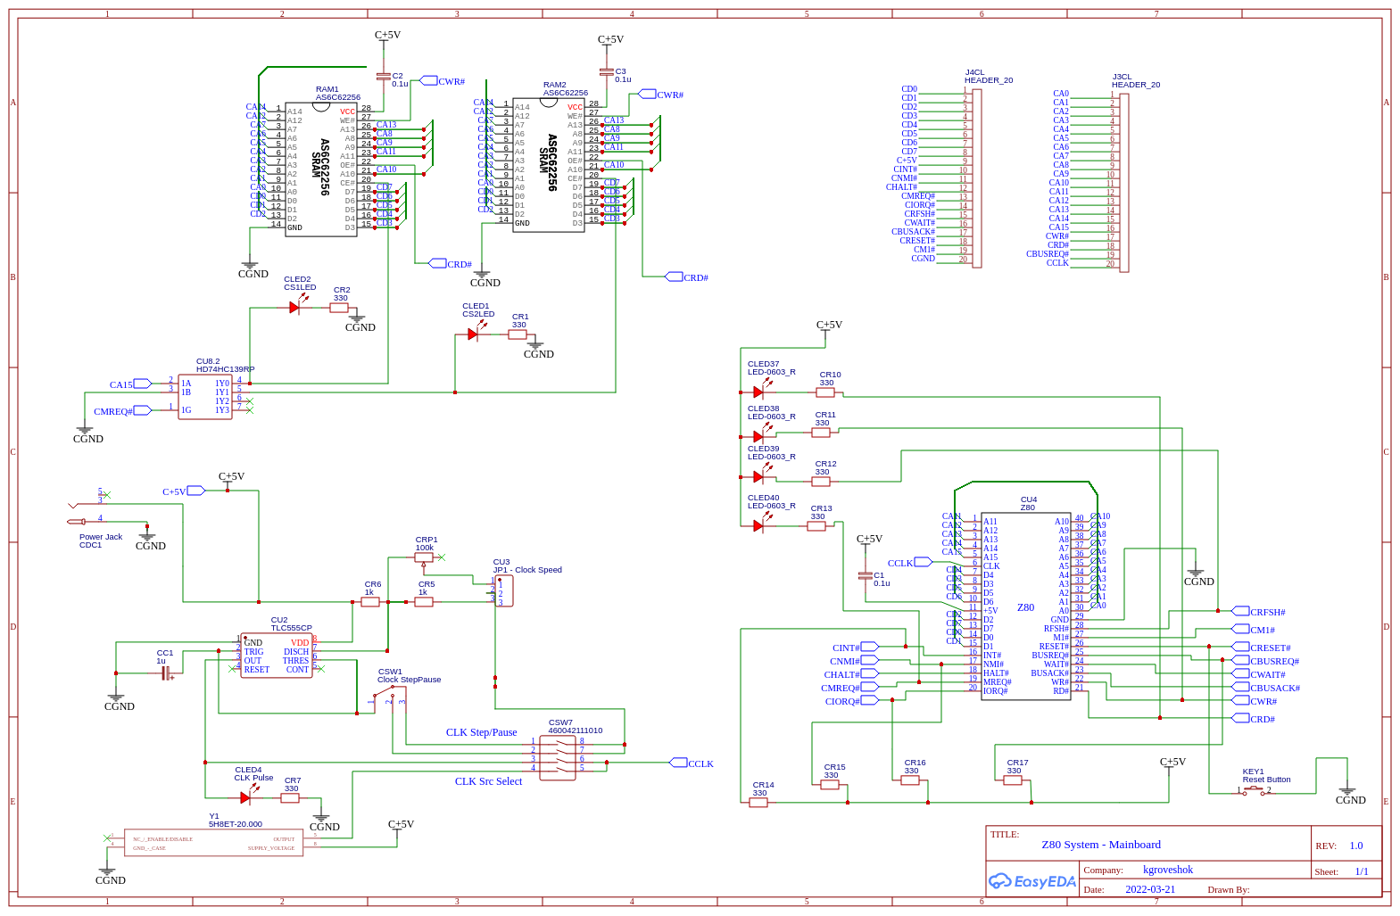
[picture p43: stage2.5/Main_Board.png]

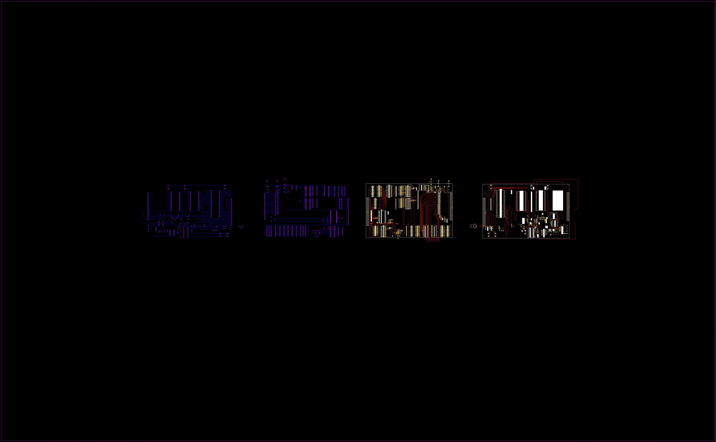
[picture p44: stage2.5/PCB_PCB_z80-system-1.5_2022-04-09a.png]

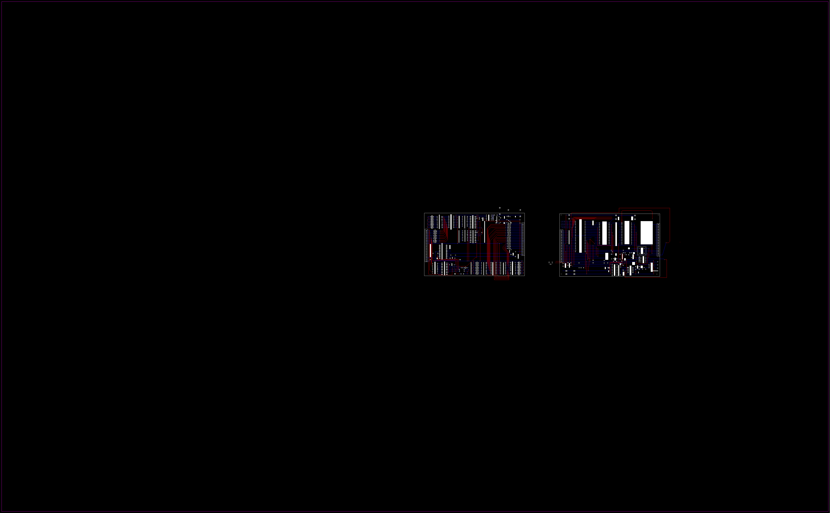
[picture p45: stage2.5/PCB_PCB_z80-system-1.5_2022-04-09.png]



Hopefully will begin assembly soon. I will take loads of pictures of my protoytype too as
that will help in checking my wiring.

NOTE: After I began to solder things up I noticed a number of problems on the board. I've 
updated the details above on this schematic:

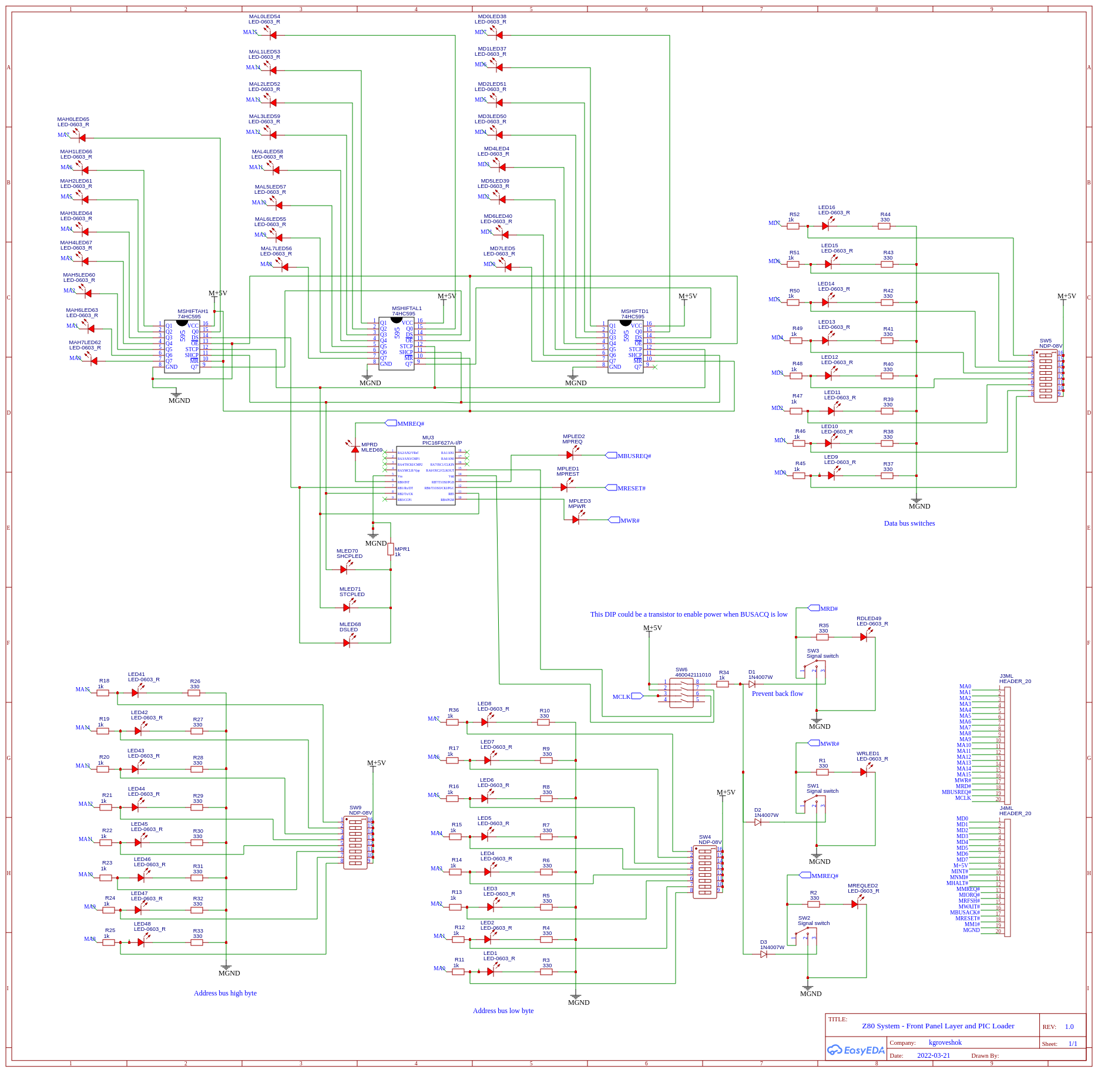
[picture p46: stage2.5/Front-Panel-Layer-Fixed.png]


Most important is it won't all fit so have had to move things around a little. 
Another is that a front panel switch previously said MBUSREQ# but that should actually 
go to MREQ#.

Further problems were also found in less than ideal arrangement of pin outs for the PIC.
I've therefore rearranged the allocation and this will affect the coding of the PIC.

Shift Reg DS now on PIC pin 7, SHCP on PIC pin 12 and SPCP on PIC pin 11. PIC pin 6 is now MREQ#,
PIC pin 12 now RESET#, PIC pin 13 now BUSREQ# and PIC pin 10 is WR#. That resulted in one spare LED
and no LED for the DS pulse.

I would then advise not following my stripboard layout and use it as a guide as to rough locations.
The switches in the top right were way too tight and coupled with my poor soldering skills 
(improving after all this though) it forced me to relocate one to the middle of the board which is now
the MREQ#.

Photos of construction below of the front panel without the PIC as that was being reflashed with 
changes for the new pin layout:
 
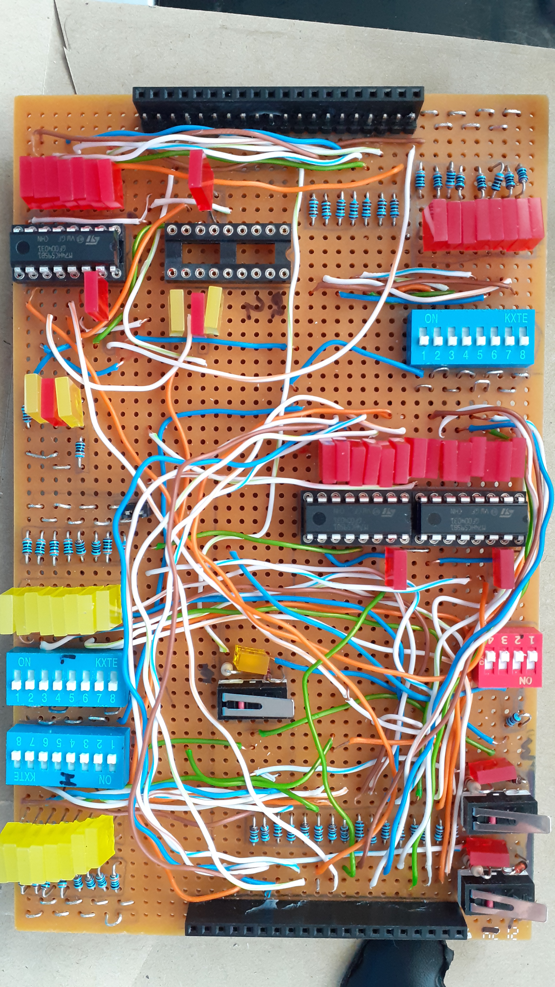
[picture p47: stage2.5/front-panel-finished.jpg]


The red four switch DIP switch has so far two features active:

* 1 - Enables power to the switches when in front panel programming mode - I could really do with
replacing the manual switch with a transitior which activates the power when the BUSACK# line goes
low. 

* 2 - Powers on/off the PIC

* 3 - Not yet connected, enables direction of the PIC clock to the CLK pin as yet another clock source.

* 4 - Not connected.

Next will be the main CPU construction now I know the front panel is working as that is
the most complex of the wiring - really tested my soldering skills!

More mess.... Halfway wiring up the main board discovered I've made some mistakes in the
reverse engineering of my bread board prototype. Going to have to redraw and work out
how to get around my mistakes with what I've already wired. Drat.

Updated main board with the fixes for the wrong LED taps etc:




Both boards now built, however there is a slight bug in the main board. I suspect I have either
missed a track cut or put a wire in the wrong hole. I will have to track that down I suppose!

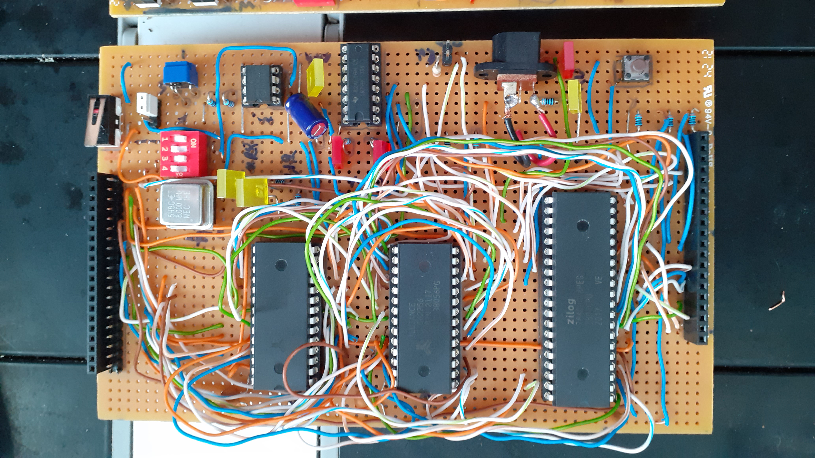
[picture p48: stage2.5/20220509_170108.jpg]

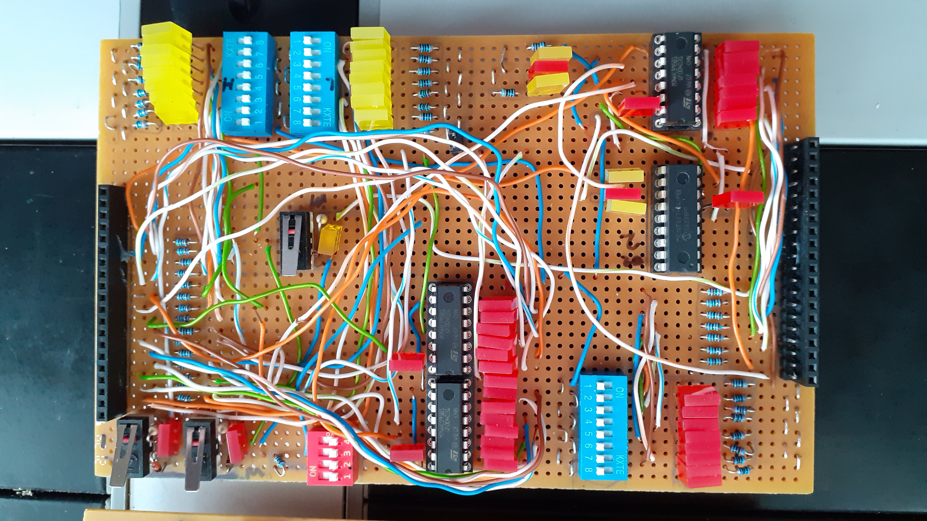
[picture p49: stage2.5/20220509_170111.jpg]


There still appears to be a problem. The BUSACK LED is still flashing, in fact many of the other
LEDs are flashing in sync with the clock. I suspect something either power related, or there is
a problem still with BUSREQ line and a constant on and off of BUSREQ. I can't see any solder 
bridges and continuty of the lines work out right. 

What I think I will do and this is very annoying is to redesign for a less dense set of boards,
just have say CPU is on one board, clock on another, memory on another. That way I can break
down the issue and hopefully reduce the amount of interference across tracks.

....

I've now rebuilt the clock and CPU boards. Having tested them against the breadboard prototype
and the initial stripboard all appears fine. Perhaps I didn't have a problem???

Anyway now continuing with the memory board build and will then check that. 

Here is a side-by-side setup of the two new smaller boards stacked (timer on the bottom and CPU
on top), along with the very definately working original 'front panel' board so I can watch 
the address lines ticking up the PC location and proving things are working.


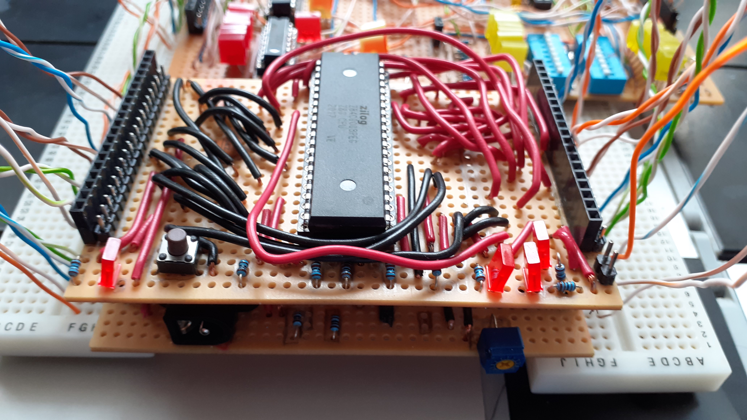
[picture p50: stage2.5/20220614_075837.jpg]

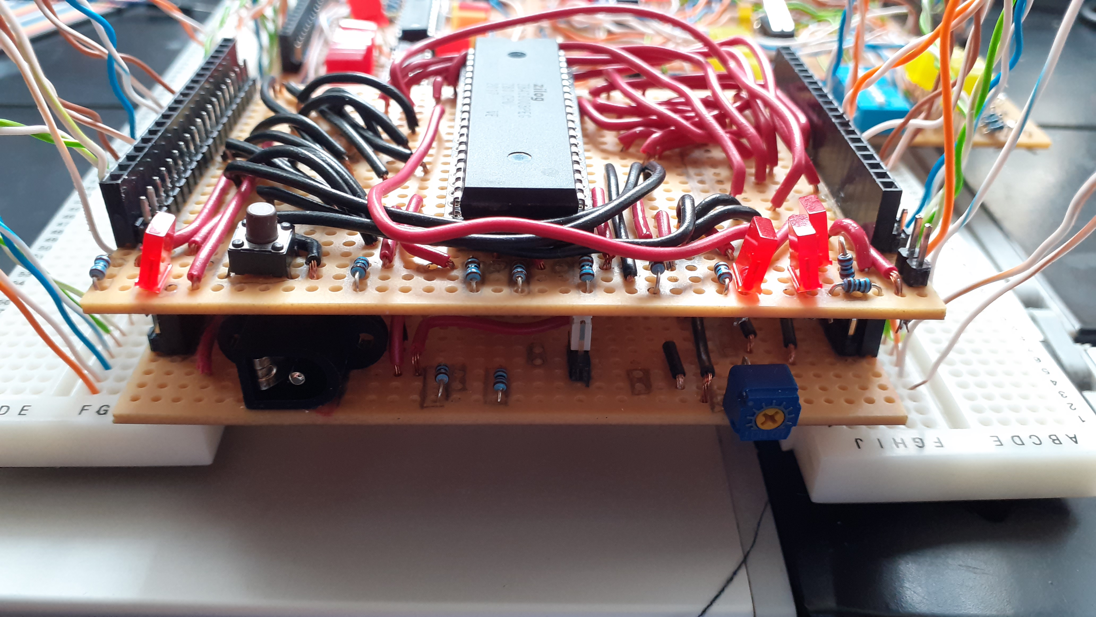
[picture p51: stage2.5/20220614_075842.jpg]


Been pretty delayed lately but finished off the memory board:



Have discovered the problem with this new board. The BUSREQ# line is floating and/or not tied right (perhaps even got this pin and BUSAQ# confused) which is causing the CPU to give up the bus and then recover - hence the flashing.

And at long last we are almost  back on track. Fixed a couple of odd hardware bugs. Mainly because I soldered wires in wrong holes. Grrr. Because I also feel that the front panel of the original
might be a bit suspect (although I've not tried it since I fixed the board) I knocked up a quick stripboard with LEDs on the data and address lines to make sure things are working. In the 
photos below you can see this board sat on top of the board stack which has the clock and power on the bottom, the CPU on the 2nd layer, memory on the 3rd.

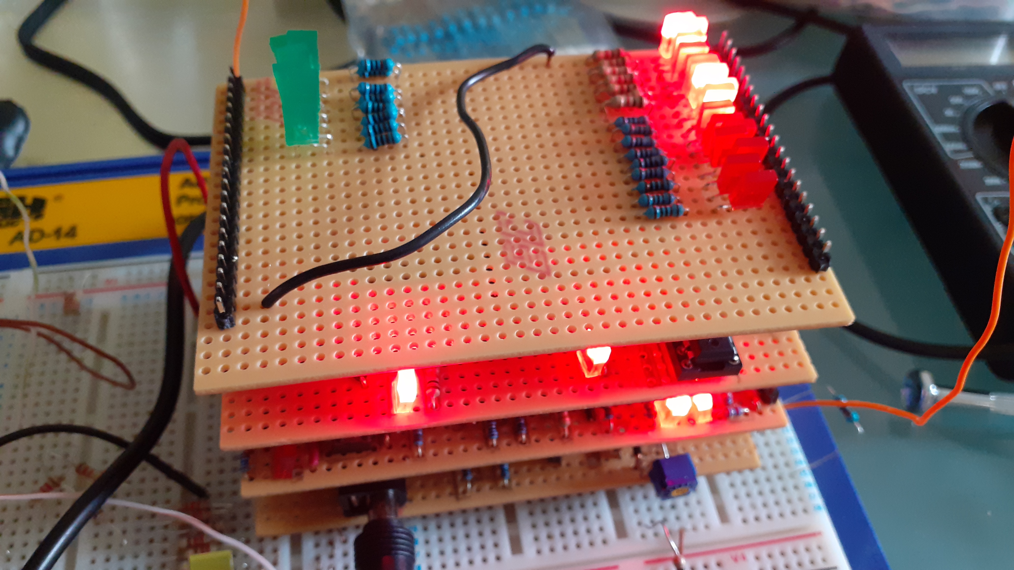
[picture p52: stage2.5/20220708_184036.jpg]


Now, if I'm no longer using the original front panel which has the PIC memory bit basher loader on it, I then need to build a new PIC board. In the picture below the new PIC
test circuit is being constructed to the left of the Z80 stack.

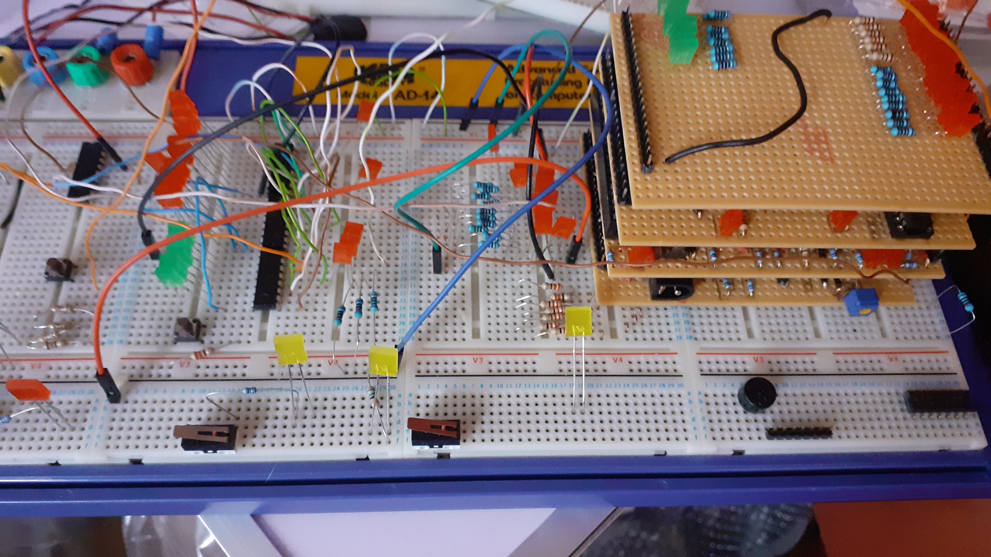
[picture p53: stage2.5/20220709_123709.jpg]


Once I finished the PIC loader I will be in a position to move to stage 3.0....

Stage 2.5 (DONE)
---------------

The breadboard is becoming quite full, and with the next stage focusing on RS232 where timing is 
important, I think it might be a good idea to finish off the low speed parts first, then
moving as much as I can off of the breadboard to strip board for the space and more stable 
circuit at speed.

In this stage then I want to perhaps add a second 32k RAM chip as the high address bit wire is
currently unconnected. That will then provide a full 64k RAM, as well as the prospect that I
could swap out either RAM and replace with a ROM further down the line. 

I will also obviously add a couple of NAND gates to switch between them. I may also future
proof the setup and consider tapping another address line and splitting the top half into 
smaller sections so that I can slip in external device memory maps. That will depend on the
requirements for the DART, SIO, PIO chips next. Of course moving to strip board using the
stacking method I'm considering means that if I need to change page addressing, I will only
need to swap out the card(s) affected and not the whole board. Bonus!

To do this I *REALLY* need to document the board! :-) I will be using maybe Eagle or easyEDA for 
the main schematic and then ancient VeeCAD for the strip board layout.

Here we go, first draft. Not pretty as a number of things I need to clean up and be consistent
about. But you should get the gist of it I hope. Also as far as the address decoder I don't have
the chip that I found would make life easier so I may just sling in a PIC (yeah I know over kill)
which can be adjusted in light of any requirements for the next stage. In the end I will of
course replace with a fixed device when I know what is going on. This is a work in progress
after all and not a finished project!

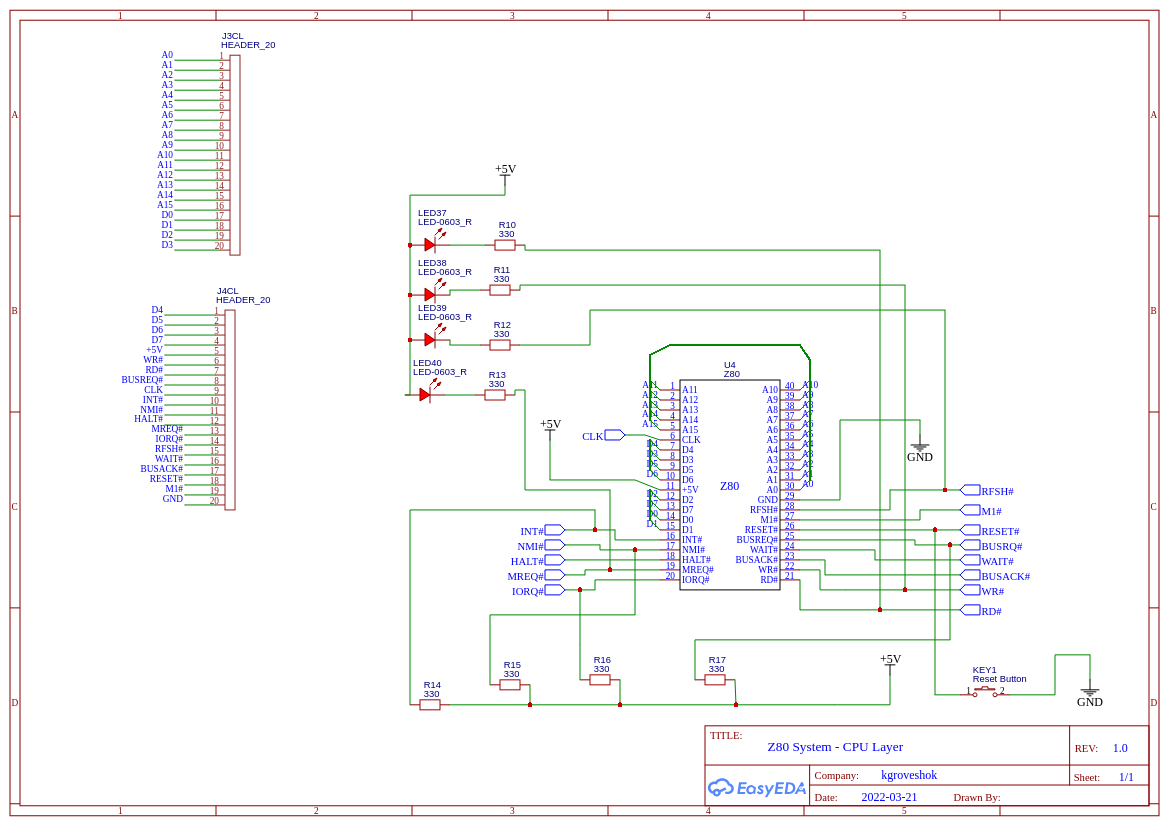
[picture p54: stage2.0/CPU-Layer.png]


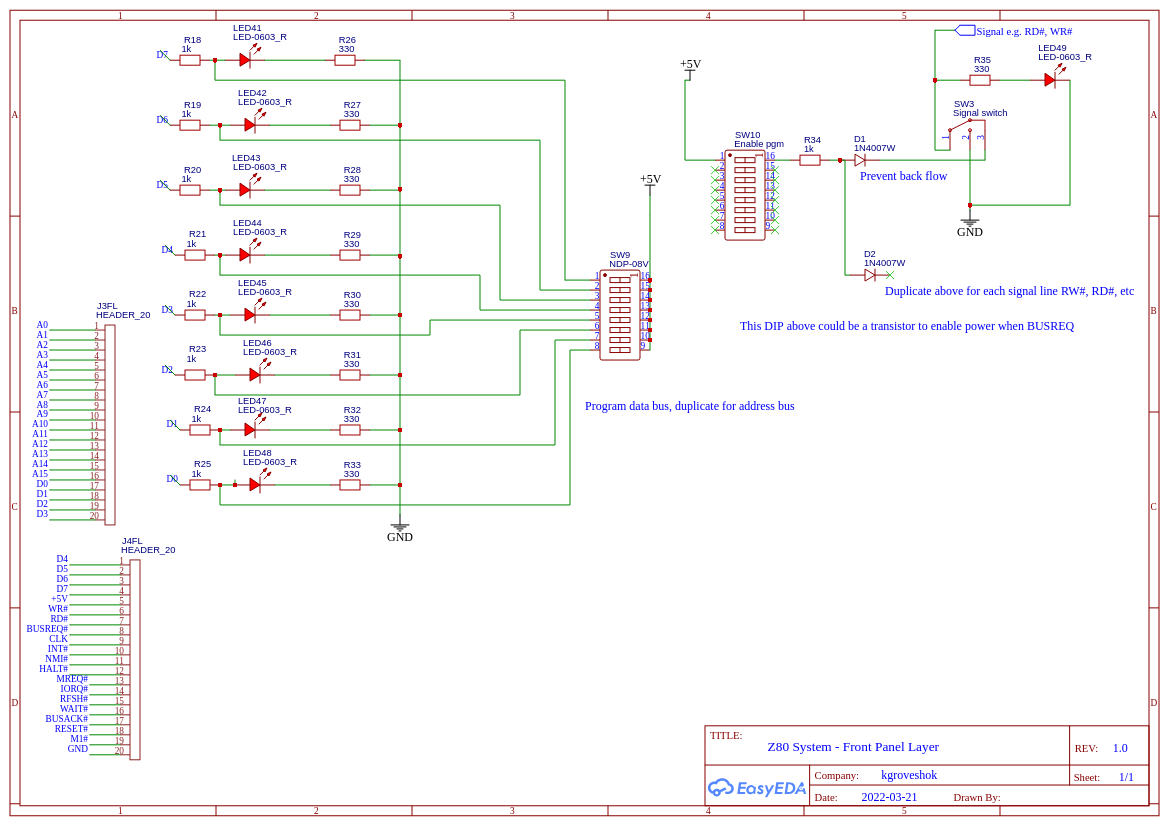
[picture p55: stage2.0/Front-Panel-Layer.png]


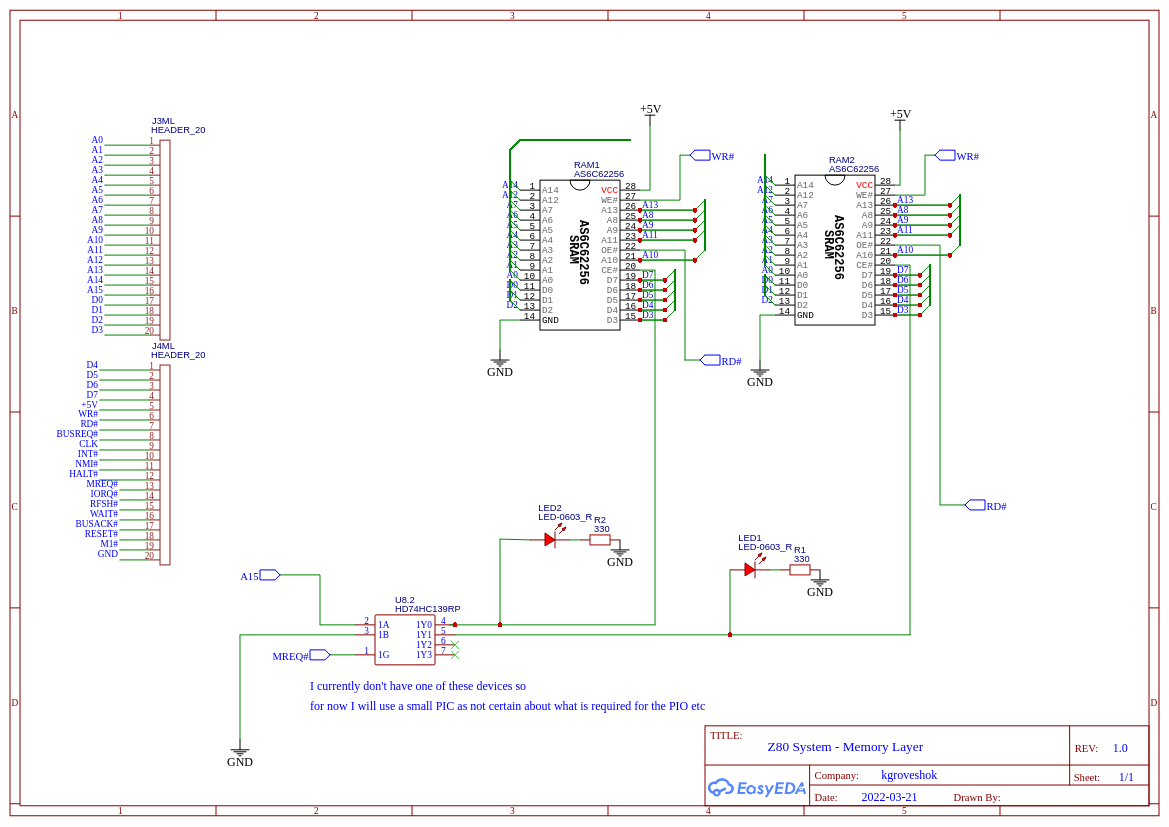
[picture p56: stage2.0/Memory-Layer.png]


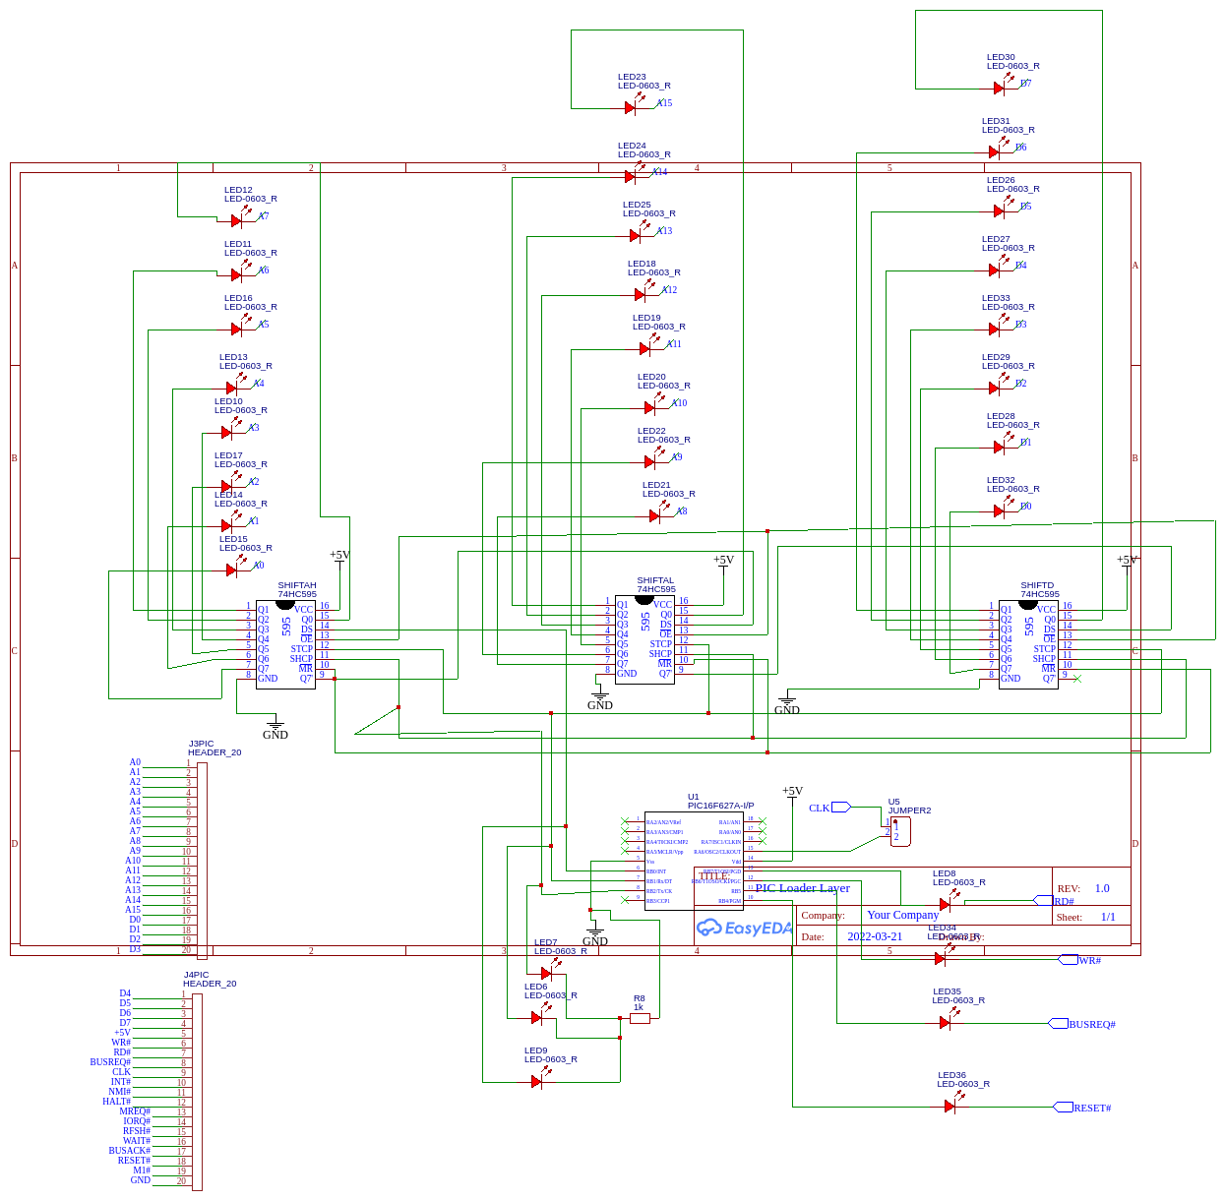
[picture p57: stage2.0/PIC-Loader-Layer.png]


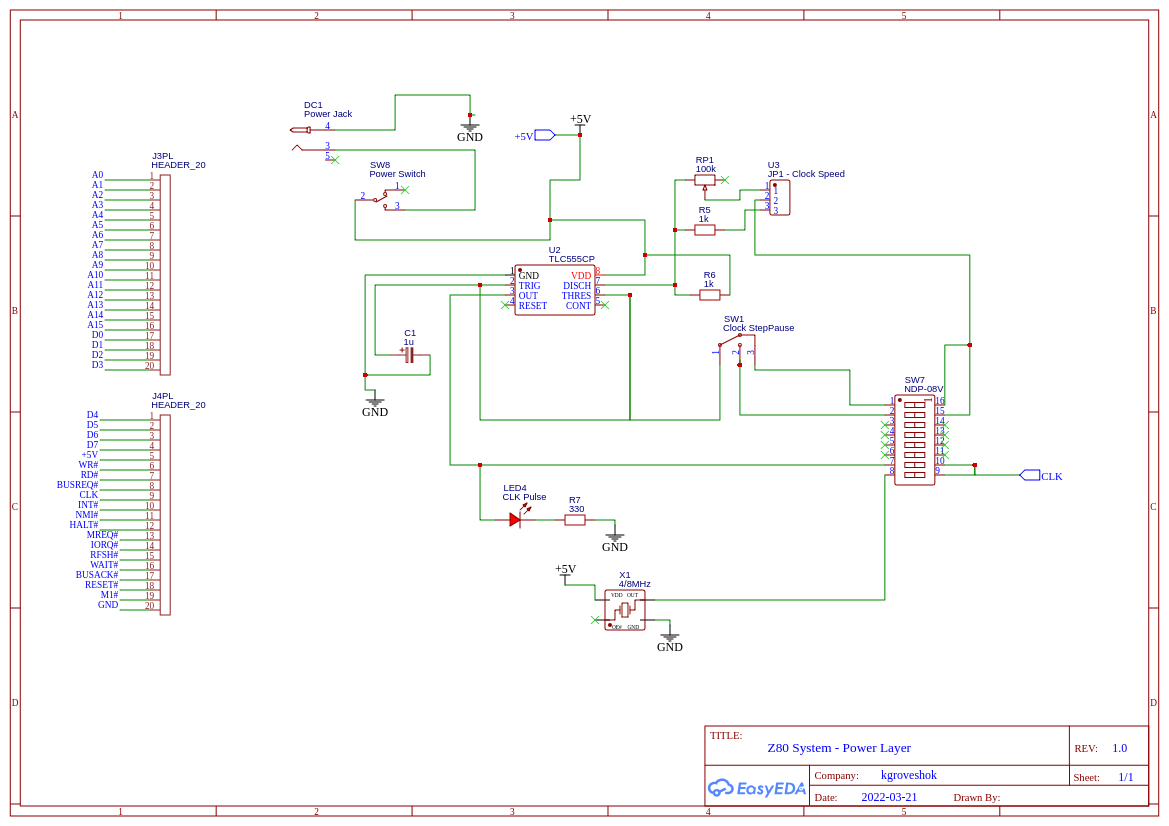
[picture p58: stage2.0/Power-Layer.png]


PDF versions can be found in the stage2.0 directory too.

Stage 2.0 DONE
--------------

Now I have the sequence to program RAM by hand, speed it. Because I don't have an (E)EPROM 
and programmer I will put a PIC to act as a bootstrap loader at Z80 startup and bit bash a simple 
monitor program into RAM which I can then use to load further code.

First part will be to load the same simple program as used in the the Stage 1.5 test. Once that
electronics is working I can then write larger programs to boot strap which will be where Stage 3.0 
comes in...

Testing shift register... [Video]

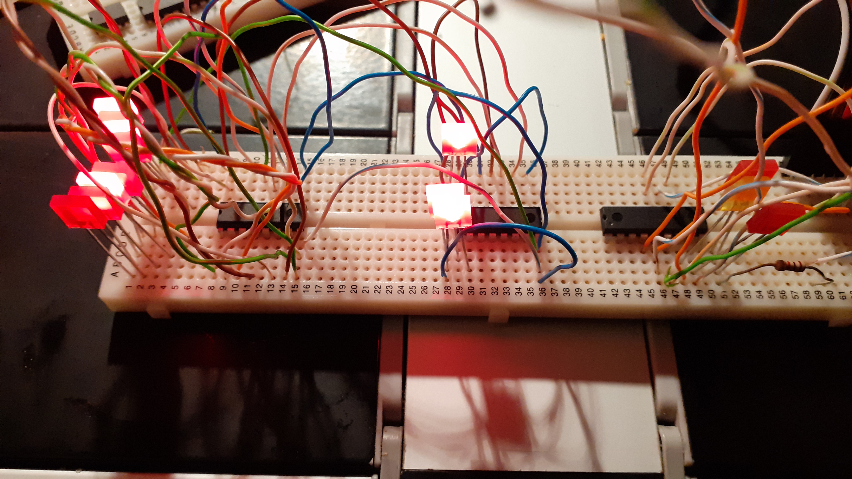
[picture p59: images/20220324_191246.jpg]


Testing shift reg sequence [Video]

Ready to boot strap! [Video]

Another go which does'nt quite work... [Video]... Turns out 
that powering down mid shift register loading fixes it. Will do a better fix with the 
coding on the PIC :-)

Stage 1.5 DONE
--------------

Resolve the issue I have in manual bit bashing machine code into RAM.

Now fixed in [Stage 1.5]

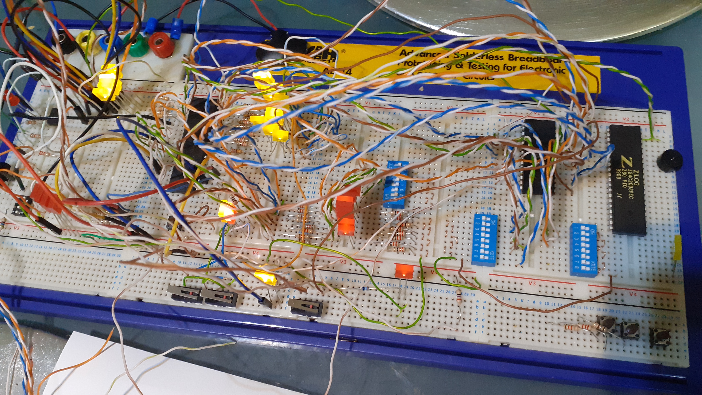
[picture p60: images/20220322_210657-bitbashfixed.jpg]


Stage 1.0 DONE
--------------

Create a basic breadboard circuit with CPU, clock (for now 555 so I can watch it do things) and RAM.

The CPU is executing whatever random code is in the RAM at start up. Looks pretty with the flashing lights.

See this stage at [(Stage 1)]



Documentation Tasks
-------------------

TODO Add loads of example Forth code - added some examples in word markup generation - extract auto start code

TODO update schematics with 4x40 LCD and the location of the spare E link

TODO update schematics with better design for the next version?

TODO New case for Mega

TODO Tidy up code base: Make sure functions in suitable files 

TODO Tidy up code base: Reindent

TODO Tidy up code base: Remove redundant code/comments

TODO Add word documentation

TODO Add full system documentation

Future Directions
-----------------

Networking extension

Using SPI to connect with a Pico/ESP on the cart port...

SPI protocol to be something like...

Host sending

Byte $01 $xx  - Connect to $xx in address book
Byte $02 $xx  - Sending data ext

Byte $03 $xxxx $xx  Save byte to 
Byte $04 $xx  Bank selection

Poll to read any incoming data

DONE Power. Could I add battery support so it is portable? Recharge circuit I would need to add though could pull that in from a Pi battery charger. Easy. Using Rpi Lipo boards.

Trying out:
https://shop.pimoroni.com/products/lipo-amigo?variant=39779302539347

Or would normal battery packs work long enough to make it worth while? 

More devices on the external cart:

* Basic networking across the SPI bus between other Z80 instances?
* RTC
* Sound
* Relay board for GPIO use
* Pico for Wifi networking to internet etc
* Enchance the SPI for display/keyboard

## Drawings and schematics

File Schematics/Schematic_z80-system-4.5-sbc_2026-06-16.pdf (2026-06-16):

# CF Card Interface

Solid State Storage/SPI Bus | Solid State EEPROM Array

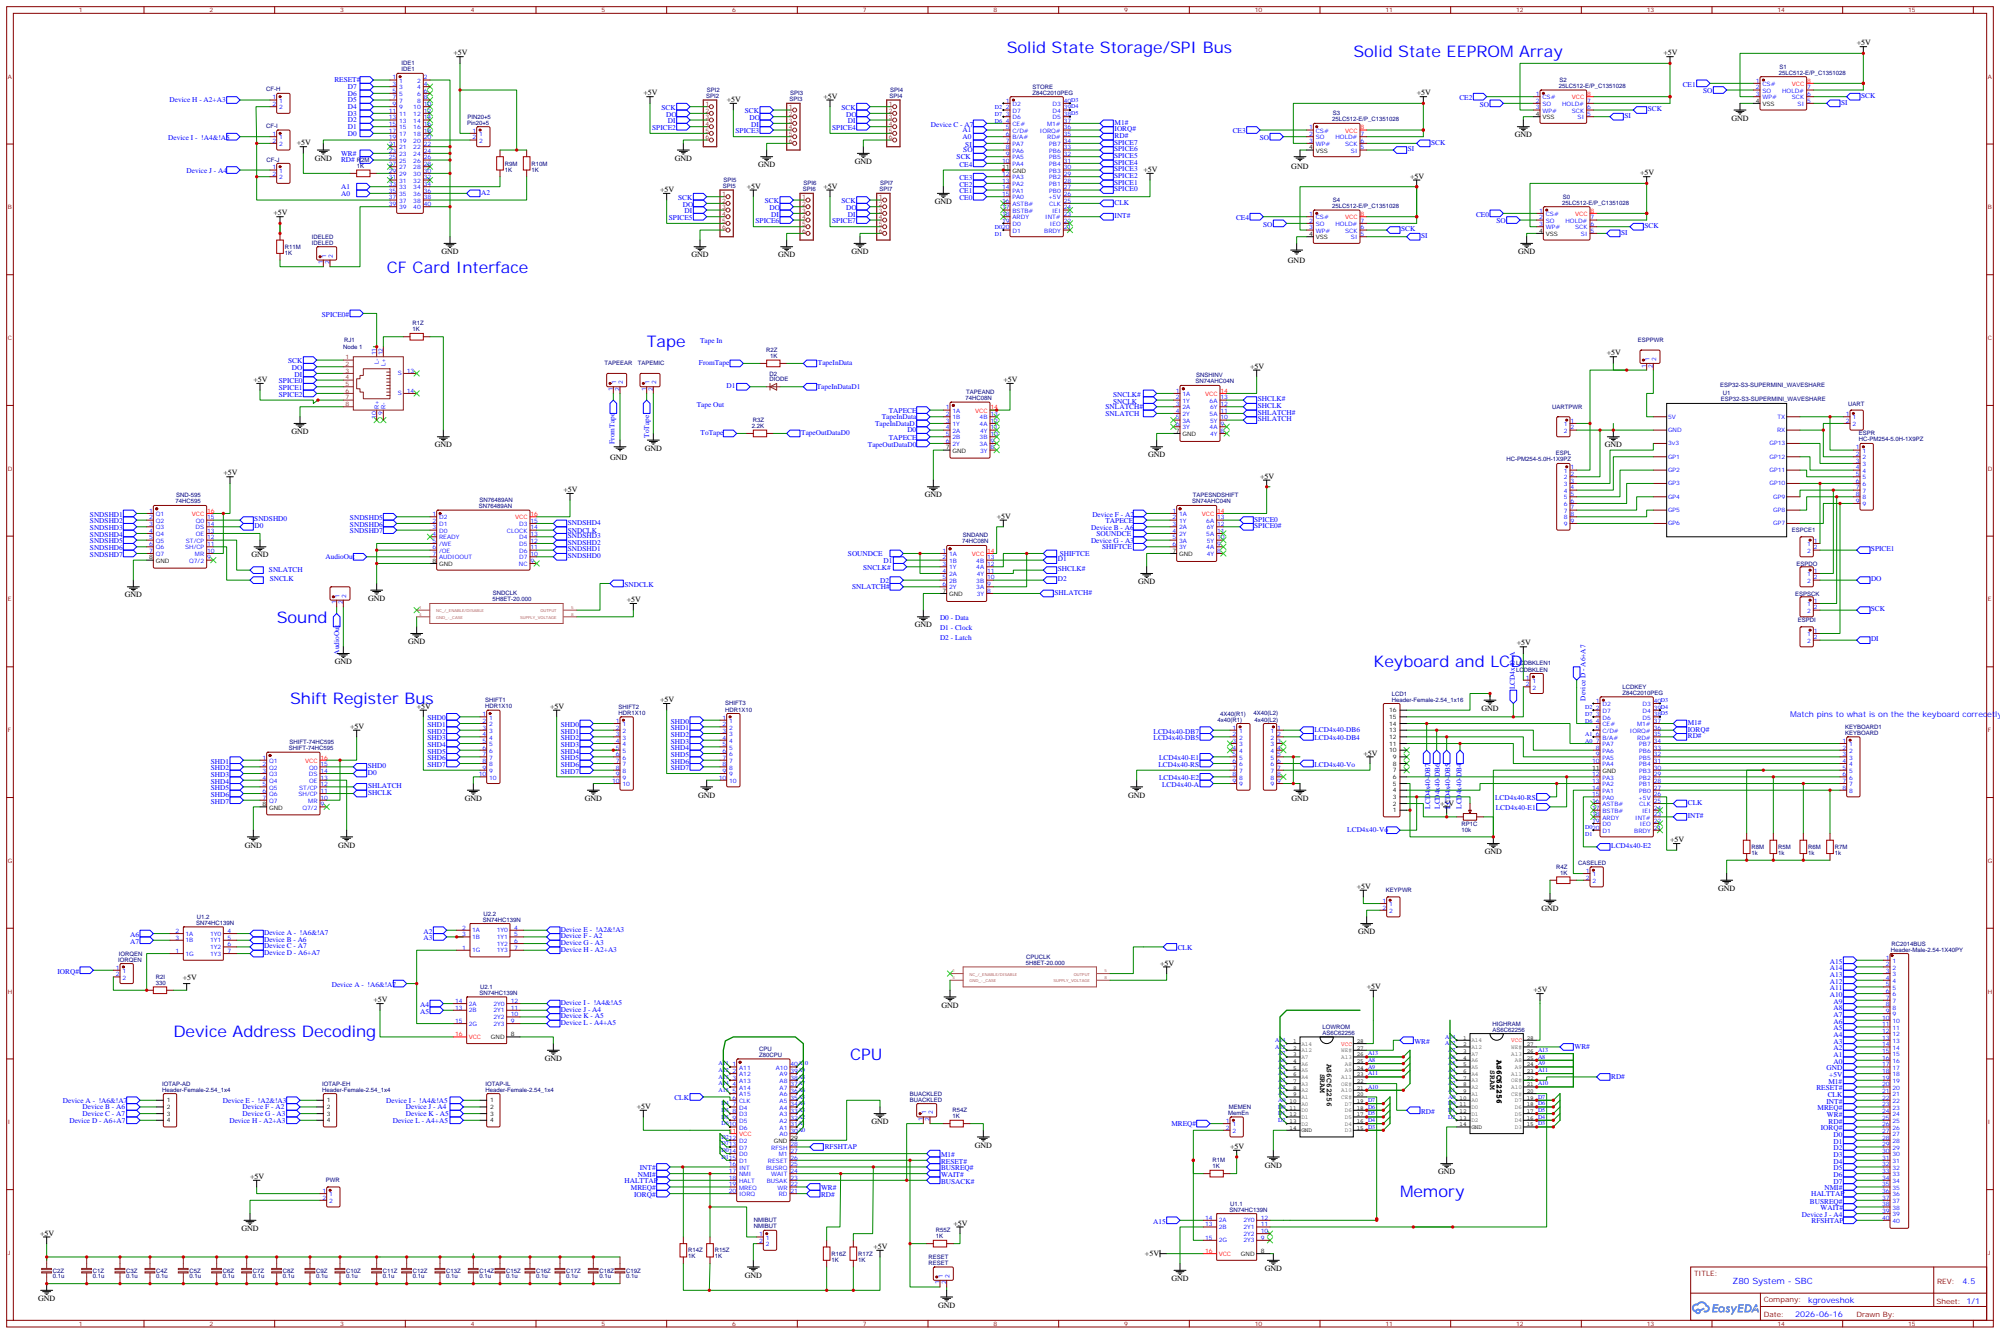
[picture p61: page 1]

SND-595
MR 10 SH/CP 11 ST/CP 12 OE 13 DS 14 Q0 15 VCC 16

Match pins to what is on the the keyboard correcetly

SHIFT-74HC595

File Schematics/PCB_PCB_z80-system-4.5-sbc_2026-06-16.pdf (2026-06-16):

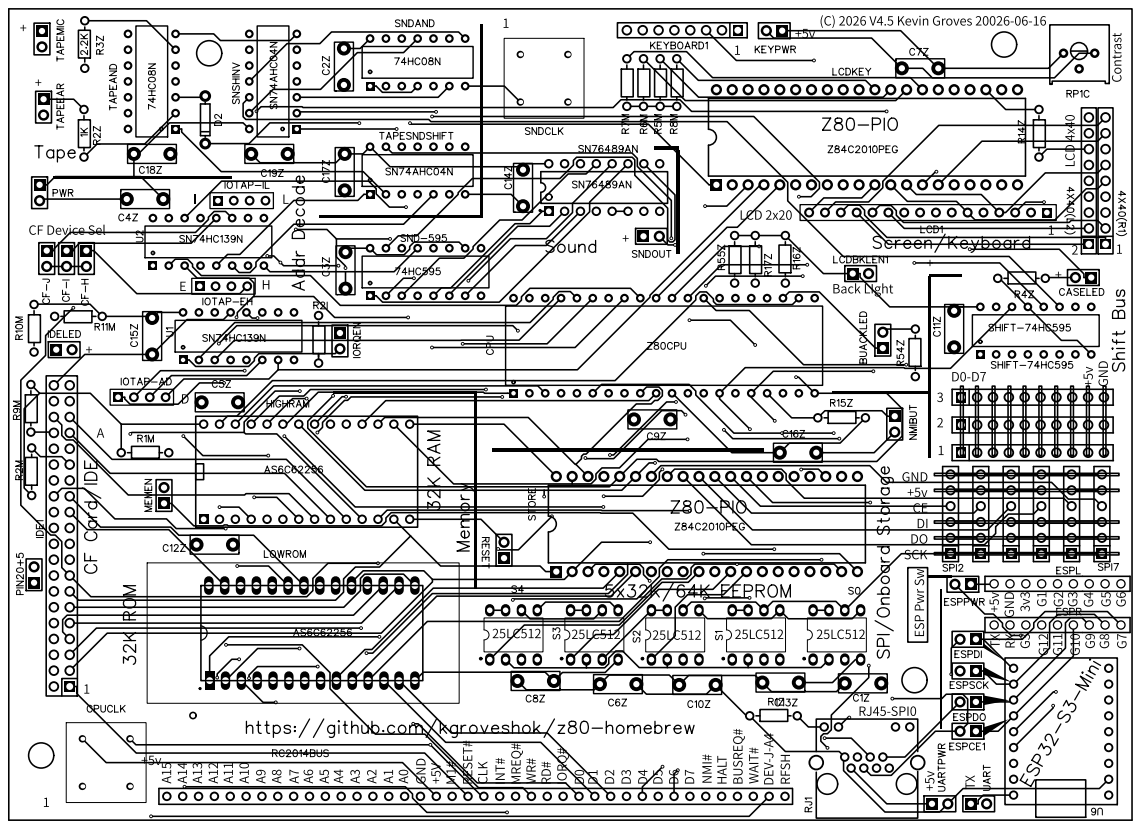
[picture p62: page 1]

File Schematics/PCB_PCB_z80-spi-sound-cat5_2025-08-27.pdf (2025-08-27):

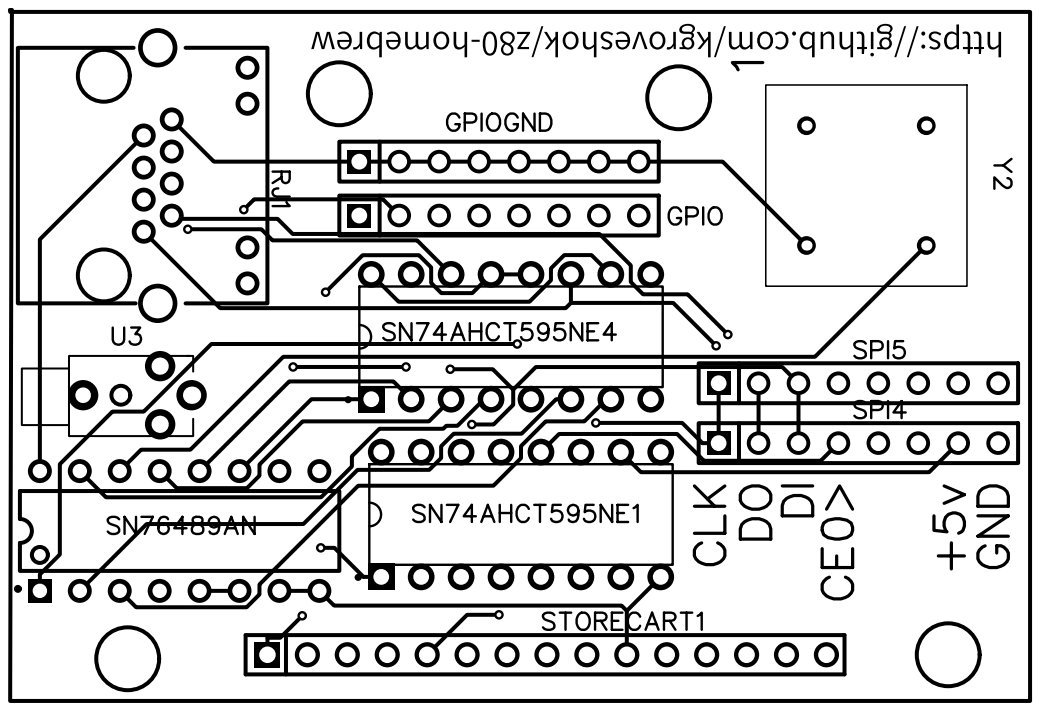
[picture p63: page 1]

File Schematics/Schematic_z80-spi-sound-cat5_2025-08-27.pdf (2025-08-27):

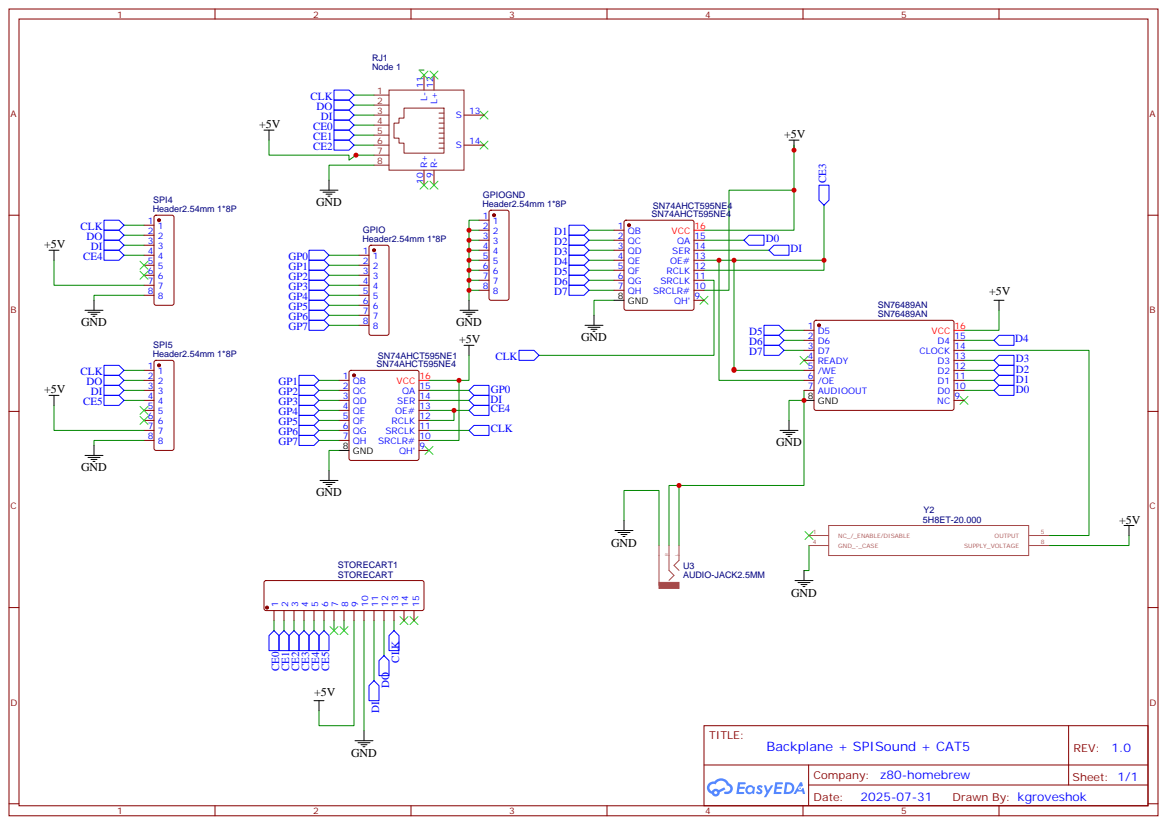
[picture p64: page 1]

SN74AHCT595NE4
SRCLR# 10 SRCLK 11 RCLK 12 OE# 13 SER 14 QA 15 VCC 16

SN74AHCT595NE1

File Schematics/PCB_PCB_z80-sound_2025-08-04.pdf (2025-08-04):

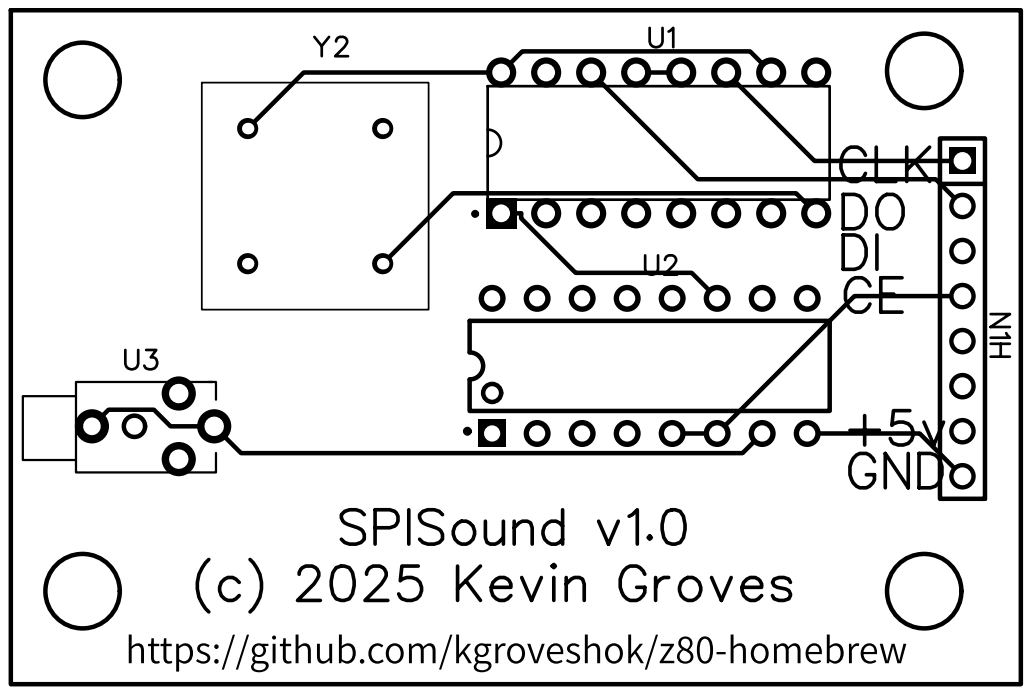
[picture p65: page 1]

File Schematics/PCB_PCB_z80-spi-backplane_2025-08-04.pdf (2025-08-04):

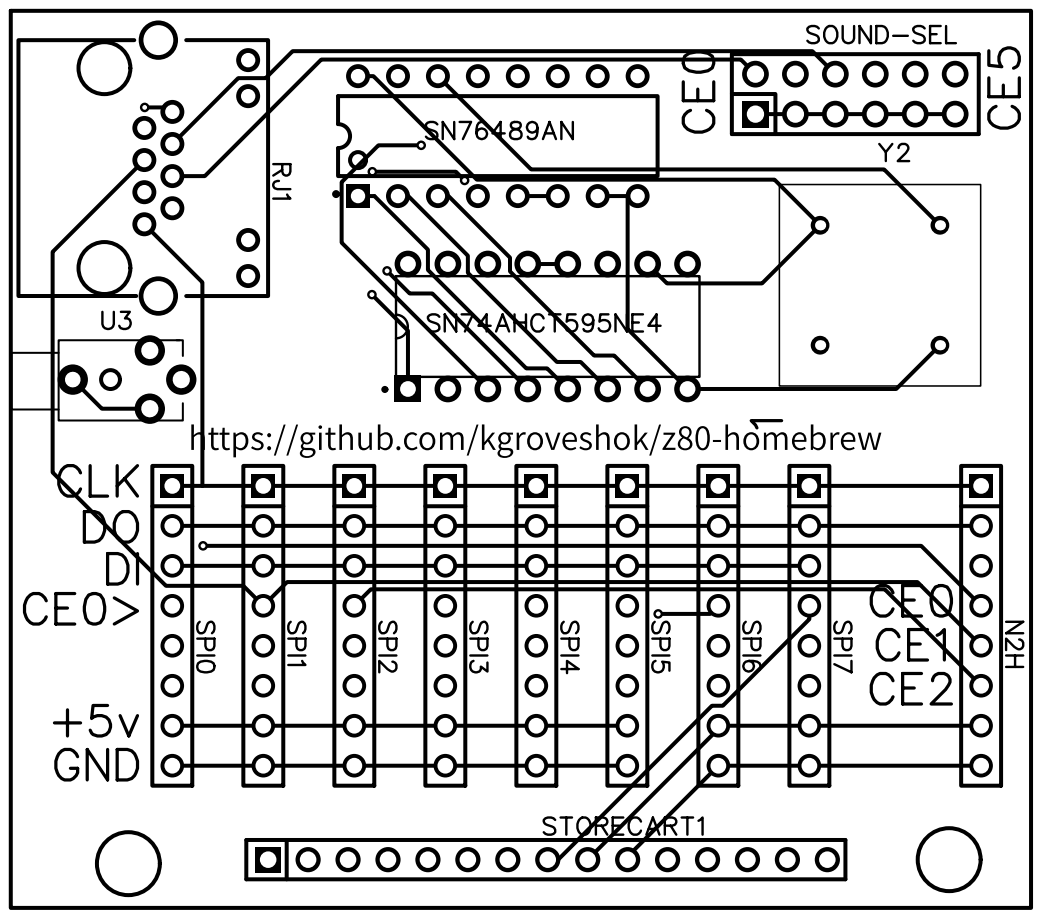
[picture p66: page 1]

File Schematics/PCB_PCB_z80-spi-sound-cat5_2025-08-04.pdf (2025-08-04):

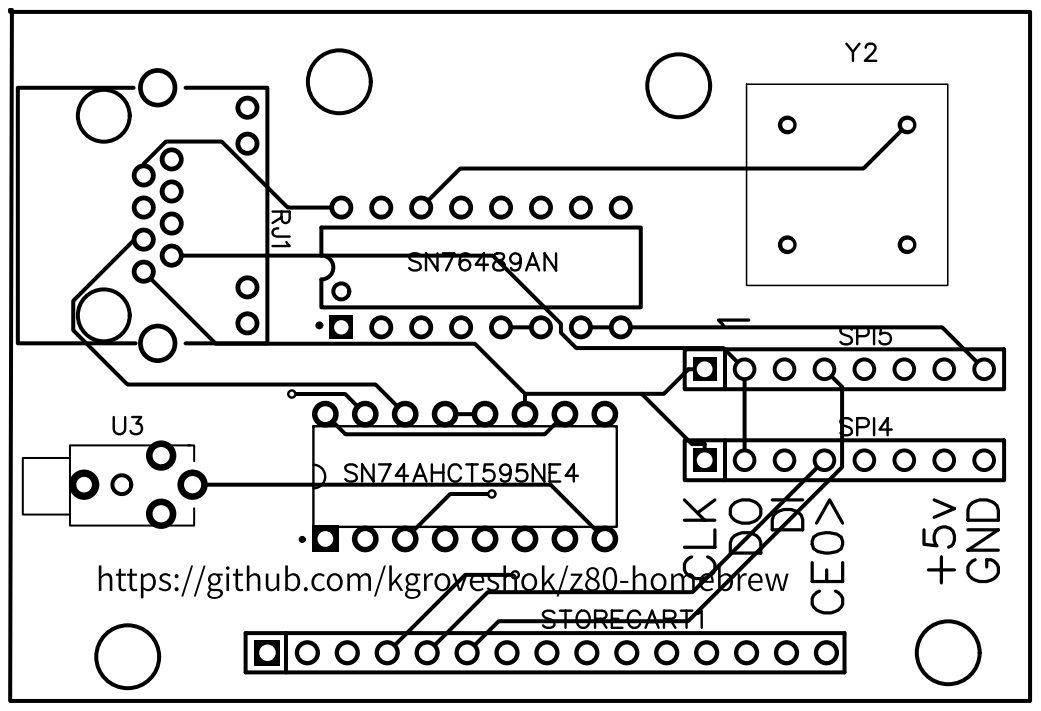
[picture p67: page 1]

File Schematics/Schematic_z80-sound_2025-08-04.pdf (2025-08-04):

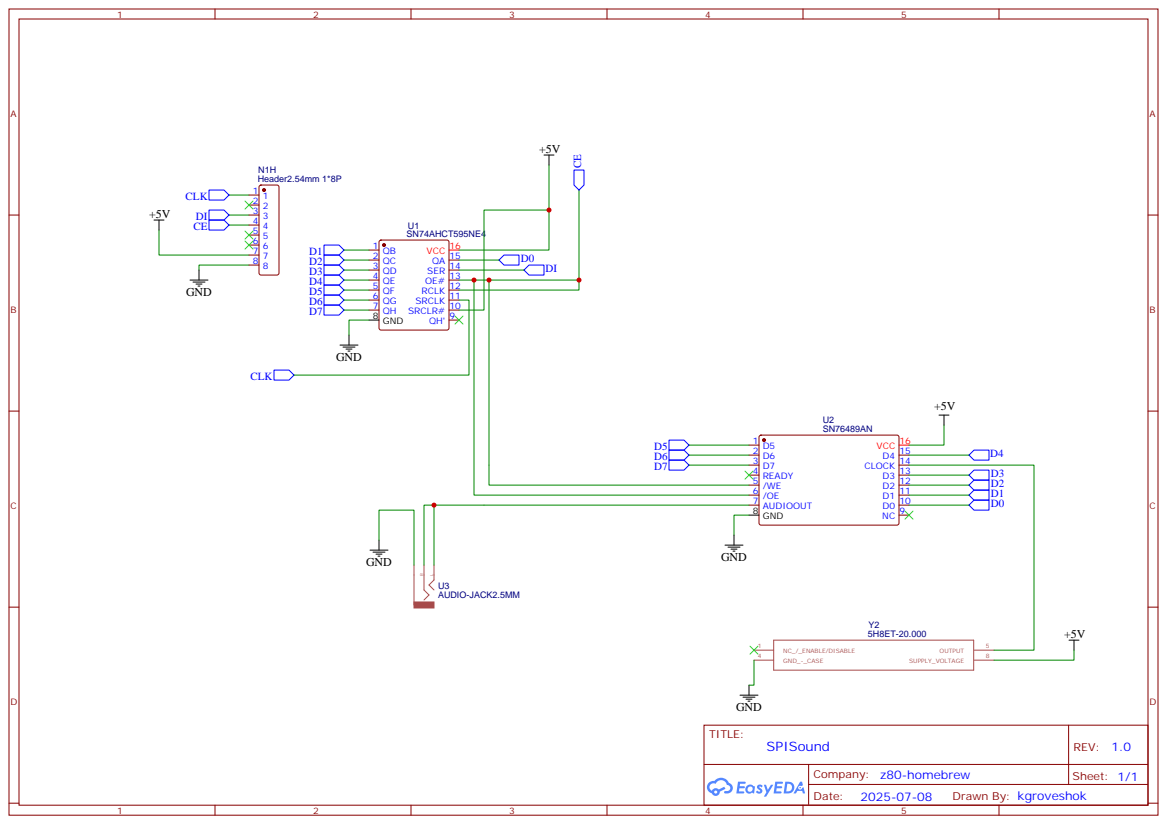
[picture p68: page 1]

SN74AHCT595NE4
SRCLR# 10 SRCLK 11 RCLK 12 OE# 13 SER 14 QA 15 VCC 16

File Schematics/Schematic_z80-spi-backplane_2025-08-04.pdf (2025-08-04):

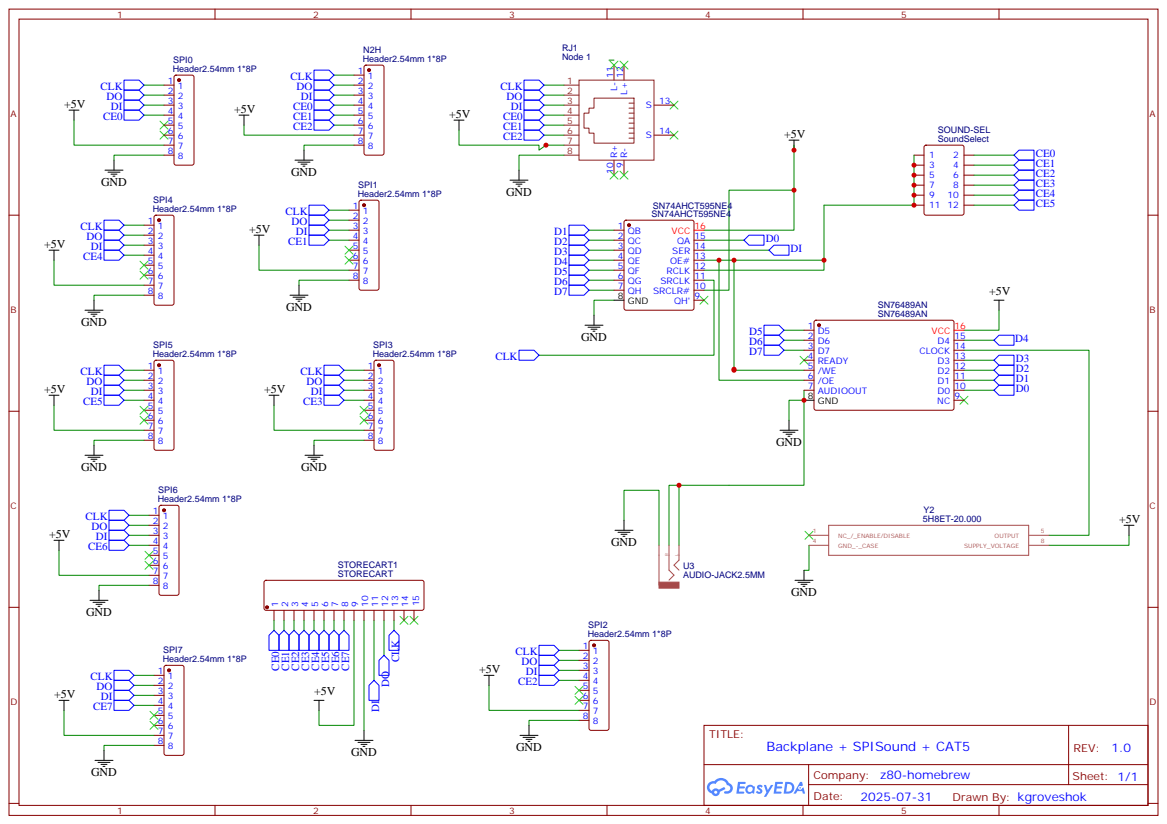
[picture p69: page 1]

SN74AHCT595NE4
SRCLR# 10 SRCLK 11 RCLK 12 OE# 13 SER 14 QA 15 VCC 16

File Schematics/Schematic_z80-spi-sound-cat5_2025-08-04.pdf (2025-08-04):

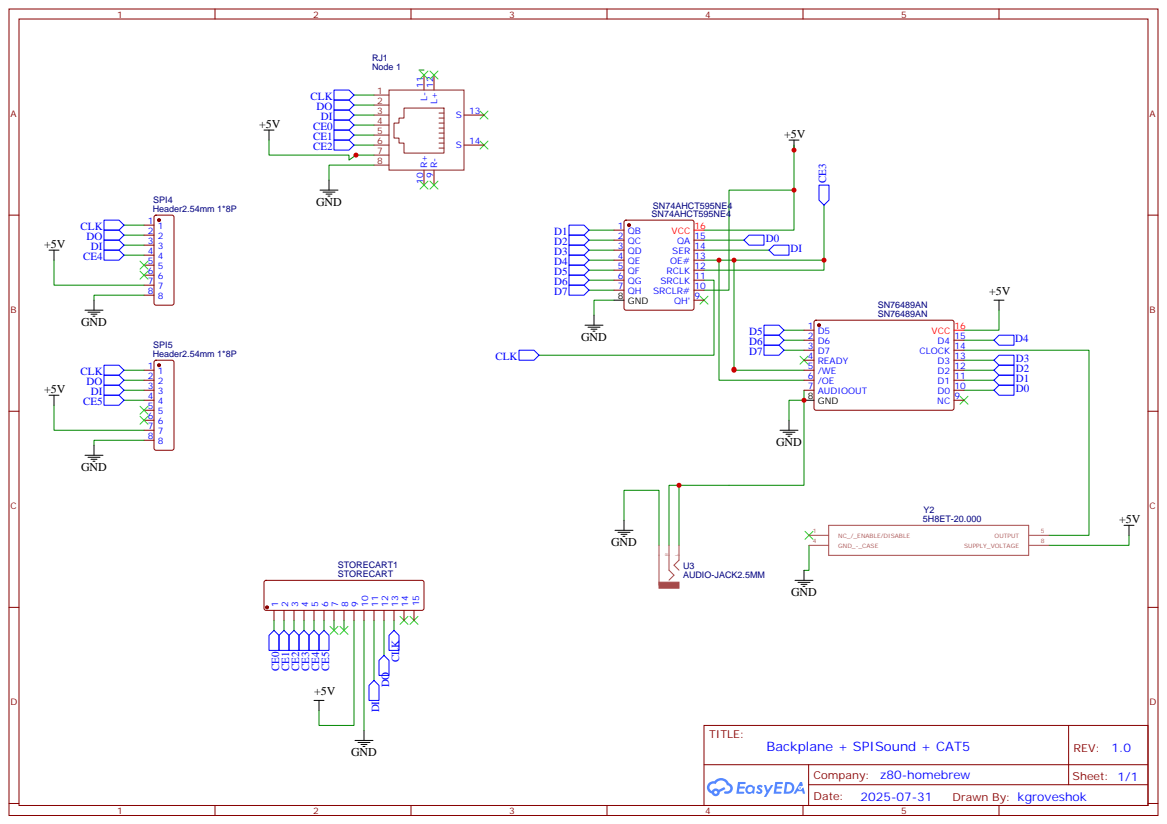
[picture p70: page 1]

SN74AHCT595NE4
SRCLR# 10 SRCLK 11 RCLK 12 OE# 13 SER 14 QA 15 VCC 16

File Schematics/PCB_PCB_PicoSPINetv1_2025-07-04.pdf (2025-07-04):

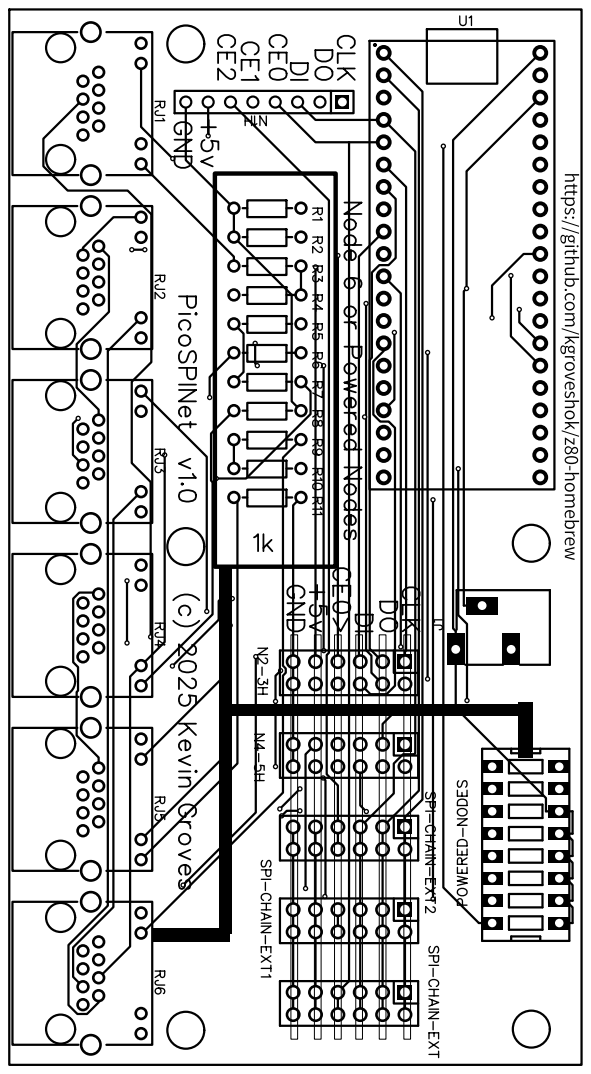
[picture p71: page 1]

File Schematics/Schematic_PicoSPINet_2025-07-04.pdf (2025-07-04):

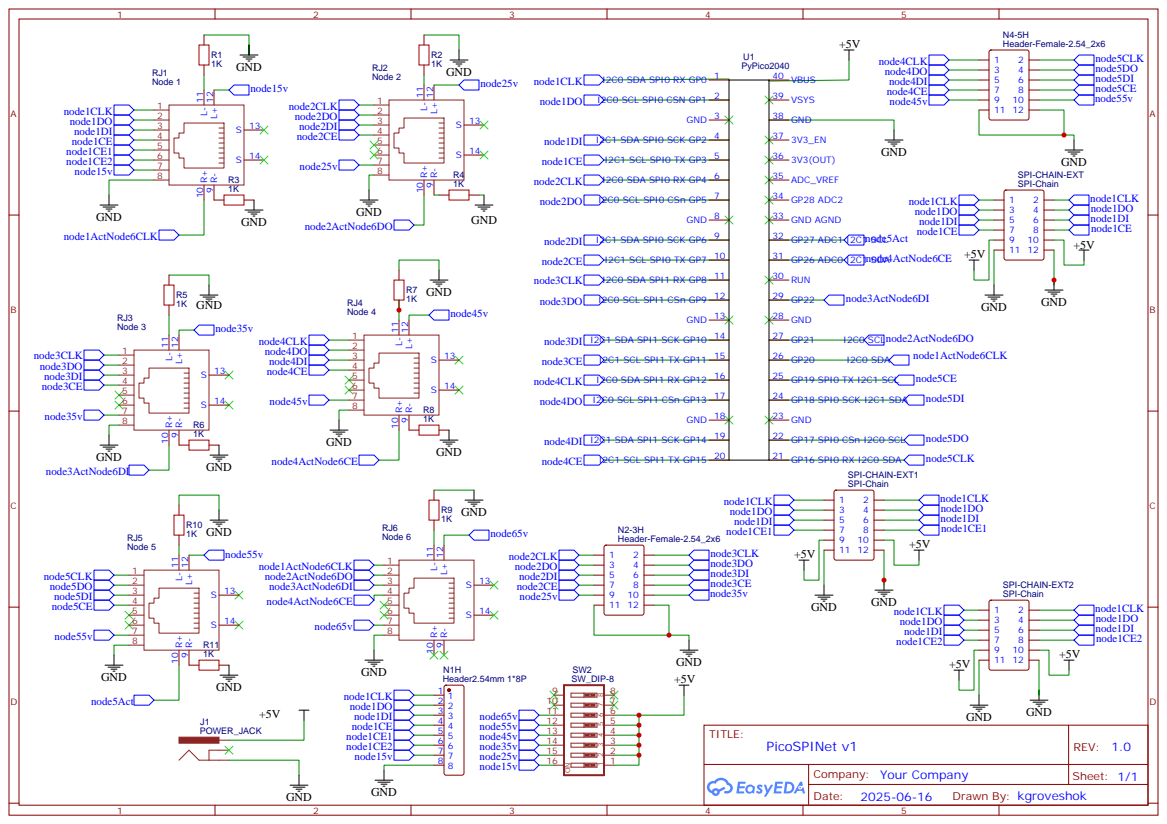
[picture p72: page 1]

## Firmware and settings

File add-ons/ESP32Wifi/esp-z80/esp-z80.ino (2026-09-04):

#include <Arduino.h>
#include <WiFi.h>
#include <NetworkClient.h>
#include <WebServer.h>
#include <ESPmDNS.h>
#include "FS.h"
#include "SPIFFS.h"
//#include <threadSafeFS.h>         // Include thread-safe wrapper since SPIFFS, LittleFS, FFat and SD file systems are not thread safe
//using File = threadSafeFS::File;
//#include <threadSafeFS.h>         // Include thread-safe wrapper since SPIFFS, LittleFS, FFat and SD file systems are not thread safe
//using File = threadSafeFS::File;  // Use thread-safe wrapper for all file operations from now on in your code
//#include <ntpClient.h>            // Setting the time is not really necessary, only if you want to see the correct file creation times
//#define HOSTNAME "Esp32Server"    // Choose your server's name - this is how FTP server would introduce itself to the clients
//#include <ftpServer.h>
//#include <WiFiS3.h>
//#include <XModem.h>
#include "esp-z80-file.h"
#include "esp-z80-common.h"
#include "esp-z80-op.h"
#include "esp-spi-op.h"

#include "esp-op-exec.h"
#include "esp-op-array.h"
//#include <ESP32FtpServer.h>  // Usando < > para bibliotecas instaladas
//#include <ftpServer.h>
//#define HOSTNAME "espz80"

//threadSafeFS::FS TSFS (LittleFS);

//XModem xmodem;

//#include <XModem.h>
//XModem xmodem;
//The arduino toolchain will add these declarations automatically but doing
//manually so things also just work if someone uses a different/custom toolchain
//bool process_block(void *blk_id, size_t idSize, byte *data, size_t dataSize);

/*
 * You can test this over your USB port using lrzsz: `stty -F /dev/ttyUSB0 4800 && sx -vaX /path/to/send/file > /dev/ttyUSB0 < /dev/ttyUSB0`
 * If you want to try CRC_XMODEM then add a o flag to the sx command (-vaoX)
 */
//void setup() {
//  Serial.begin(4800, SERIAL_8N1);
//  xmodem.begin(Serial, XModem::ProtocolType::XMODEM);
//  xmodem.setRecieveBlockHandler(process_block);
//}

//void loop() {
//This simple example continuously tries to read data
//  xmodem.receive();
//}

//bool process_block(void *blk_id, size_t idSize, byte *data, size_t dataSize) {
//byte id = *((byte *) blk_id);
//for(int i = 0; i < dataSize; ++i) {
////do stuff with the recieved data
//  }
//
//  //return false to stop the transfer early
//  return true;
//}


/*
 * You can test this over your USB port using lrzsz: `stty -F /dev/ttyUSB0 4800 && rx -vaX /path/to/save/file > /dev/ttyUSB0 < /dev/ttyUSB0`
 * If you want to try CRC_XMODEM then add a c flag to the rx command (-vacX)
 */
//void setup() {
//  Serial.begin(4800, SERIAL_8N1);
//  xmodem.begin(Serial, XModem::ProtocolType::XMODEM);
//}

//static const char text[] = "Lorem ipsum dolor sit amet, consectetur adipiscing elit. Sed sollicitudin tempor ex et sagittis. Sed feugiat justo ac dui posuere, in porta odio aliquet. Vestibulum dignissim malesuada lacus eu consectetur. Fusce sed varius nibh. Nulla lacinia ipsum non porttitor auctor. Aenean eget eros pharetra, fringilla ipsum eget, pharetra turpis. Suspendisse vitae leo id orci consectetur faucibus. Praesent elementum ex eget venenatis consequat.\n"
//"\n"
//
//void loop() {
//  //This simple example continuously tries to send data
//  xmodem.send(text, strlen(text));
//}

/*
 * You can test this over your USB port using lrzsz: `stty -F /dev/ttyUSB0 4800 && rx -vaX /path/to/save/file > /dev/ttyUSB0 < /dev/ttyUSB0`
 * If you want to try CRC_XMODEM then add a c flag to the rx command (-vacX)
 */
//void setup() {
//  Serial.begin(4800, SERIAL_8N1);
//  xmodem.begin(Serial, XModem::ProtocolType::XMODEM);
//}
//
//static const char text[] = "Lorem ipsum dolor sit amet, consectetur adipiscing elit. Sed sollicitudin tempor ex et sagittis. Sed feugiat justo ac dui posuere, in porta odio aliquet. Vestibulum dignissim malesuada lacus eu consectetur. Fusce sed varius nibh. Nulla lacinia ipsum non porttitor auctor. Aenean eget eros pharetra, fringilla ipsum eget, pharetra turpis. Suspendisse vitae leo id orci consectetur faucibus. Praesent elementum ex eget venenatis consequat.\n"
//"\n"
//
//void loop() {
//  //This simple example continuously tries to send data
//  xmodem.send(text, strlen(text));
//}



//char *wifi_profile="Default";






//const char *ftp_user = "admin";
//const char *ftp_pass = "1234";

//FtpServer ftp;
//ftpServer_t *ftpServer = NULL;





void loadCfg() {
  if (debug_level) { Serial.println("Loading configuration..."); }
  String r;
  r = readFile(SPIFFS, "/0wifi_ssid.txt");
  wifi_ssid = r;
  r = readFile(SPIFFS, "/0wifi_password.txt");
  wifi_password = r;

  if (wifi_ssid.length() > 0 and wifi_password.length() > 0) { wifi_ready = 1; }

  r = readFile(SPIFFS, "/debug.txt");
  Serial.println(r);
  if (r.length() == 0) {
    SaveDebug();
  }

  debug_level = r.toInt();

  r = readFile(SPIFFS, "/allow_sleep.txt");
  Serial.println(r);
  if (r.length() == 0) {
    SaveSleep();
  }

  allow_sleep = r.toInt();

  /*// TODO set server config flags
  // TODO enable disable webserver on use_webserver

  r = readFile(SPIFFS, "/cur_storage.txt");
  if (r.length() == 0) {
    SaveCurStorage();
  }

  storage_page = r.toInt();

  r = readFile(SPIFFS, "/cur_wprofile.txt");
  if (r.length() == 0) {
    SaveCurWProfile();
  }

  int wifi_profile = r.toInt();

  r = readFile(SPIFFS, "/cur_iprofile.txt");
  if (r.length() == 0) {
    SaveCurIProfile();
  }

  int internet_profile = r.toInt();

  r = readFile(SPIFFS, "/cur_pool.txt");
  if (r.length() == 0) {
    SaveCurPool();
  }

  int pool_page = r.toInt();
  */
}
void SaveCfg() {
  if (debug_level) { Serial.println("Saving config.txt..."); }
  writeFile(SPIFFS, "/config.txt", String(debug_level));
}
/*
void SaveCurStorage() {
  if (debug_level) { Serial.println("Saving cur_storage.txt..."); }
  writeFile(SPIFFS, "/cur_storage.txt", String(storage_page));
}

void SaveCurWProfile() {
  if (debug_level) { Serial.println("Saving cur_wprofile..."); }
  writeFile(SPIFFS, "/cur_wprofile.txt", String(wifi_profile));
}

void SaveCurIProfile() {
  if (debug_level) { Serial.println("Saving cur_iprofile,txt..."); }
  writeFile(SPIFFS, "/cur_iprofile.txt", String(internet_profile));
}

void SaveCurPool() {
  if (debug_level) { Serial.println("Saving cur_pool.txt..."); }
  writeFile(SPIFFS, "/cur_pool.txt", String(pool_page));
}
*/

// Webserver support
#ifdef RUN_WEBSERVER

// Username and password for web page access
const char *http_username = "admin";
const char *http_password = "admin";

// Function to authenticate user
bool isAuthenticated() {
  if (!server.authenticate(http_username, http_password)) {
    server.requestAuthentication();
    return false;
  }
  return true;
}
//void handleRoot(WiFiClient& client, const String& method, const String& request ) {
//
//}, const QueryParams& params, const String& jsonData) {
//https://blog.hirnschall.net/esp32-webserver/
//https://avantmaker.com/references/esp32-arduino-core-index/esp32-webserver-library/esp32-webserver-library-onfileupload/

File fsUploadFile;

void handleFileUpload() {
  Serial.println("In handle file upload");
  HTTPUpload &upload = server.upload();
  if (upload.status == UPLOAD_FILE_START) {
    String filename = upload.filename;
    if (!filename.startsWith("/")) {
      filename = "/" + filename;
    }
    Serial.println("Upload Started: " + filename);
    fsUploadFile = SPIFFS.open(filename, FILE_WRITE);
    if (!fsUploadFile) {
      Serial.println("Failed to open file for writing");
      return;
    }
  } else if (upload.status == UPLOAD_FILE_WRITE) {
    if (fsUploadFile) {
      fsUploadFile.write(upload.buf, upload.currentSize);
      Serial.printf("Uploaded %d bytes\n", upload.currentSize);
    }
  } else if (upload.status == UPLOAD_FILE_END) {
    if (fsUploadFile) {
      fsUploadFile.close();
      Serial.println("Upload Finished: " + String(upload.totalSize) + " bytes");
    }
  }
}



void handleRoot() {
  if (!isAuthenticated()) return;
  digitalWrite(led, 1);
  String html;
  html = "<html><body><form action='/upload'  enctype='multipart/form-data'  method=post>";
  html += "<input type='file' name='upload' id='fileInput' onchange='checkFileSelected()'>";
  html += "<input type='submit' value='Upload' id='uploadButton'>";
  html += "</form> <a href='/stop'>[Stop]</a>";

  if (server.hasArg("upload")) {
    html = html + "<br><b>Upload file " + server.arg("upload") + "</b>";
  }


  if (server.hasArg("del")) {
    html = html + "<br><b>Deleted file " + server.arg("del") + "</b>";
    deleteFile(SPIFFS, "/" + server.arg("del"));
  }

  if (server.hasArg("file")) {
    server.send(200, "text/plain", readFile(SPIFFS, "/" + server.arg("file")));
  }

  else {
    server.send(200, "text/html", html + listDir(SPIFFS, "/", 0) + "</body></html>");
  }
  digitalWrite(led, 0);
}

void handleGetFile() {
  if (!isAuthenticated()) return;
  digitalWrite(led, 1);
  server.send(200, "text/plain", readFile(SPIFFS, "/1pool.txt"));
  digitalWrite(led, 0);
}

void handleNotFound() {
  digitalWrite(led, 1);
  String message = "File Not Found\n\n";
  message += "URI: ";
  message += server.uri();
  message += "\nMethod: ";
  message += (server.method() == HTTP_GET) ? "GET" : "POST";
  message += "\nArguments: ";
  message += server.args();
  message += "\n";
  for (int i = 0; i < server.args(); i++) {
    message += " " + server.argName(i) + ": " + server.arg(i) + "\n";
  }
  server.send(404, "text/plain", message);
  digitalWrite(led, 0);
}
#endif




void cmdExec(byte *opcodes) {
  current_cmd = opcodes;  // pointer to cmd op being processed
  current_var = 0;        // current var that any get will insert into

  if (debug_level) { Serial.println("Exec op codes..."); }

  while (*current_cmd != OP_END_PROC) {
    if (debug_level) { dump_op_vars(); }
    if (debug_level) { Serial.printf("\nExec op code: %d", *current_cmd); }


    switch (*current_cmd) {

      case OP_VAR_POS_INC:
        current_var++;
        break;
      case OP_VAR_POS_DEC:
        current_var--;
        break;
      case OP_SET_VAR_POS:
        // set the position of the current var op array
        current_var = *(++current_cmd);
        current_cmd++;
        break;
      case OP_MAKEWORD:

        execOpMakeWord();
        break;

      case OP_INBYTE:

        execOpInByte();
        break;
      case OP_OUTBYTE:

        execOpOutByte();
        break;
      case OP_BREAKWORD:

        execOpBreakWord();
        break;
      case OP_LOOP_START:

        execOpLoopStart();
        break;
      case OP_UNTIL_BYTE:

        execOpUntilByte();
        break;
      case OP_UNTIL_COUNT:

        execOpUntilCount();
        break;
      case OP_OPENF:

        execOpOpenF();
        break;
      case OP_CLOSEF:

        execOpCloseF();
        break;
      case OP_STR_CLR:

        execOpClrStr();
        break;
      case OP_STR_ADD:

        execOpAddToStr();
        break;
      case OP_STORE_VAR:

        execOpStarVar();
        break;
      case OP_VAR_LIT:
        execOpVarLit();
        break;
      case OP_EXEC_FUNC:
        if (debug_level) { Serial.println("op exec func"); }
        current_cmd++;
        int func = *current_cmd;
        int ret = (*exec_func[func])();
        break;
    }


    current_cmd++;
  }

  if (debug_level) { Serial.printf("\nExec done"); }
}


void setup(void) {
  pinMode(led, OUTPUT);
  digitalWrite(led, 0);
  Serial.begin(115200);

  // configure interface to z80 spi
  pinMode(spi_ce_pin, INPUT);
  pinMode(spi_do_pin, INPUT);
  pinMode(spi_sck_pin, INPUT);

  // Only set to output once we have CE so as not to corrupt the singal
  pinMode(spi_di_pin, INPUT);
  //pinMode(spi_di_pin, OUTPUT);

  esp_sleep_enable_ext0_wakeup(esp_wake_up_ce, 0);

  if (!SPIFFS.begin(FORMAT_SPIFFS_IF_FAILED)) {
    Serial.println("SPIFFS Mount Failed");
    return;
  }

  // Load persistent config
  listDir(SPIFFS, "/", 0);
  loadCfg();

  //  listDir(SPIFFS, "/", 0);
  //  writeFile(SPIFFS, "/hello.txt", "Hello ");
  //  appendFile(SPIFFS, "/hello.txt", "World!\r\n");
  //  readFile(SPIFFS, "/hello.txt");
  //  renameFile(SPIFFS, "/hello.txt", "/foo.txt");
  //  readFile(SPIFFS, "/foo.txt");
  //  deleteFile(SPIFFS, "/foo.txt");
  //  testFileIO(SPIFFS, "/test.txt");
  //  deleteFile(SPIFFS, "/test.txt");


  set_exec_funcs();


  setCpuFrequencyMhz(80);

  // TODO remove this once configured

  if (wifi_ready) {
    WiFi.mode(WIFI_STA);
    WiFi.begin(wifi_ssid, wifi_password);
    Serial.println("");

    // Wait for connection

    for (int retries = 0; WiFi.status() != WL_CONNECTED & retries < 10; retries++) {
      delay(500);
      Serial.print(".");
    }

    if (WiFi.status() != WL_CONNECTED) {
      Serial.println("Failed to connect to wifi. Disabled.");
      deleteFile(SPIFFS, "/0wifi_password.txt");
      wifi_ready = 0;
    } else {
      Serial.println("");
      Serial.print("Connected to ");
      Serial.println(wifi_ssid);
      Serial.print("IP address: ");
      Serial.println(WiFi.localIP());

      if (MDNS.begin("esp32")) {
        Serial.println("MDNS responder started");
      }
    }


    //if (debug_level & 128) {
    //      Serial.println("FTP Server init");
    //ftp.begin(ftp_user, ftp_pass);
    //ftpServer = new (std::nothrow) ftpServer_t ();
    //setCpuFrequencyMhz(30);

#ifdef RUN_WEBSERVER
    server.on("/", handleRoot);
    //server.on("/upload", HTTP_POST, handleUploadReply, handleUpload);
    server.on(
      "/upload", HTTP_POST, []() {
        server.send(200, "text/plain", "File Uploaded Successfully");
      },
      handleFileUpload);
    server.on("/stop", []() {
      runWebServer = 0;
    });
    //server.onFileUpload(handleFileUpload);

    //server.on("/get", handleGetFile);
    //server.addRoute("/", handleRoot);
    //server.addHandler()
    //server.on("/inline", []() {
    //  server.send(200, "text/plain", "this works as well");
    //});
    //https://avantmaker.com/references/esp32-arduino-core-index/esp32-webserver-library/esp32-webserver-library-upload/

    server.onNotFound(handleNotFound);
    //server.onFileUpload(handleUpload);
    //if (use_webserver) {
    server.begin();
    Serial.println("HTTP server started");


    //}
    //} else {
//        Serial.println("HTTP server configured to not run. Skipped start up.");
//}
#endif
  } else {
    Serial.println("Wifi not configured. Skipping HTTP server startup");
  }
  uint32_t Freq = getCpuFrequencyMhz();
  Serial.print("CPU Freq = ");
  Serial.print(Freq);
  Serial.println("");

  Serial.println("Waiting for CE2 line...");
}

void loop(void) {

  int sleep_ret;

  debug_level=2;

  //#ifdef RUN_WEBSERVER
  //
  //  if (wifi_ready) {
  //if (use_webserver) {
  //      server.handleClient();
  //} else {
  //}
  //}

  //#endif
  if (isCE2()) {
    //if (debug_level & 128) {
    // If web server is enabled and ce2 is high then switch to running webserver tasks
    // and not go to sleep
    //        if (debug_level) { Serial.println("Handle WWW"); }
    //while (isCE2()) { server.handleClient(); }
    //        setCpuFrequencyMhz(240);
    //ftp.handleFTP();

    //delay(500);
    //} else {
    
    if( allow_sleep ) {
      if (debug_level) { Serial.println("\nNo activity, entering sleep"); }
    sleep_ret = esp_light_sleep_start();
    if (debug_level) { Serial.printf("\nReturn from sleep: %d", sleep_ret); }
    } else { 
if (debug_level) { Serial.printf("z"); }
delay(250);
    }
    
    //  }
  }

  //delay(2);  //allow the cpu to switch to other tasks


  if (!isCE2()) {
    // Get a command byte
    pinMode(spi_di_pin, OUTPUT);


    if (debug_level) { Serial.printf("\nReady for command byte..."); }
    cmd = rcvspibyte();
    if (debug_level) { Serial.printf("\nCommand byte seen: %d", cmd); }


    // Command processing
    digitalWrite(led, 1);

    // scan the first byte of command array for a hit

    if (debug_level) { Serial.println("Scanning"); }
    for (int a = 0; op_commands[a] != 0; a++) {
      if (debug_level > 5) { Serial.printf("\np_cmd: %d", op_commands[a]->p_cmd); }

      if (op_commands[a]->p_cmd == cmd) {
        if (debug_level) { Serial.println("First level command found on "); }
        if (debug_level) { Serial.println(a); }
        // Check for second level need
        if (op_commands[a]->s_cmd > 0) {
          if (debug_level) { Serial.println("Need a sub command..."); }

          // TODO get another byte
          cmd2 = rcvspibyte();
          // TODO rescan
          for (int aa = 0; op_commands[aa] != 0; aa++) {
            if (op_commands[aa]->p_cmd == cmd & op_commands[aa]->s_cmd == cmd2) {
              if (debug_level) { Serial.println("Exec:" + String(op_commands[aa]->des)); }
              cmdExec(op_commands[aa]->op_codes);
              break;
            }
          }
          break;
        } else {
          if (debug_level) { Serial.println("Don't need sub command passing off to processing"); }
          if (debug_level) { Serial.println("Exec:" + String(op_commands[a]->des)); }
          cmdExec(op_commands[a]->op_codes);
          // TODO process
          break;
        }
        if (debug_level) { Serial.println("Done"); }
      }
    }


    digitalWrite(led, 0);
    pinMode(spi_di_pin, INPUT);
  } else {
  }
}

// eof

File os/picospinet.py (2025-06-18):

# PicoNET - SPI networking hub
# (c) 2025 Kevin Groves



# use: "hello" ptr count clostro

# : clkstro $00 do dup i + @ spio loop ;


# clock in a string to SCRATCHPAD

# : clkstri scratchpad $01 - repeat $01 + dup dup spii ! @ $00 = until ; 

# use: "hello" $00 send
# : send spicel $01 spio spio ptr count clkstro spiceh ;
# : listen spicel $02 spio spii $00 clkstri spiceh ;
# : storestr spicel $03 spio spio ptr count clkstro spiceh ;
# : getstr spicel $04 spio clkstri spiceh ;

# use: "pass" "ssid" wifi
# : wifi $0b spio ptr count clkstro ptr drop ptr count clkstro ; 

buffers={}


# Network protocol
#
# cmd dest len <packet>

CMD_PUTCHR=0x10
# Send char to node 1-4 - node ff is ext node 0 is all (todo)
#
#
# To externl, storage to strings. Commands delimited by ',' (comma)
#
# GET <url>    - GET on the url and places ascii version in new next buffer
# PST <url>    - POST on the url and places ascii version in new next buffer
# SND <ip> <port>  - sends the contents of the string at storage address to ip
# REC <ip> <port>  - gets the contents of the string on ip and saves to storage address
# GO                  - Instruct hub to do remote actions


CMD_GETCHR=0x11
# Listen for message to receive
# 02  ->
#   <-  <source node id> or 00 if no data waiting
#       if >0 then clock in <zero term packet>

CMD_PUTSSTRZ=0x12
# Store string
# 03 <0-255> <zero term packet>
#
#   stores the zero term packet as a file on local storage with store_<node id>_<address>.txt

CMD_GETSSTRZ=0x13
# Get stored string
# 04 <0-255> <zero term packet>
#
# gets the zero term packet as a file on local storage with store_<node id>_<address>.txt

CMD_CLRALL=0x15
# clear receive buffer for this node
#



# will add the zero term packet to the receive buffer of the node
# if the node is ff then it is taken as a server command
# adds the zero term packet as a file on local storage with rec_<dest id>_<src id>_<seq>.txt

#CMD_UNIXTS=7
# 07   get unix time stamp

CMD_GETDATE=0x16
# 08 get current date

CMD_GETTIME=0x17
## 09 get current time

#CMD_TZ=10
# 10 Set current timezone for NTP

#CMD_WIFI=11
# 11 <SSID> <PASS>  Send SSID and password to configure Wifi

#CMD_LANSTATUS=12
# 12 Request current LAN status, IP, datetime etc

#CMD_TERM=13
# 13 Send a byte stream to terminal hosted by server (more useful if a Pi with HDMI and not Pico)

#CMD_NOTE=14
# 14 <note> <duration>  Play a note via PWM on the Pico (useful as dont have the sound chip working yet)

CMD_GETNODE=0x18
# 15 Clock back the node hub and id this device is connected to

#CMD_GETMAP=16
# 16 clock back hub id and status of each node (connected or not). 

#CMD_GETCHR=17
# 17 clock back next byte in buffer


# All clocked in data from client to the server (z80) to be pushed to stack on the z80

CMD_DEBUG=0x30
# 18 dump to logs all of the node vars to console to help with debug

CMD_NETDEBUG=0x31
# x -> Debug to console level

CMD_SYNC=0x32
# x -> Number of minutes to sync settings to storage

netdebug=1

# late time storage arrays were synced to storage
lastsync=0
timetosync=1

lastservercmd=0
timetoservercmd=1

from machine import Pin
import time

# just one node for now

#DI=Pin(2,mode=Pin.IN)      #pico pin 1
#DO=Pin(1,mode=Pin.OUT)    # pico pin 2
#SCLK=Pin(0,mode=Pin.IN)   # pico pin 4
#CE=Pin(3,mode=Pin.IN)     # pico pin 5

#node_1=0
#node_1_buff="Hi!"
#node_1_cmd=""
#node_1_strings={}



# structrure to hold each node

#     Node 1          Node 2    Node 3    Node 4      Node 5       Node 6
#       GPIO  Pin  
#SLK    0     1      4   6       8   11     12  16    16    21     20  26 
#DO     1     2      5   7       9   12     13  17    17    22     21  27
#DI     2     4      6   9      10   14     14  19    18    24     22  29
#CE     3     5      7  10      11   15     15  20    19    25     26  31

# sub seq steps

#SEQ_SPICLKPULSE=1

#SEQ_SAVEPARAM1=18
#SEQ_SAVEPARAM2=19
#SEQ_SAVEPARAM3=20
#SEQ_SAVEPARAM4=21

# command op codes

SEQ_SPIBIT7=7
SEQ_SPIBIT6=6
SEQ_SPIBIT5=5
SEQ_SPIBIT4=4
SEQ_SPIBIT3=3
SEQ_SPIBIT2=2
SEQ_SPIBIT1=1
SEQ_SPIBIT0=0



#SEQ_SPIINBIT7=9
#SEQ_SPIINBIT6=8
#SEQ_SPIINBIT5=7
#SEQ_SPIINBIT4=6
#SEQ_SPIINBIT3=5
#SEQ_SPIINBIT2=4
#SEQ_SPIINBIT1=3
#SEQ_SPIINBIT0=2
#
#SEQ_SPIOUTBIT7=17
#SEQ_SPIOUTBIT6=16
#SEQ_SPIOUTBIT5=15
#SEQ_SPIOUTBIT4=14
#SEQ_SPIOUTBIT3=13
#SEQ_SPIOUTBIT2=12
#SEQ_SPIOUTBIT1=11
#SEQ_SPIOUTBIT0=10

SEQ_BYTEIN=100
SEQ_BYTEOUT=101
SEQ_ZSTRIN=102
SEQ_STROUT=103
SEQ_INIT= 104    # init for the command ie setup params
SEQ_SAVE= 105    # save any params clocked in
SEQ_DEBUG=106
SEQ_SYNC=107    # force sync of buffers to storage
SEQ_NOP=108
SEQ_END=109
SEQ_SAVEBYTE=110
SEQ_REPEAT=150
SEQ_UNTILZ=151
SEQ_SSTRZNEXT=153
 
# command sequence ops
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

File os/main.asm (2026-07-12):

; z80 homebrew opperating system
;

STARTUP_ENABLE: equ 1


; bios jump points via rst

if BASE_SC114 = 1 

	org 8000h
endif

if BASE_KEV = 1 

	org 0h
endif

if BASE_CPM = 1 

	org 100h
endif
	jp coldstart     ; rst 0 - cold boot
      
debuglevel: db   "DL",DEBUG_LEVEL, 0
        ;nop
        ;nop
        ;nop
        ;nop
        nop
; rst $8
        jp debug_vector        
        nop
        nop
        nop
        nop
        nop
; rst $10
        jp macro_forth_dsp_pop
        nop
        nop
        nop
        nop
        nop
; rst $18
        jp macro_dsp_valuehl
        nop
        nop
        nop
        nop
        nop
; rst $20
        jp forth_push_numhl
        nop
        nop
        nop
        nop
        nop
; rst $28
        jp 0
        nop
        nop
        nop
        nop
        nop
; rst $30
        jp str_at_display
        nop
        nop
        nop
        nop
        nop
; rst $38
        jp update_display




buildtime: db   "Build: "
		include "romtimestamp.asm"
	   db 0



;        nop 
;        nop
;;	org 05h		; null out bdos call
;
;        nop 
;        nop 
;        nop
;;	org 08h
;;;
;;	jp cin		; rst 8 - char in
;;;
;
;        nop
;        nop
;        nop
;        nop
;        nop
;        nop
;        nop
;        nop
;	org 010h
;;
;	jp cout		; rest 010h  - char out
;;
;	org 01bh  
;
;	;jp  		; rst 01bh   - write string to display
;	jp str_at_display
;
;
;	org 020h
;
;	; jp		 ; rst 020h - read char at screen location
;
;	org 028h

	; jp		 ; rst 028h  - storage i/o

; 	org 030h
;	jp break_point_state
 
; $30 
; org 038h
; $38

; TODO any more important entry points to add to jump table for easier coding use?

if BASE_KEV = 1 

	; need to be at $66 for nmi support
	db 0,255,0,255,0,255
	db 0,255,0,255,0,255
	db 0,255,0,255,0,255
        db 0
	jp nmi
endif

include "firmware.asm"

;; below moved from firmware.asm for strange zero calc of baseusermem label. Scope issue on multipass????
;if BASE_KEV 
;baseram: equ 08000h
;endif

;if BASE_SC114
;baseram:     equ    endofcode
;endif


; Add NMI support. A rst 066h when r15z goes neg on clock side of resist. needs to do retn when exiting

; start system

coldstart:
	; set sp
	; di/ei

	di
	ld sp, tos
	call init_nmi
;	ei

	; init spinner
	ld a,0
	ld (display_active), a

	; disable breakpoint by default

	;ld a,'*'
;	ld a,' '
;	ld (os_view_disable),a

	; set break point vector as new break point on or off
	call bp_off


	; default the parse vector to just a RET
	ld a, $c9
	ld (parse_vector), a

	; init hardware

	; init keyboard and screen hardware

	call hardware_init


	call delay1s
	ld a, display_row_3+8
	ld de, buildtime
	call str_at_display
	call update_display

	call delay1s
	call delay1s
	call delay1s

	; detect if any keys are held down to enable breakpoints at start up

	call cin 
	cp 0
	jr z, .nokeys

	;call hardware_diags
	call config

;	ld de, .bpen
;	ld a, display_row_4
;	call str_at_display
;	call update_display
;
;	ld a,0
;	ld (os_view_disable),a
;
;.bpwait:
;	call cin
;	cp 0
;	jr z, .bpwait
;	jr .nokeys
;
;
;.bpen:  db "Break points enabled!",0






.nokeys:


	

;jp  testkey

;call storage_get_block_0
;
;ld hl, 0
;ld de, store_page
;call storage_read_block

	
;ld hl, 10
;ld de, store_page
;call storage_read_block





;stop:	nop
;	jp stop



main:
	call clear_display
	call update_display



;	call testlcd



	call forth_init


warmstart:
	call forth_warmstart

	; run startup word load
        ; TODO prevent this running at warmstart after crash 

	if STARTUP_ENABLE

		if STARTUP_V1

			if STORAGE_SE
				call forth_autoload
			endif
			call forth_startup
		endif

		if STARTUP_V2

			if STORAGE_SE
				call forth_autoload
			else
				call forth_startup
			endif


		endif

	endif

warmstart_afterauto:

	; show free memory after boot
	ld de, freeram
	ld a, display_row_1
	call str_at_display

	; get current heap start after loading any uwords

	;ld de, (os_last_new_uword)
	;ex de, hl

; Or use heap_size word????
	;ld hl, heap_end
	;ld hl, heap_size
	;ld de, topusermem
	;ld de, heap_start
		ld de, (free_list )     
		ld hl, heap_end
	sbc hl, de
	;push hl
	;ld a,h	         	
	;ld hl, os_word_scratch		; TODO do direct write to frame buffer instead and drop the str_at_display
	;call hexout
   	;pop hl
;
;	ld a,l
;	ld hl, os_word_scratch+2
;	call hexout
;	ld hl, os_word_scratch+4
;	ld a, 0
;	ld (hl),a
	ex de, hl
	ld hl, os_word_scratch
	call uitoa_16


	ld de, os_word_scratch
	ld a, display_row_1 + 13
	call str_at_display
	call update_display


	;call demo


	; init scratch input area for cli commands

	ld hl, os_cli_cmd
;	ld a,0
	ld (hl),0
	inc hl
	ld (hl),0

	ld a,0
	ld (os_last_cmd),a	; current command in use to enable repeated use with an enter etc

	ld (os_cur_ptr),a	; ptr to whatever is needed for this command
	ld (os_cur_ptr+1),a	

	ld (os_word_scratch),a	; byte or word being used in parsing for this command
	ld (os_word_scratch+1),a	
	

	;ld a, kLCD_Line2        ; TODO prompt using direct screen line address. Correct this to frame buffer
	ld hl, os_cli_cmd

;	ld a, 0		 ; init cli input
	ld (hl), 0
	ld a, display_row_2        ; TODO prompt using direct screen line address. Correct this to frame buffer
cli:
	; show cli prompt
	;push af
	;ld a, 0
	;ld de, prompt
	;call str_at_display

	;call update_display
	;pop af
	;inc a
	;ld a, kLCD_Line4+1	 ; TODO using direct screen line writes. Correct this to frame buffer

.lastrecall:

	ld c, 0
	ld d, 255    ; TODO fix input_str to actually take note of max string input length
	ld e, 40

	ld hl, os_cli_cmd

	STACKFRAME OFF $fefe $9f9f

	call input_str

	STACKFRAMECHK OFF $fefe $9f9f


	; check to see if last line recall has been requested

if EDIT_V2
	cp KEY_UP
	jr nz, .noexecline

	ld de, os_cli_cmd
	ld hl, os_last_cmd
	ld bc, 255
	ldir
	ld a, 0
	jr .lastrecall
endif

.noexecline:
	; no so exec the line		

	; copy input to last command

	ld hl, os_cli_cmd
	ld de, os_last_cmd
	ld bc, 255
	ldir

	; wipe current buffer

;	ld a, 0
;	ld hl, os_cli_cmd
;	ld de, os_cli_cmd+1
;	ld bc, 254
;	ldir
	; TODO ldir is not working strcpy may not get all the terms on the input line????
;	call strcpy
;	ld a, 0
;	ld (hl), a
;	inc hl
;	ld (hl), a
;	inc hl
;	ld (hl), a

	; switch frame buffer to program 

		ld hl, display_fb1
		ld (display_fb_active), hl

;	nop
	STACKFRAME ON $fbfe $8f9f
	; first time into the parser so pass over the current scratch pad
	ld hl,os_cli_cmd
	; tokenise the entered statement(s) in HL
	call forthparse
        ; exec forth statements in top of return stack
	call forthexec
	;call forthexec_cleanup
;	call parsenext

	STACKFRAMECHK ON $fbfe $8f9f
	; TODO on return from forth parsing should there be a prompt to return to system? but already in system.

	ld a, display_row_4
	ld de, endprog

	call update_display		

	call next_page_prompt

	; switch frame buffer to cli

		ld hl, display_fb0
		ld (display_fb_active), hl


        call clear_display
	call update_display		

	ld hl, os_cli_cmd
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

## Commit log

2022-05-03 Updated schematic for the main board fix
2022-05-10 Boards built
2024-01-28 Stage 3 checks
2024-02-06 Stage 3.0 working CPU, RAM and ROM
2024-02-19 alternating pin output
2024-02-20 base of firmware from previous stage
2024-02-23 sort of working but soem screen corruption and strings on wrong lines
    [firmware.asm, firmware_display.asm]
2024-02-23 fixed corruption and line seq
    [firmware.asm, firmware_display.asm]
2024-02-23 Switched off keyboard diags
2024-02-27 wire up cf card (but that didnt work) and code up a simple spi bit bash to test serial eeprom
2024-02-28 pi spi code working
2024-02-28 generating spi protocol but not writing
2024-02-28 generate same spi stream for both the pico and z80 to compare
2024-02-28 had wrong pins and so not writing
    [firmware_spi.asm]
2024-03-01 print free mem
2024-03-02 fixed trailing spaces in input scanning
    [firmware.asm]
2024-03-03 Correct effects of emit keyword
    [forth_words.asm]
2024-03-03 get rid of some fixed debug
    [firmware.asm]
2024-03-04 string sort of working. issue with space sep being picked up and multiple string porttions being pushed to stack. need a new tokeniser
    [firmware.asm, forth_words.asm]
2024-04-03 rework of parser again
    [firmware.asm]
2024-04-08 fixed crashes. was the strlent looking for double quote which wont be there for a string in testing. grrr
    [firmware.asm, forth_words.asm]
2024-04-08 strlent still a problem
    [firmware.asm]
2024-04-12 fix depth and add in =
    [forth_words.asm]
2024-04-12 fixed some constants and words
    [firmware.asm, firmware_maths.asm, forth_words.asm]
2024-04-12 fix min and max
    [firmware.asm, forth_words.asm]
2024-04-14 try and resolve broken word linked list on new uword
    [firmware.asm]
2024-05-03 Word created correctly and picked up by tok parser
    [firmware.asm, forth_words.asm]
2024-05-03 version 4 of the parse to get rid of the extra pc and simplyfiy the flow
2024-05-08 removed some debug bugs
    [firmware.asm]
2024-05-09 Firmware v1.0 completed with minimal FORTH
    [case1-Case.step, case1-Case.stl, case1-CaseBase.stl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]
2024-05-10 full keyboard matrix now updating correctly
    [firmware.asm]
2024-05-13 Keyboard working and spi command to poke spi eeproms working
2024-05-13 Set a couple of words for direct serial eeprom use just in case
2024-05-16 need to fix dir. strange malloc issue
    [firmware.asm, firmware_seeprom.asm]
2024-05-21 rework of input using display buffer
    [firmware.asm]
2024-05-21 moving cursor but broken - strange bug
    [firmware.asm]
2024-05-22 insert text
2024-05-30 tidy up and add a couple more words
2024-05-31 Make running program use a different frame buffer between cli ops
2024-06-01 malloc throwing odd errors. not sure if leaking. guard functions an issue though
    [firmware.asm]
2024-06-05 An attempt with my own malloc. Currently adds ok. Free appears to work too.
2024-06-06 Fixed OPEN to store max file extent and then limit on read. OPEN now pushes max extents
    [firmware.asm, forth_words_storage.asm]
2024-06-06 Work on my own MALLOC. Added proper forward linked list to enable extra space as seem to have a zero index count issue on ldir use
    [case4.FCStd]
2024-06-06 PCB Keyboard now remapped
2024-06-06 Need to design new case
2024-06-07 Mega v1 case CAD design
    [megav1-Back.stl, megav1-KeyBoardRiser.stl, megav1-KeyboardRight.stl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]
2024-06-07 some slower individual prints
    [megav1.FCStd]
2024-06-08 Almost there with the case
    [megav1-NewBasePanelSection.stl, megav1-PCBFoot.stl, megav1.FCStd]
2024-06-09 updates and typo
    [megav1-KeyBoardRiser.stl, megav1-NewBasePanelSection.stl, megav1-keyboardlcdleftpillar.stl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]
2024-06-11 Mega case prototype finished
    [megav1-BoxLid.stl, megav1-BoxPanelRight.stl, megav1-KeyboardBezelLeft.stl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]
2024-06-13 Update LCD bezel
    [megav1-LcdBezel.stl, megav1.FCStd]
2024-06-13 Fixed LIST and LOAD. Currently fixing file ops
    [forth_words_storage.asm]
2024-06-13 Fixed extent checks on OPEN and READ
    [forth_words_storage.asm]
2024-06-18 SPI words using SE SPI interface and not general SPI protocol
2024-06-20 SPI fixing for ext devices
    [forth_words_device.asm]
2024-06-23 Test coding and wiring for AY sound chip via Pico
2024-07-24 Some storage word issues
    [forth_words_storage.asm]
2024-07-28 Mark bugs in editor
    [firmware_diags.asm]
2025-01-01 switched back to my malloc
2025-01-07 Switch to de88 malloc as mine has a free bug
    [firmware.asm]
2025-01-08 switch DIRLIST word to use a simple list
2025-01-11 Start on rework of SCROLL word
    [firmware_display.asm]
2025-01-12 CPM stub assembles but still need BIOS entry points
2025-01-13 Add a extra level of delay in case of CPU running CPM is a bit quick
2025-01-29 Reverted to previous storage format as most issues may have been hardware stability issues rather than coding
    [firmware.asm, forth_words_storage.asm]
2025-01-29 Still some storage stability issues, could be malloc still
    [firmware.asm, forth_words_storage.asm]
2025-01-31 Some fixes for file system words
    [firmware.asm, forth_autostart.asm, forth_words_storage.asm]
2025-02-02 Added SP checking macros to locate strange crashes
    [main.asm]
2025-02-02 stack frame hunt
2025-02-03 Some of today's fixes
    [forth_autostart.asm]
2025-02-03 Track a score for numbers game
2025-02-05 Add menu code and replace the diags screen with it along with new settings etc
    [firmware_diags.asm, firmware_display.asm, main.asm]
2025-02-07 Auto load from file loading but crashes on return from function
    [firmware_diags.asm]
2025-02-07 Still got a strange crash. might need to see if a stack issue
    [firmware_diags.asm, main.asm]
2025-02-08 Might have fixed EDIT
    [firmware.asm]
2025-02-09 Fixed crash on invalid file id for ERA, OPEN, APPEND
    [forth_words_storage.asm]
2025-02-10 pico spi networking code
2025-02-11 Add a build time to rom which can be updated at burn time
    [main.asm]
2025-02-23 Crash on READ past eof
    [firmware.asm, forth_autostart.asm, forth_words_storage.asm]
2025-03-04 docs and added FILEADDR for current address on READ
2025-03-09 Step towards using pico
2025-03-14 Mega v2 case base model
    [batteryholder-Fusion.stl, batteryholder.FCStd, megav2-LeftSide.stl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]
2025-03-20 New case
    [megav2-BatteryHolder.stl, megav2-LeftSide.stl, megav2-NewLid.stl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]
2025-03-21 Finished base mega v2 case
    [megav2-Back.stl, megav2.FCStd]
2025-03-21 Add delay to CARTDEV SPI comms and do base SPI Net code for the pico
2025-03-22 SPI Net is working
2025-03-22 some more SPI Net fixes
    [forth_autostart.asm, forth_words_device.asm, picospinet.py]
2025-04-02 Looks like I never inclueded the schematics for the machine!
2025-04-13 SPI networking hub on pico
2025-04-13 remodel spi net for multiplexing clk pulses
2025-04-25 should be clocking out
    [megav2-NewLid.stl, megav2.FCStd]
2025-06-15 New pico net
2025-06-15 pico net can send and receive spi data
2025-06-15 pico net string store
2025-06-15 pico net stored string get and put working
2025-06-17 some spi words to make things easier
2025-06-17 SPI echo back working via the spichat command
2025-07-03 Fixed .> as using wrong reg pair
    [firmware.asm]
2025-07-04 Schematics for PicoSPINet v1
2025-07-07 Add support for emulating Microchip EEPROM storage on PicoSPINet. Currently a single common store. To add node specific and banks storage
2025-07-07 A file storage word LABELS is the only word not compatible with the PicoSPINet
    [forth_words_storage.asm]
2025-07-13 Testing spi control of a sound chip
2025-07-13 Working on pin reduction to fit spi bus
2025-07-14 SPI Sound
2025-07-28 Sound card now working
    [boxv1-body.stl, boxv1-lid.stl, boxv1.FCStd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]
2025-07-29 Fixed lread on auto start
    [forth_startupv2.asm]
2025-08-03 Box for pispinet
    [box1-Body.stl, box1-Lid.stl, box1.FCStd]
2025-08-04 Added PCB for sound + backplane + cat5
2025-08-05 Added free memory count after uword load. But it appears inverted. Using wrong pointers
    [main.asm]
2025-08-05 Fixed inverted free bytes
    [main.asm]
2025-08-06 added timestamp to build and fixed a couple of bugs
    [main.asm]
2025-08-06 Added socket access on picospinet
2025-08-08 Rework of editor. basic append, insert and delete. Need to add guards, remove trailing rubbish on delete and extra keys
    [firmware.asm]
2025-08-11 Added assemble of three different debug code levels
2025-08-11 Prep for stack op fixes
    [firmware.asm, main.asm]
2025-09-19 SPI and other utils
    [megav2.FCStd]
2026-04-29 Adding tape support. Device is on bus via port 00h and is sending correctly. Currently working on playback detection of the pulse length
    [firmware.asm, forth_autostart.asm, forth_words_const.asm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]
2026-05-01 Added tape testing and calibration words to help creation of the playback circuit
2026-05-04 Added pulse counts for 1 and 0 instead of time based. Made tape test and calibration words nicer
2026-05-04 A quick stub for a buzzer for later
    [firmware.asm, forth_words_device.asm]
2026-06-13 595 shift reg support on any OUT device
2026-06-13 case LED under user control
2026-06-16 v4.5 main board upgrade - tape, sound, and ESP32 support
2026-06-16 Draft SPI protocol for the ESP
2026-06-18 Switch from ESPForth to Arduino IDE
2026-06-20 Sort out uwords for esp spi pools
2026-06-21 Added saving of device type to aid esp switching
2026-06-21 moved save/rest of device so i can add a config output to send dot via esp uart
2026-06-21 Note where dot intercept for uart output can go
2026-06-27 Case changes and some ESP code
    [megav4.5.FCStd]
2026-06-28 Main part of case for 4.5
    [megav4.5-leftside.stl, megav4.5-lid.stl, megav4.5-rightside.stl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]
2026-07-11 Clean up
    [megav4.5-back-bottom.stl, megav4.5-batteryholder.stl, megav4.5-keyboardpillar.stl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]
2026-07-11 Possible fix for LED word
    [forth_words_device.asm]
2026-07-12 MENU improved, though still a couple of bugs but much better feel
    [firmware.asm, firmware_display.asm]
2026-07-15 left in debugging on esp and needed to fix some backup words
    [esp-z80.ino, forth_autostart.asm]
2026-08-29 More on the esp, web upload now works but really broken the main core moving the web server out to a command. need to rework the whole thing really as the op code processing needs to change for var b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
    [esp-z80.ino]
2026-09-04 Moved stuff around. Appears we have a final SPI handshake state issue. Occasional bit not in sync with byte end
    [esp-z80.ino]
